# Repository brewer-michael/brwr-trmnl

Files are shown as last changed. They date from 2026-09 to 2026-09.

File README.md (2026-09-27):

# brwr-trmnl

**A 10.3" e-paper display for the fridge door, run by Home Assistant. Say
"show the calendar on the fridge" to your voice speaker, and it does.**

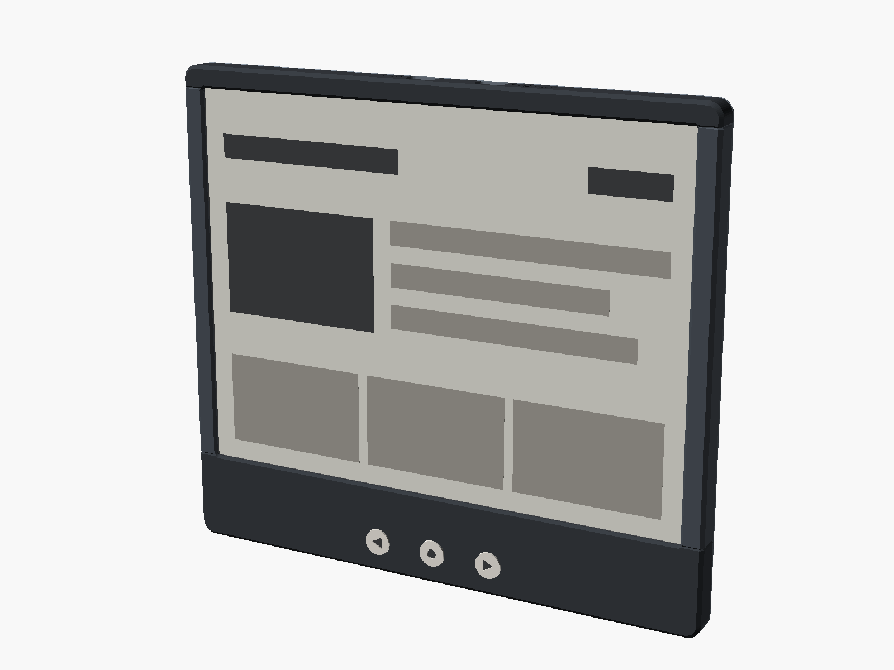
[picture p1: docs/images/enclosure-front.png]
Render of the brwr-trmnl enclosure: a 10.3-inch e-paper panel in a printed frame with three buttons below it


[TRMNL](https://trmnl.com) makes calm, low-power e-paper displays and
publishes its [firmware](https://github.com/usetrmnl/trmnl-firmware) and
[server API](https://docs.trmnl.com/go/diy/byos) so you can build and host
your own. brwr-trmnl is the large-format version (the TRMNL X's panel size
and resolution) built from parts you can buy anywhere, in a 13 mm thin
3D-printed frame that holds onto the fridge with magnets. Its firmware has Home Assistant
built in, so your screens and commands stay on your own network. (It does
reach a public time server to set its clock, unless you point the setup
page's NTP server field at a local one.)

- **10.3", 1872 × 1404, 16 grays.** Sharp enough for small text,
  calendars and graphs at 227 dpi.
- **Three buttons, no touchscreen:** back, refresh and next, like a TRMNL.
  Presses are also Home Assistant triggers.
- **Lives on the fridge.** Four magnets hidden in the back, steel-backed,
  placed and checked so their field stays clear of the electronics
  ([magnets.md](docs/magnets.md)). Or stand it on a desk, or hang it on a
  steel plate on the wall.
- **13 mm thin** (the TRMNL X is 12), stiffened by epoxied steel rods, and
  it prints on a 220 × 220 mm bed.
- **Home Assistant built in.** One setup page. It appears as an MQTT device
  with its battery, what's on screen, a screen picker and settings.
- **Voice.** Any Home Assistant voice satellite (the open speaker, a Voice
  PE, your phone) can put a screen or a note on the fridge.
- **Your screens:** Home Assistant dashboards rendered for e-paper, or
  TRMNL's plugins and playlists from the self-hosted
  [Terminus](https://github.com/usetrmnl/terminus) server. No cloud account.
- **Weeks to months per charge** (estimated), depending on how quickly you
  want it to react ([power.md](docs/power.md)). USB-C charging.
- **About $240 in parts,** $157 of it the display.

## How it works

```
 Voice speaker ──► Home Assistant ─────────────────────────────┐
 "show the         Assist → script → MQTT                      │ MQTT: commands, settings
  calendar on      TRMNL HA add-on: dashboards → 16-gray PNG   │ ◄── state, battery, buttons
  the fridge"      Terminus add-on: TRMNL plugins, playlists   │
                          │ image                              │
                          ▼                                    ▼
                   brwr-trmnl: XIAO ESP32-S3 ──► IT8951 HAT ──► 10.3" e-paper
                   (sleeps between refreshes; the panel's supply is switched off)
```

The brain is an ESP32-S3 (a Seeed XIAO ESP32-S3), the same chip as in the
TRMNL X. The 10.3" panel comes as a kit with Waveshare's IT8951 driver
board, which is shaped as a Raspberry Pi "HAT", but there's no Pi here: the
driver is only the panel's controller and power supply, and the ESP32-S3
talks to it over SPI. (The TRMNL X drives its panel directly from the
ESP32-S3 on a custom board instead.)

Each refresh, the display wakes, switches on the 5 V supply to the panel's
IT8951 controller, fetches the current screen, draws it at 16 grays, reports
to Home Assistant over MQTT and goes back to sleep. In **Always ready** mode
it stays connected in light sleep between refreshes, so a voice command
is on screen in about 10–15 seconds; in **Deep sleep** it only checks in when
it wakes, and the battery should last months.

## Build one

| | |
|---|---|
| [Bill of materials](docs/bom.md) | Parts, suppliers and prices ([CSV](hardware/bom.csv)) |
| [Build guide](docs/build-guide.md) | Printing, soldering, flashing and assembly, step by step |
| [Wiring](hardware/wiring.md) | Pin map, [schematic](docs/images/schematic.svg), [wiring](docs/images/wiring.svg), [carrier board](docs/images/carrier-layout.svg) and [button board](docs/images/button-board.svg) layouts |
| [Enclosure](hardware/enclosure/README.md) | Parametric OpenSCAD frame, 229 × 204 × 13 mm, in four print jobs on a 220 × 220 mm bed: STLs, print settings, rod cut list, desk stand |
| [Magnets](docs/magnets.md) | Holding force, and why the magnets don't disturb the electronics |
| [Power](docs/power.md) | Battery life, power modes, charging |
| [Home Assistant](docs/home-assistant.md) | Add-ons, setup, entities, screens, MQTT topics |
| [Voice](docs/voice.md) | Voice commands through Home Assistant Assist |

## Buttons

| | TRMNL server | Home Assistant screens |
|---|---|---|
| **BACK** | The previous image (from the display's cache, instant) | The previous screen |
| **REFRESH** | Fetch now (the playlist moves on) | Redraw the current screen |
| **NEXT** | The next playlist item | The next screen |
| **REFRESH** double press | TRMNL's special function | — |
| Any button, long press (1–5 s) | Only a Home Assistant trigger, for your own automations | same |
| **REFRESH**, hold 5 s | Setup hotspot, for Wi-Fi and Home Assistant. It forgets the saved Wi-Fi, so you pick it again; the other settings stay | same |
| **REFRESH**, hold 15 s (let go within 30 s) | Reset: forget Wi-Fi, the server and the Home Assistant connection. Set it up again with the same broker and the settings you made in Home Assistant come back | same |

Short and double presses also reach Home Assistant as triggers. Set
**Buttons** to *Home Assistant only* and every press is yours to automate
(setup and reset still work). In **Deep sleep**, though, any press also
wakes the display, which then refreshes as it would on its timer. A button
held down for more than 30 seconds counts as stuck: it's ignored, stops
waking the display, and shows up as **Last error** in Home Assistant until
the first refresh after it's released.

## Firmware

A fork of [usetrmnl/trmnl-firmware](https://github.com/usetrmnl/trmnl-firmware),
imported into [`firmware/`](firmware/) with `git subtree`. The changes are
listed in [`firmware/BRWR.md`](firmware/BRWR.md). In short:

- a `brwr_trmnl` board for the XIAO ESP32-S3 and the Waveshare IT8951 HAT
  over SPI, using upstream's IT8951 driver for the reTerminal E1003 (the same
  1872 × 1404 panel)
- three buttons, a switched panel supply and a battery voltage reading
- Home Assistant over MQTT: discovery, state, settings, commands, button
  triggers, and **Always ready** light sleep
- Home Assistant screens rendered by the TRMNL HA add-on, as an alternative
  to a TRMNL server
- the Home Assistant fields on the setup page

It still works with TRMNL's cloud or any other TRMNL-compatible server. CI
builds both firmware variants whenever `firmware/` changes. Flash the
`brwr_trmnl` one: its `merged_firmware.bin` goes at `0x0` for the first
flash (it clears saved Wi-Fi and settings); to update, upload with
PlatformIO or write `firmware.bin` at `0x10000`.

```sh
cd firmware
pio run -e brwr_trmnl -t upload
```

## Repository

| Path | |
|---|---|
| [`firmware/`](firmware/) | trmnl-firmware with the `brwr_trmnl` board ([changes](firmware/BRWR.md)) |
| [`homeassistant/`](homeassistant/) | Package (screens, scripts, voice intents), voice sentences, example fridge dashboard |
| [`hardware/enclosure/`](hardware/enclosure/) | OpenSCAD source, export script, STLs |
| [`hardware/diagrams/`](hardware/diagrams/) | Scripts that draw the schematic and wiring diagrams |
| [`hardware/analysis/`](hardware/analysis/) | Magnetic field model behind [magnets.md](docs/magnets.md) |
| [`hardware/bom.csv`](hardware/bom.csv), [`hardware/wiring.md`](hardware/wiring.md) | Parts and wiring |
| [`docs/`](docs/) | Build guide and reference |

## Status

**Designed, not yet built.** What has been checked so far:

- The firmware builds for both variants in CI. It has not run on hardware
  yet.
- The Home Assistant package's templates, and the voice sentences against
  Home Assistant's sentence matcher.
- The enclosure renders, its parts are manifold and fit a 220 × 220 mm bed,
  and its clearances (every layer of the 13 mm stack, the magnets, the rods,
  the antenna's keep-out) are checked by assertions in the OpenSCAD source.
- The magnetic field numbers come from a model of a bare magnet (worse
  than the real, steel-backed one).

The battery life, the IT8951's current draw, the magnets' grip on a real
fridge door, the print tolerances, the heights of the parts on a real HAT,
charger module and MiniBoost, and the length of the kit's 40-pin flat cable
are estimates or unknowns until someone builds one. If you do, please open
an issue with what you find.

## Credits

[TRMNL](https://trmnl.com) for the device, the firmware and the server API;
[Terminus](https://github.com/usetrmnl/terminus) and
[trmnl-home-assistant](https://github.com/usetrmnl/trmnl-home-assistant) for
the self-hosted server and the Home Assistant add-ons;
[FastEPD](https://github.com/bitbank2/FastEPD) for the IT8951 driver. This is
an independent project, not affiliated with TRMNL.

## License

GPL-3.0, the same as the TRMNL firmware it's based on. See [LICENSE](LICENSE).

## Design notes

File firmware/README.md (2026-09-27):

# TRMNL Firmware

created for the [TRMNL](https://trmnl.com) e-ink display.

> [!NOTE]
> **brwr-trmnl:** apart from this note, this is TRMNL's own README. For the
> brwr-trmnl board (building, flashing, and what changed) see
> [BRWR.md](BRWR.md). TRMNL's Flash Assistant and released images are built
> for TRMNL's devices, not for this hardware.

> [!IMPORTANT]
> the `main` branch is under constant development and may contain breaking changes. flash at your own risk.
>
> to access production-ready firmware, check out the [tagged releases](https://github.com/usetrmnl/trmnl-firmware/releases/)
 or use the [Flash Assistant](https://trmnl.com/flash).
## **Algorithm block scheme**

```mermaid
graph TB

    Start(["Start"])
    Init("Init peripherals")
    Start --> Init

    IsLongRst{"Reset button
      pressed > 5000 ms?"}
    Init --> IsLongRst

    ClearWifi("Wi-Fi credentials clear")
    IsLongRst -->|"Yes"| ClearWifi
    DisplayInit("Display init")
    IsLongRst -->|"No"| DisplayInit
    ClearWifi --> DisplayInit
    WakeReason{"Wake by
      user or timer?"}
    DisplayInit --> WakeReason

    ClearDisplay("Display clear")
    WakeReason -->|"User"| ClearDisplay
    IsWiFiSetup{"Wi-Fi saved?"}
    WakeReason -->|"Timer"| IsWiFiSetup
    ClearDisplay --> IsWiFiSetup
    NeedConfig("Show set-up message")
    IsWiFiSetup -->|"No"| NeedConfig

    %% Config Wifi
    RunSetup("Start config portal")
    NeedConfig --> RunSetup
    IsReset1{"Device
      reset?"}
    RunSetup -->|"Yes"| IsReset1
    WipeConfig1("API key, friendly ID and WiFi clear")
    IsReset1 -->|"Yes"| WipeConfig1
    Reboot1(["Reboot"])
    WipeConfig1 --> Reboot1
    IsWifiConnect{"WiFi
      connected?"}
    IsReset1 -->|"No"| IsWifiConnect

    %% Main Body
    TryConnect{"WiFi connected
      (5tries)?"}
    IsWiFiSetup -->|"Yes"| TryConnect

    ConnectError("Show connection error")
    IsWifiConnect -->|"No"| ConnectError
    TryConnect -->|"No"| ConnectError
    Sleep1(["Sleep"])
    ConnectError --> Sleep1
    ClockSync("Check synchronization")
    IsWifiConnect -->|"Yes"| ClockSync
    TryConnect -->|"Yes"| ClockSync
    IsApiSetup{"API key and
      friendly ID exist?"}
    ClockSync --> IsApiSetup

    %% Setup
    CallSetup("Ping /api/setup")
    IsApiSetup -->|"No"| CallSetup
    IsSetupSuccess{"Setup
      success?"}
    CallSetup --> IsSetupSuccess
    SetupError("Show setup error")
    IsSetupSuccess --> SetupError
    Sleep2(["Sleep"])
    SetupError --> Sleep2

    %% Check update
    PingServer{"Ping server,
      success?"}
    IsApiSetup -->|"Yes"| PingServer
    IsSetupSuccess -->|"Yes"| PingServer
    PingError("Show server error")
    PingServer -->|"No"| PingError
    Sleep3(["Sleep"])
    PingError --> Sleep3

    %% Act on update
    IsNeedReset{"Need to reset
     the device?"}
    PingServer -->|"Yes"| IsNeedReset
    IsNeedReset -->|"Yes"| WipeConfig1
    IsNeedUpdate{"Need to update?"}
    IsNeedReset -->|"No"| IsNeedUpdate
    IsNeedUpdate -->|"No"| Sleep3
    Update("Download and update")
    IsNeedUpdate -->|"Yes"| Update
    Update --> Sleep3
```

## **Web Server Endpoints**

following Wifi connection via the captive portal, device swaps its Mac Address for an API Key and Friendly ID from the server (which get saved on device).

```curl
GET /api/setup

headers = {
  'ID' => 'XX:XX:XX:XX:XX' # mac address
}

response example (success):
{ "status": 200, "api_key": "2r--SahjsAKCFksVcped2Q", "friendly_id": "917F0B", "image_url": "https://trmnl.com/images/setup/setup-logo.bmp", "filename": "empty_state" }

response example (fail, device with this Mac Address not found)
{ "status" => 404, "api_key" => nil, "friendly_id" => nil, "image_url" => nil, "filename" => nil }
```

assuming the Setup endpoint responded successfully, future requests are made solely for image / display content:

```curl
GET /api/display

headers = {
  'ID' => 'XX:XX:XX:XX',
  'Access-Token' => '2r--SahjsAKCFksVcped2Q',
  'Refresh-Rate' => '1800',
  'Battery-Voltage' => '4.1',
  'FW-Version' => '2.1.3',
  'RSSI' => '-69'
}

response example (success, device found with this access token):
{
  "status"=>0, # will be 202 if no user_id is attached to device
  "image_url"=>"https://trmnl.s3.us-east-2.amazonaws.com/path-to-img.bmp",
  "filename"=>"2024-09-20T00:00:00",
  "update_firmware"=>false,
  "firmware_url"=>nil,
  "refresh_rate"=>"1800",
  "reset_firmware"=>false
}

response example (success, device found AND needs soft reset):
{
 "status"=>0,
 "image_url"=>"https://trmnl.s3.us-east-2.amazonaws.com/path-to-img.bmp",
 "filename"=>"name-of-img.bmp",
 "update_firmware"=>false,
 "firmware_url"=>nil,
 "refresh_rate"=>"1800",
 "reset_firmware"=>true
}

response example (success, device found AND needs firmware update):
{
 "status"=>0,
 "image_url"=>"https://trmnl.s3.us-east-2.amazonaws.com/path-to-img.bmp",
 "filename"=>"name-of-img.bmp",
 "update_firmware"=>true,
 "firmware_url"=>"https://trmnl.s3.us-east-2.amazonaws.com/path-to-firmware.bin",
 "refresh_rate"=>"1800",
 "reset_firmware"=>false
}

response example (fail, device not found for this access token):
{"status"=>500, "error"=>"Device not found"}

if 'FW-Version' header != web server `Setting.firmware_download_url`, server will include absolute URL from which to download firmware.
```

if device detects an issue with response data from the `api/display` endpoint, logs are sent to server.

```curl
POST /api/log

# example request tbd
```

## **Power consumption**

A bit of background first. The ESP32-C3 inside the TRMNL OG is one of Espressif's newer, more efficient microcontrollers. For battery powered applications, it's designed to be put to sleep to conserve power when your project doesn't need it to be active. There are two sleep modes - light and deep. Deep sleep conserves the most power, but at the cost of losing the contents of the main memory. The lowest possible power consumption is about 4uA @ 3V with a timed wakeup, but TRMNL needs to be able to wake up with a button press. Keeping the GPIO active during deep sleep (to detect the button press) uses about 100uA on average (see power profile below). This means that a 2500mAh battery could theoretically keep the TRMNL powered in this state for approximately 25,000 hours.

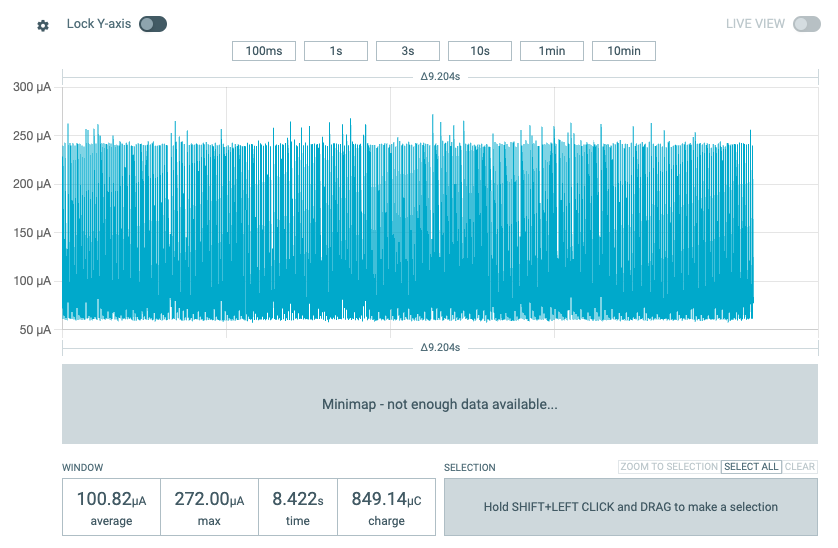
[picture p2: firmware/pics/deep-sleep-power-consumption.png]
TRMNL deep sleep power consumption


Of course its not very useful to have a device that's permanently sleeping, so shown below is the power profile of TRMNL doing a normal display update (timed wake up, send device status, fetch new image, show it on the e-paper display):

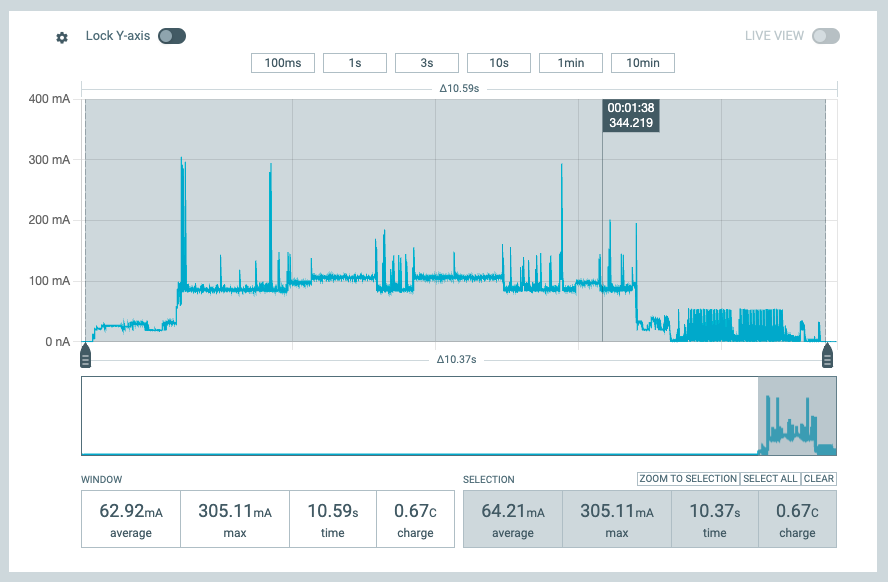
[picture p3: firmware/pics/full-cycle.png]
TRMNL device full cycle power consumption


The peaks and valleys you see above represent the variation in electrical current (power) drawn by the ESP32-C3 at different points during the ~10.5 second update cycle. The majority of energy is used while WiFi is active (between the 3 and 9 second marks). The last portion of the graph with higher frequency peaks is from the e-paper display cycling through its update (average power is quite low). The total electrical charge needed for the update is shown in the lower right corner (0.67c). This value is in Coulombs and represents the number of electrons that have moved through the circuit.

0.67 C = 0.186111 mAh

If we ignore the ESP32 sleep periods, the energy used in each display update would allow 2500/0.186111 = 13433 updates. If we configure our TRMNL account to update the information every 15 minutes, we'll be requesting 96 updates per day and the battery charge could last for 140 days (13433 / 96). This isn't too far off from real world results. The battery voltage will drop below a safe threshold before it has released its full energy and in the equation above, we haven't counted the energy used during the sleep periods nor the energy lost in the TRMNL's power supply (between the battery and the ESP32). The real world result will be closer to 120 days on a full charge.

We can extend the battery life further by disabling updates during our sleeping hours. In the TRMNL web portal there is a setting for “Sleep Mode” (see screenshot below):

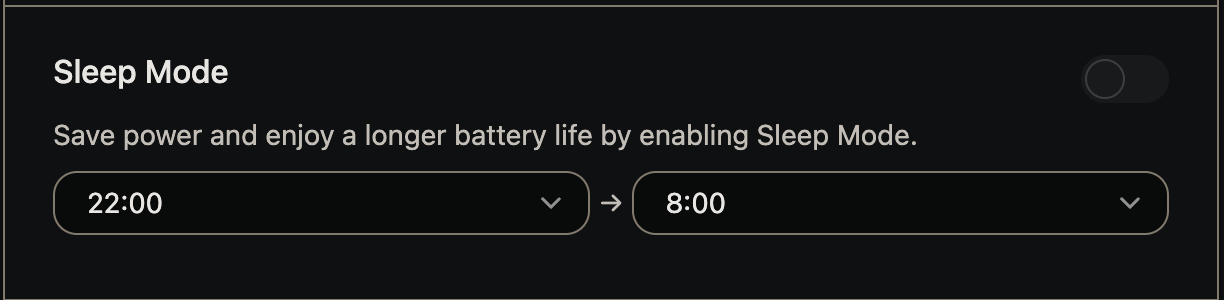
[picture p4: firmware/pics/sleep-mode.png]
TRMNL sleep mode


For example - by reducing the total active time each day by 8 hours, the number of updates per day (set to a 15-minute interval like above) changes from 96 to 64. With sleep mode set to 8 hours, our battery life is extended:

13433 / 64 = 210 days (theoretical maximum)

**Designed for Efficiency**

Lithium batteries deliver between 3.7 and 4.2 volts depending on their charge state. The ESP32 operates between 2.8V and 3.3V. In order to power the ESP32 from the battery, the voltage needs to be reduced.

There are two main types of power regulators - [buck](https://en.wikipedia.org/wiki/Buck_converter) converters, and [linear](https://en.wikipedia.org/wiki/Linear_regulator) regulators. Many ESP32 products use linear regulators since they are less expensive. This savings comes at a cost - they throw away up to 20% of the battery's energy as waste heat. Your TRMNL was designed with a buck converter to safely and efficiently power the ESP32. This ensures the best use of the battery's energy. At TRMNL we are always looking for additional software optimizations that improve battery life.

## **Low Battery Level**

Lithium ion batteries are ubiquitous in our lives; they're in nearly everyone's pocket/purse and many other devices you use daily. They bring a host of benefits, some risks and require care to keep them working at their best. Your TRMNL protects the battery against overcharging, but your help is needed to prevent problems when the battery is low. There are two main problems that arise with dead Li-Ion batteries:

1. If they pass below a certain voltage, they need to be recharged with a special trickle charger; the charging circuit of the TRMNL won't be able to charge them.
2. Batteries that are left uncharged for an extended period of time can “outgas”. This means that the electrolyte goes through a chemical reaction and releases hydrogen gas. You may have seen batteries in this state - the metal envelope puffs up like a balloon.

The conditions above are to be avoided, but `#2` can be dangerous as well. If your battery is puffy, dispose of it safely at a local recycling spot and contact TRMNL support to get a new one.

Even when your TRMNL is disconnected (power switch in the off position), its battery will slowly self-discharge. To keep your TRMNL's battery running at peak performance:
1. Charge your device immediately when the low battery image is shown.
2. If you've switched off your TRMNL for storage/moving, ensure the battery is not already low.

## **Version Log**

See [releases](https://github.com/usetrmnl/firmware/releases). For older versions go [here](https://github.com/usetrmnl/firmware/issues/95).

## **Compilation guide**

There are technical and non-technical options to flashing firmware.

### **No code required**

* Flash directly from a web browser: https://trmnl.com/flash
* Enable OTA updates from your TRMNL dashboard > Device settings (native hardware only)

### **Via CLI**
1. To build the binary run `pio run -e TRMNL_X_dev`
2. To upload the binary to the device `pio run -e TRMNL_X_dev -t upload`
3. If PlatformIO uses the wrong port use this
```bash
pio device list # make sure JTAG device is visible
pio run -e TRMNL_X_dev -t upload --upload-port /dev/cu.usbmodem1234
```
4. view serial monitor by
```bash
pio device monitor -e TRMNL_X_dev
pio device monitor -e trmnl
```

When switching between TRMNL X and OG/BWRY, run `pio pkg install` once for the environment you are about to build (use the same `-e` value as `pio run`):

```bash
pio pkg install -e TRMNL_X_dev   # TRMNL X
pio pkg install -e trmnl         # TRMNL OG
pio pkg install -e trmnl_4clr    # TRMNL BWRY
```

If you skip this step, the build may fail with `Error: Missing Arduino framework directory 'None'`.

### **Using VSCode plugin**

1. Install VS Code: https://code.visualstudio.com
2. Install PlatformIO: https://platformio.org/install/ide?install=vscode
3. Install Git: https://git-scm.com/book/en/v2/Appendix-A%3A-Git-in-Other-Environments-Git-in-Visual-Studio-Code
4. Clone this repository: https://github.com/usetrmnl/trmnl-firmware
5. Open project in VS Code workspace
6. After configuring the project, click the PlatformIO -> Build button located at the bottom of the screen

Image Alt text Build

7. After the compilation process is complete, you should expect to see a message in the console.

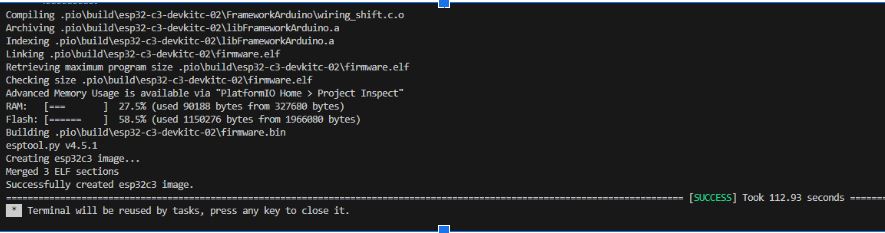
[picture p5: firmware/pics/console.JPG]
Image Alt text Console


8. You can find the compiled file in the folder shown in the picture.

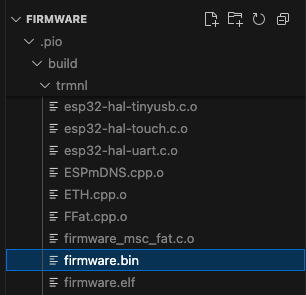
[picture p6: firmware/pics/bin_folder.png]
Image Alt text Bin


## **Uploading guide (PlatformIO)**

1. Put the TRMNL into flashing mode.

    1. **TRMNL OG and BWRY**: Turn off PCB. Connect PCB to PC using USB-C cable. While holding down the boot button, turn on PCB. Let go of boot button. This puts board in flashing mode.
    2. **TRMNL X**: [See these instructions](https://help.trmnl.com/en/articles/11936721-put-your-trmnl-in-flashing-mode#h_96e07a072e)

2. Mac/Windows: Select the proper COM port from drop-down list (or leave on "Auto"). Ubuntu: Look for something like "/dev/ttyACMO USB JTAG/serial debug unit" or "Espressif USB JTAG/serial debug unit" via lsusb.

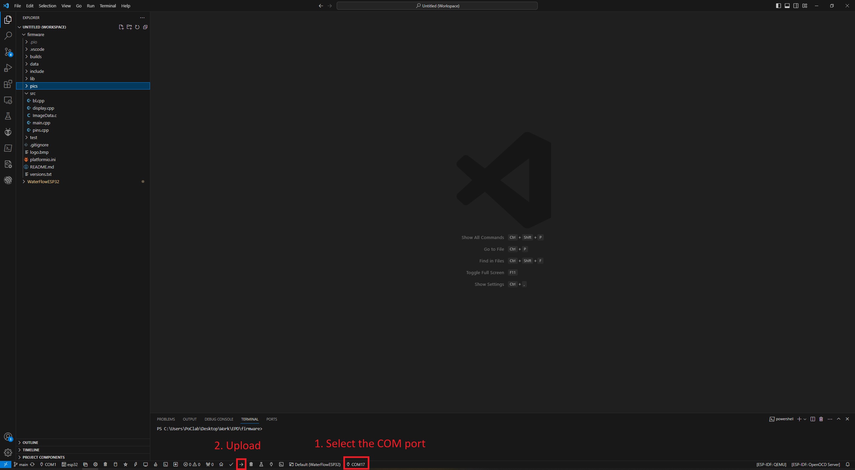
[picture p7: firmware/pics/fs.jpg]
Image Alt text FS


3. Click on "PlatformIO: Upload" button.

## **Uploading guide (ESP32 Flash Download Tool)**

Tools required:

1. Windows OS
2. Flash Tool 3.9.5
3. Binaries to merge - `bootloader.bin`, `firmware.bin`, `partitions.bin` (see Compilation Guide above)
4. Bootloader binary file (`boot_app0.bin`, found in ~/.platformio/packages/framework-arduinoespressif32/tools/partitions/)

### Step 1 - Configure flash tool
open the Flash Tool (executable file), select these parameters, then click OK:

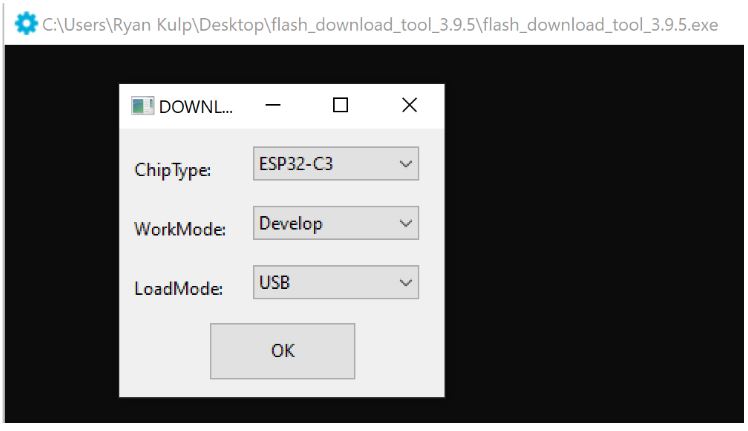
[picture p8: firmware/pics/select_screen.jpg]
Image Alt text select screen


### Step 2 - Add binaries
1. Beside the top blank space, click “...” dots and select the bootloader binary file then input
> “0x00000000”
in the far right space and check the box.

2. Click “...” dots and select the partitions binary file then input
> “0x00008000”
in the far right space and check the box.

3. Click “...” dots and select the boot_app0 binary file then input
> “0x0000e000”
in the far right space and check the box.

4. Click “...” dots and select the firmware binary file then input
> “0x00010000”
in the far right space and check the box.

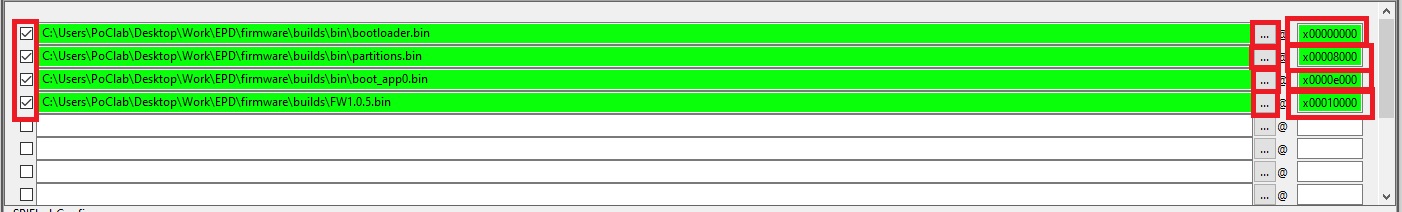
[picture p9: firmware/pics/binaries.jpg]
Image Alt text binaries


finally, set the following parameters at the bottom of the Flash Tool interface:

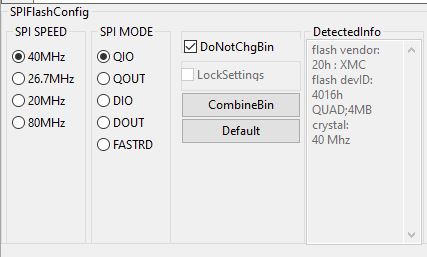
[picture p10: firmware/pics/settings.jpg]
Image Alt text settings


### Step 3 - Connect and flash device
1. Open the Windows “Device Manager” program and scroll to the bottom where the USB devices can be found. each machine will have different available devices, but look for a section like this:

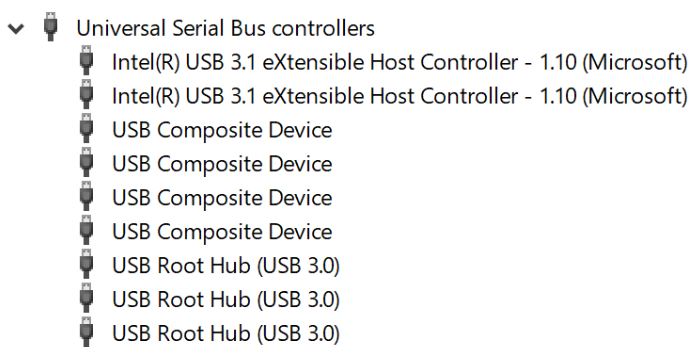
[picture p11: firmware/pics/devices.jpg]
Image Alt text devices


2. Next, connect the PCB to the Windows machine with a USB-C cable. make sure the USB port is on the right, and that the PCB’s on/off switch is toggled DOWN for “off.”

3. While holding the BOOT button (below the on/off toggle), toggle the device ON by flipping the above switch UP. you may hear a sound from your Windows machine Inspect the Device Manager connections at the bottom of the interface, and a new device should appear. it may be “USB Component {{ Num }},” or something like below:

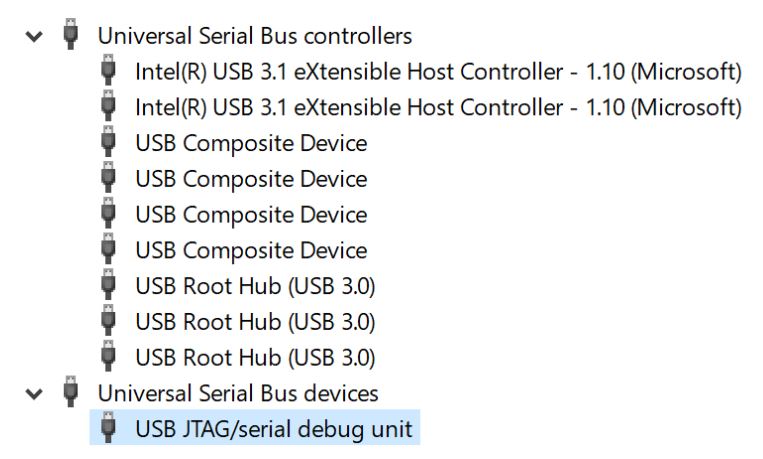
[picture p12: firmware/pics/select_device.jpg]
Image Alt text select_device


4. Take note of this device’s name, that is our TRMNL PCB. then back inside the Flash Tool, click to open the “COM” dropdown in the bottom right and choose the TRMNL PCB. finally, click the “START” button.

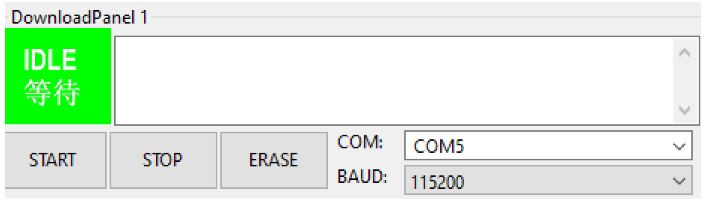
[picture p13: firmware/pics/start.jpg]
Image Alt text start


### Step 4 - Prepare for new device flashing
Inside the Flash Tool click the “STOP” button.

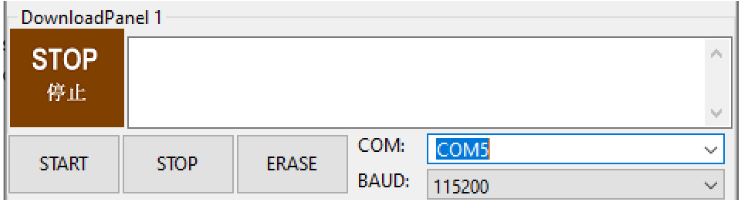
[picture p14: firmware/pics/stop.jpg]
Image Alt text stop


Next turn off (toggle DOWN) and unplug the PCB. you are now ready to flash another device - see Step 1.

## **Hacking guide**

### Local unit tests

If you would like to run local tests, you'll need to have g++/gcc installed (f.e., as part of MinGW) in PATH:

- Get MinGW online installer from https://github.com/niXman/mingw-builds-binaries/
- Add path to `bin` from installed folder (f.e. `c:\mingw64\bin`) to your PATH
- Restart Visual Studio Code

Now you can switch from "env:esp32..." to "esp:native" clicking at the bottom of the studio (point 1):



And then run platformio tests by clicking test button (point 2).

### Hardware integration tests

There is a suite of on-device hardware tests written with the [Unity](https://registry.platformio.org/libraries/throwtheswitch/Unity) test framework, defined in `test/integration/test_all`. They compile into a single firmware image that is uploaded to the device, runs the tests sequentially in `setup()`, and prints results over the serial port.

To run the test suite (currently only on OG):

1. Make a copy of `test/integration/test_config.h.example` to `test/integration/test_config.h` and modify the file as needed to set up the WiFi network and other values. This file is ignored by Git and will not be checked in.
2. Select the `env:trmnl_test` environment.
3. Plug in the device and run the "PlatformIO: Test" action.
    1. If the upload fails, retry the Test action once.
    2. If the upload still fails, ensure the device is on.
    3. If the upload still fails, put the device into flashing mode - see "Uploading guide (PlatformIO)" above, and retry.

You should see terminal output like:

```
test/integration/test_all/all.test.cpp:33: connect_to_wifi      [PASSED]
test/integration/test_all/all.test.cpp:75: test_setup_succeeds_with_registered_mac      [PASSED]
test/integration/test_all/all.test.cpp:76: test_setup_returns_status_error_for_unknown_mac      [PASSED]
test/integration/test_all/all.test.cpp:77: test_setup_fails_with_unreachable_host       [PASSED]
test/integration/test_all/all.test.cpp:97: test_low_battery_returns_low_battery_image   [PASSED]
test/integration/test_all/all.test.cpp:63: test_wifi_connects_with_valid_credentials    [PASSED]
test/integration/test_all/all.test.cpp:64: test_wifi_fails_with_wrong_password  [PASSED]
test/integration/test_all/all.test.cpp:65: test_wifi_fails_with_wrong_ssid      [PASSED]
---------------------------------------------------------------------------- trmnl_test:integration/test_all [PASSED] Took 56.49 seconds ----------------------------------------------------------------------------

====================================================================================================== SUMMARY ======================================================================================================
Environment    Test                  Status    Duration
-------------  --------------------  --------  ------------
trmnl_test     integration/test_all  PASSED    00:00:56.488
```

## Code Formatting

We use `clang-format` for formatting C/C++ source files. You can install it [via Homebrew](https://formulae.brew.sh/formula/clang-format) or your package manager of choice - it's part of `llvm`.

Two ways to format files:

1. Run `./scripts/format.sh` to format the entire repository.
2. VS Code users: install [the C/C++ extension](https://marketplace.visualstudio.com/items?itemName=ms-vscode.cpptools) which will automatically format-on-save using clang-format.

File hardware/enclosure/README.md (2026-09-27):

# brwr-trmnl enclosure

A thin printed frame for the 10.3" panel: 229 × 204 × 13 mm, plus the 1 mm
rubber pads on the back and caps 0.5 mm proud. The **bezel** holds the front
face, walls, panel pocket and buttons. The **back cover** carries the
electronics, the ribs that press the panel forward and four N52 disc magnets
sealed inside it. Steel rods epoxied into printed channels stiffen the thin
frame and splice the split parts. The frame sticks to a fridge door, to a
steel plate on a wall, or leans back 15° in the optional desk stand.

| Front | Back |
|---|---|
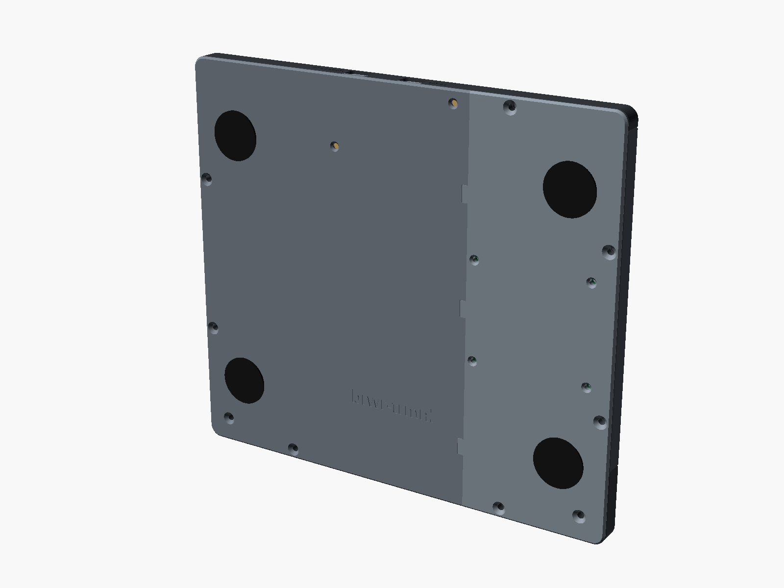
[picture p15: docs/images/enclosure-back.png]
Back
| Front |  |
| **Exploded** | **Inside, back cover removed (seen from behind, so left and right are swapped)** |
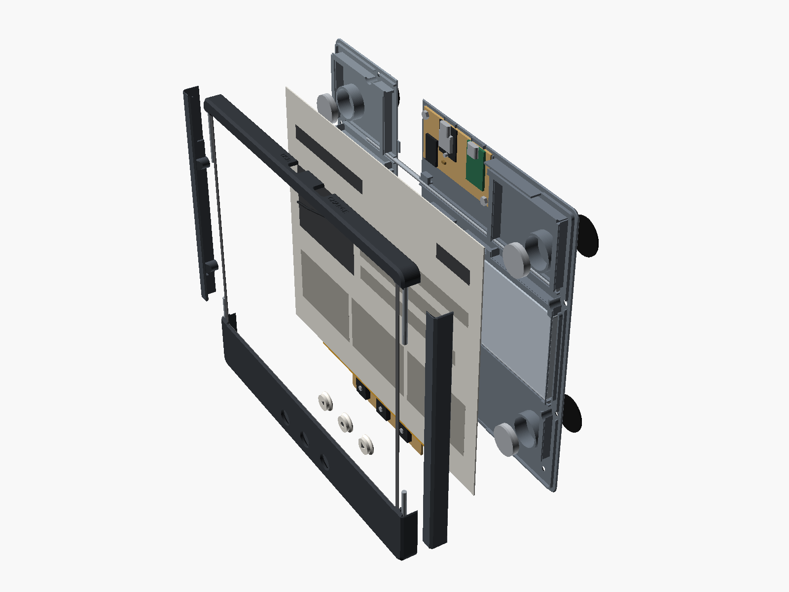
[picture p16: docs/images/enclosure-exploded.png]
Exploded
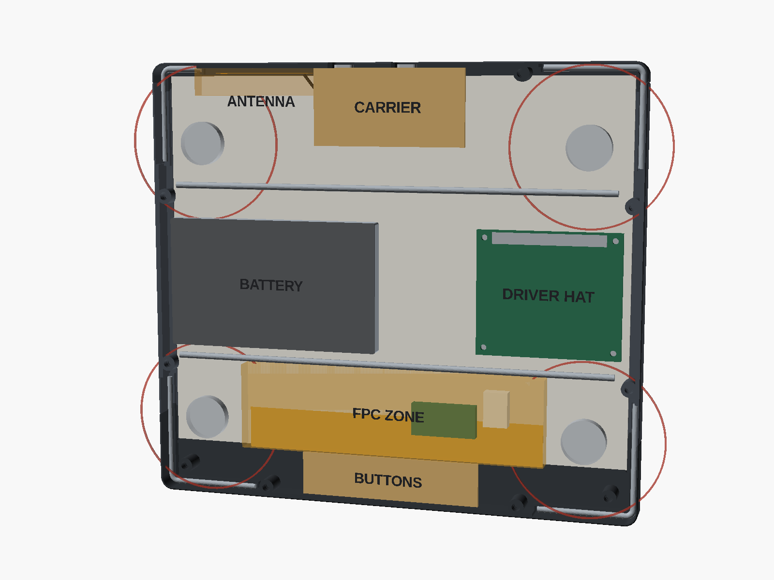
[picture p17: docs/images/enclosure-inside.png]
Inside
|  |  |

The whole design is one parametric file, [`brwr-trmnl.scad`](brwr-trmnl.scad).
Running [`./export.sh`](export.sh) renders the STLs into `stl/` and these
pictures into `docs/images/`. It stops on any OpenSCAD warning, including a
failed design-rule check. It also stops on any STL that, once vertices closer
than 1e-4 mm are merged the way a slicer does, has an edge not shared by
exactly two triangles or a degenerate triangle.

## Parts

By default every part fits a **220 × 220 mm bed** (FlashForge Adventurer 5M)
with 5 mm margins. The bezel comes in four rails that meet at the window
corners. The back cover splits at X = −39.

| Part | File | Print orientation | Footprint on the bed | Size as printed | Mass |
|---|---|---|---|---|---|
| Top rail | `stl/bezel_top.stl` | front face down, turned 45° | 168 × 168 mm | 166 × 166 × 11.2 mm | ~10 g |
| Chin (bottom rail) | `stl/bezel_bottom.stl` | front face down, turned 45° | 188 × 188 mm | 186 × 186 × 11.2 mm | ~25 g |
| Left and right rails | `stl/bezel_left.stl`, `stl/bezel_right.stl` | front face down | 9.3 × 158 mm | 9.2 × 157.6 × 11.2 mm | ~8 g each |
| Back cover, left | `stl/back_left.stl` | outside face down | 77.5 × 204 mm | 77.5 × 204 × 9.4 mm | ~42 g |
| Back cover, right | `stl/back_right.stl` | outside face down | 154.5 × 204 mm | 154.5 × 204 × 10.0 mm (the antenna fin) | ~67 g |
| Button caps (3) | `stl/button_caps.stl` | face down | 48 × 13 mm | 48.2 × 13.4 × 4.1 mm | ~2 g |
| Desk stand (optional) | `stl/stand.stl` | base down | 100 × 79 mm | 100 × 78.8 × 73.6 mm | ~70 g |

The STLs are already in print orientation, including the 45° turn. The
footprint is what the bed-fit check measures: the rails' rounded outline,
turned. The model refuses a part that does not fit `bed_size` minus
`bed_margin`.

For a bed of **250 × 210 mm or more**, print the one-piece bezel and back
cover instead: `stl/one-piece/bezel.stl` (229 × 204 × 11.2 mm, ~51 g) and
`stl/one-piece/back.stl` (229 × 204 × 10.0 mm, ~109 g). `export.sh` renders them
with `split = false`. They carry the same grooves, bosses and rod channels.

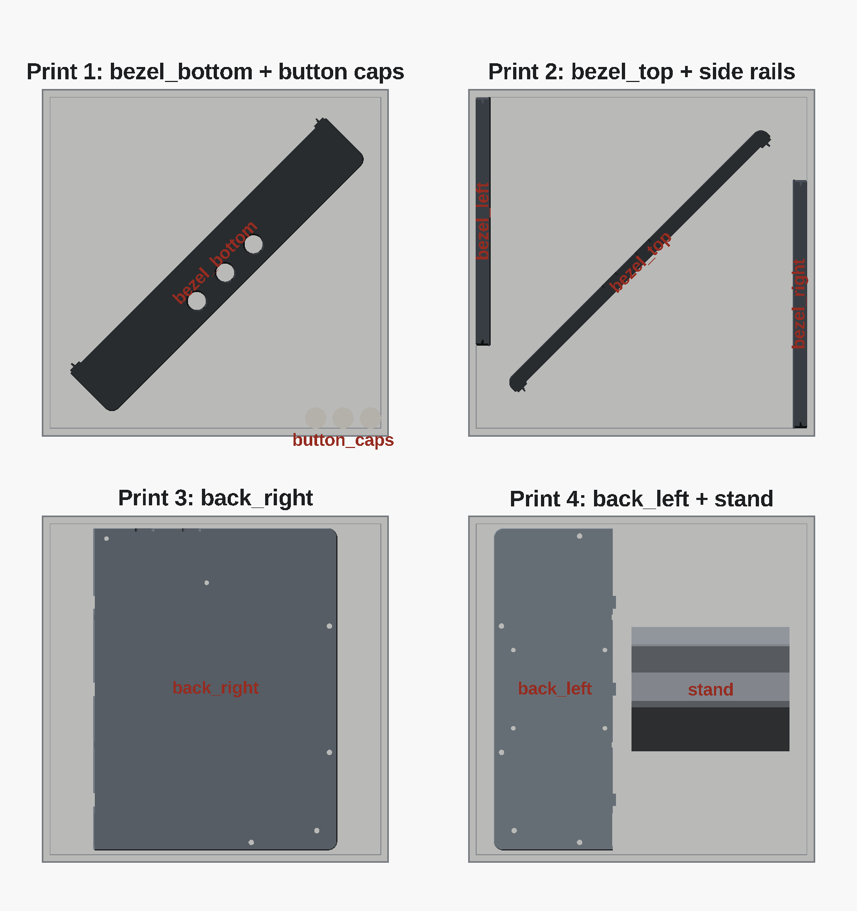
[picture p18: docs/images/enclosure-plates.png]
Print jobs


Four print jobs on a 220 × 220 bed:

1. `bezel_bottom`, turned 45°, and the button caps
2. `bezel_top`, turned 45°, with `bezel_left` and `bezel_right`
3. `back_right`
4. `back_left` and the stand

Print in **PETG with 0.2 mm layers, 3–4 walls and 20 % infill, with no
supports**. Every overhang is 45° or bridged. That includes the rail scarfs,
the 45° fronts of the bosses behind the panel, the tab pockets and the cap
flanges. The bezel parts print on their front face, so use the sheet whose
finish you want on the front.

Masses are for PETG at 1.27 g/cm³: the STL volume, with a 1.2 mm solid shell
on every surface and 20 % infill inside it. At 13 mm deep everything is thin
wall, so it prints almost solid.

## Hardware

- **Screws**
  - 9 × M3 heat-set inserts, 4 mm long (hole Ø4.0 × 4 mm), in the bezel.
    Use 9 × M3 × 6 countersunk screws (ISO 10642) through the back cover.
  - 4 × M2.5 × 8 countersunk screws and 4 × M2.5 nuts for the driver HAT.
    The screws go in from outside, the nuts sit on the component side.
  - 2 × M2.5 × 6 countersunk screws and 2 × M2.5 nuts for the carrier board.
  - 2 × M2.5 heat-set inserts (hole Ø3.6 × 4.2 mm) behind the chin and
    2 × M2.5 × 5 pan-head screws for the button strip.
- **Magnets**
  - 4 × N52 disc magnets, 20 × 3 mm
  - 4 × steel discs, 20 × 1.5 mm
  - 2-part epoxy
  - 4 × self-adhesive rubber pads, Ø25 × 1 mm
- **Steel:** about 0.75 m of 3 mm mild steel rod (see the cut list below).
- **Switches:** 3 × Omron B3F-4000 (12 × 12 × 4.3 mm, flat plunger) on an
  84 × 20 mm protoboard strip, 25.4 mm (10 holes) apart.
- **Button lead plug:** a pre-wired 4-pin JST-PH pair, inline in the button
  lead, so the frame and the back cover come apart. It lies flat on the back
  cover beside the adapter board, centred at (−50, −53) (`btn_plug_pos`), and
  the clash check includes it.
- **Antenna:** Taoglas FXP831 (45 × 7 mm FPC, 100 mm of 1.37 mm coax, U.FL),
  on a fin on the back cover.
- **Foam:**
  - a 0.5 mm gasket on the window lip
  - 1 mm × 4 mm strips on the rib tops and the magnet tubes
  - a 0.5 mm pad under the battery
- **Zip ties:** 2.5 mm, for the button wires, through the three tie blocks at
  X = −30.
- **Glue (optional):** for the rail joints and the back seam. Use epoxy, or CA
  with a primer made for PETG.

### Steel rod cut list

| Rod | Shape | Straight lengths (mm) | Cut length |
|---|---|---|---|
| Back cover, upper (Y = 45.5) | straight | 206 | 206 mm |
| Back cover, lower (Y = −35.3) | straight | 206 | 206 mm |
| Bezel, top-left | L | 40 along the top wall + 40 down the side wall | 85 mm |
| Bezel, top-right | L | 15.5 along the top wall + 40 down the side wall | 61 mm |
| Bezel, bottom-left and bottom-right (2) | L | 40 along the bottom wall + 48 up the side wall | 93 mm each |

The bezel grooves follow the frame's rounded corner. Bend the L-rods 90° with
an inside radius of 1.3–1.9 mm, for example over a Ø3 mm pin in a vise. The
top-right rod's top leg is short so it stays 10 mm from the antenna. The
console prints this list (`CUT` lines) and asserts the rod rules:

- at least 8 mm from each rod to a magnet's edge (the upper back rod sits at
  exactly 8 mm)
- at least 10 mm to the antenna
- nothing in the flex zone (1.6 mm to spare)

## Z stack-up at 13 mm

Z is measured from the back face (the fridge side). These are the tightest
spots. The console prints them as `STACK` lines.

| Spot | Layers, Z in mm | Margin |
|---|---|---|
| Panel | front plate 11.4–13, gasket 10.9–11.4, panel 10.12–10.9, rib tops 9.42 plus 0.7 mm of squeezed foam | – |
| Carrier | recess floor 0–0.6, solder joints 0.6–1.8, board 1.8–3.4, MiniBoost (5.6 mm, the tallest part) to 9.0 | 1.12 mm to the panel |
| Driver HAT | plate 0–1.8, clipped header pins 2.3–3.3, standoffs to 3.3, board 3.3–4.9, parts and nuts to 7.9, screw tips at 8.0 | 2.22 mm to the panel |
| Battery | recess floor 0–0.6, foam 0.6–1.1, cell 1.1–7.1 | 2.32 mm to the rib tops |
| Buttons | recess floor 0–1.0, joints 1.3–3.3, strip 3.3–4.9, switch body to 8.4, plunger to 9.2, 0.2 mm gap, cap 9.4–13.5, sleeve 10.2–11.4 | 0.3 mm above the recess floor; the switch clicks after 0.45 mm with the cap face 0.05 mm proud |
| Magnets | skin 0–0.6, magnet 0.6–3.6, steel disc 3.6–5.1, epoxy to 5.4, tube to 9.42; rubber pad −1–0 | 4.7 mm to the panel |
| USB slots | XIAO centre 6.0 (slot 2.75–9.25), charger centre 6.6 (slot 3.35–9.85) | 1.65 mm below the front chamfer |
| Antenna | 3.0–10.0 on a fin on the back cover, 2.4 mm inside the top wall, X 38–83 | 11.5 mm to the nearest metal part; the carrier board's copper is 3 mm from its end |
| Rods | bezel rods 8.2–11.2, beside the panel edge; back rods 0.8–3.8, a third sunk into the plate | – |

The console also prints what each stack needs as `DEPTH` lines. 13 mm closes.
The smallest depth that closes is **12.88 mm**, set by the carrier: the
MiniBoost, 5.6 mm tall (Adafruit's figure), with 1 mm of air to the panel.
The buttons come next, at 12.6 mm. The model refuses a `depth` that does
not close.

## Assembly

1. **Inserts.** Heat-set the nine M3 inserts into the bezel rails' bosses and
   the two M2.5 inserts into the bosses behind the chin.
2. **Magnets.** In each back-cover pocket, drop in a magnet, lay a steel disc on
   it, and fill with epoxy to just over the disc. Nothing metal shows outside.
   Stick a rubber pad over each pocket on the outside face.
3. **Back cover.** Lay `back_left` and `back_right` outside face down on a flat
   table. Slide the three tabs on `back_left` into the pockets under
   `back_right`, so the scarf closes. Epoxy the two 206 mm rods into their
   channels across the seam; they hold the halves together. Glue on the scarf
   is optional.
4. **Bezel.** Lay the four rails front face down on a flat table and push them
   together at the corners. Each side rail slides in along Y between the top
   rail and the chin. The scarf and the half-lap line up the front faces and
   the pocket ledge. Epoxy the four L-rods into the corner grooves; they bridge
   the joints and are structural. Glue on the joint faces is optional. Let it
   cure flat.
5. **Buttons.** Push the caps in from behind, with the key toward the bottom.
   Then screw the switch strip onto its two bosses (M2.5 × 5).
6. **Panel.** Lay the gasket on the lip and drop the panel in face-down, with
   its flex at the chin. Fold the flex over the back of the panel. The zone
   144 × 40 mm above the panel's bottom edge is kept free of ribs and rods.
7. **Electronics.**
   - **Driver HAT:** remove its 2×20 header, clip the pins flush (≤ 1 mm) and
     remove the tall socket and pin headers. Mount it component side toward
     the panel on its four 1.5 mm standoffs, with M2.5 × 8 countersunk screws
     from outside and nuts on the component side.
   - **Carrier:** trim its joints to 1.2 mm. It rests on the two ledges of its
     recess and is held by M2.5 × 6 countersunk screws from outside, nuts on
     top. Its two holes are drilled 2.7 mm through the middle of the four
     holes in its top-left and bottom-right corners (components facing you),
     so they sit on the protoboard's grid: X ±31.75 mm, 4.15 mm and 32.09 mm
     below the top of its 70 × 35 mm outline. A notch in the left ledge clears
     the MiniBoost's VIN joint.
   - **Battery:** on its foam pad in the cradle recess, lead out through the
     slot toward the middle and through the gap in the rib above, to J1.
   - **Antenna:** stick it to the inner face of the fin along the back
     cover's top edge (X 38–83), and run its coax over the carrier to the
     XIAO's U.FL. It stays connected when the case is opened: only the
     panel's flat cable and the button lead (J4) cross between the halves.
8. **Close up.** Put foam strips on the rib pads and the magnet tubes, plug
   the button lead together and lay its plug flat beside the adapter board,
   tie the button wires up the back at X = −30, and close the case with the
   nine M3 screws. The two tongues on the back cover close the bottom of the USB
   slots.

**On a wall:** the back is too thin for keyholes. Screw a thin steel plate to
the wall, for example 1 mm galvanised steel of about 200 × 150 mm, or four
30 × 30 mm squares at the magnet positions (±90, ±65) from the frame's
centre. The magnets hold the frame on it.

## How the joints go together

- **Rail joints (bezel).**
  - Each joint runs level with the window's top or bottom edge (Y = 92.9 and
    Y = −64.7).
  - On the front it is a short line across the side border. It sits in a
    0.5 mm V-groove that continues over the front chamfer and down the side
    wall, so it reads as a deliberate line.
  - Through the front plate the joint is a 45° scarf. In the side wall, the
    outer half is cut straight and the inner half runs 4 mm further (a
    half-lap).
  - The rails register on each other and every rail prints face-down without
    supports.
  - The L-rods in the wall grooves bridge all four joints. The nearest other
    feature is 2.6 mm from a joint.
- **Back seam (X = −39).**
  - A 45° scarf through the plate, with 0.4 mm lands.
  - Three 2 × 8 × 0.8 mm tabs on `back_left` (at Y = −70, 0 and 55) slide
    into bridged pockets under `back_right`.
  - Both back rods cross the seam.
  - Clearances from the seam: 2.0 mm to the HAT standoffs, 1.5 mm to the HAT
    board edge and its countersinks, 2.4 mm to the carrier tray and 5 mm to
    the tie blocks.

## Changing the main parameters

Open the file in OpenSCAD and use the Customizer. Each dimension has a
comment with its unit and source. The console prints every module's position,
the stack-up, the magnet and rod distances and the rod cut list. The model
also runs `assert()` design rules and stops with a message when one fails.

- **Depth:** `depth`, `front_t` and `back_t`. The `DEPTH` lines say which
  stack sets the minimum.
- **Bed:** `bed_size`, `bed_margin` and `split`. `rail_angle` turns the long
  rails. `plate_layout()` places the parts of each print job and is checked
  for fit and spacing.
- **Magnets:** `mag_d`, `mag_h`, `steel_disc` and `mag_pos`, with one `[X, Y]`
  per magnet; the count is the number of entries. The rules are:
  - every centre is at least `mag_keep_board` (36 mm) from the driver and
    carrier boards, and at least `mag_keep_ant` (30 mm) from the antenna
  - magnets stay out of the flex zone and the battery cradle
- **Rods:** `rod_back_y`, `rod_back_x` and `rod_legs`. The rules are
  `rod_mag_clear`, `rod_ant_clear` and the flex zone.
- **Battery:** `bat_size = [L, W, T]` in landscape, and `bat_pos` for its
  centre.
- **Button feel:** `cap_preload` defaults to −0.2 mm, a free gap above the
  plunger, because the switch only travels 0.25 mm. Raise it toward 0 if the
  caps rattle. Lower it if a switch clicks by itself when the case is closed.

Use `part = "fit_check"` to see all module envelopes and rods inside a
see-through case. Use `part = "clash"` to render every overlap between two
printed parts, or between a printed part and a module's envelope or a rod.
It is empty when everything fits, and OpenSCAD reports "top level object is
empty". Modules aren't checked against each other, and cables aren't
modelled, apart from the antenna's coax (for its length) and the button
lead's plug.

Coordinates follow the front view: X and Y are measured from the centre of the
outline (+X right, +Y up). Z is measured from the back face (the fridge side)
toward the front.

## Differences from the brief

- **Depth is 13 mm.** The first pass was 25 mm deep. The HAT lost its header,
  the carrier went low-profile and the switches went flat (see the stack-up).
- **9 M3 screws, not 10.** The L-rods take the corners of the top rail and the
  chin. There are only 3.35 mm between the pocket and the wall there, which is
  no room for both a rod and an insert.
  - The chin's corner screws moved in to (±101.5, −89.5).
  - The top rail has one screw at (−60, 97). There is none at the top right,
    because of the antenna keep-out.
  - The epoxied L-rods hold the top rail's corners.
- **The upper back rod is at Y = 45.5, not 46.** That keeps 8 mm from the rod
  surface to the magnet edge. The lower rod is at −35.3, centred between the
  battery cradle and the flex zone.
- **Two L-rods have different legs.** The top-right rod's top leg is 15.5 mm,
  to keep 10 mm from the antenna. The bottom rods' side legs are 48 mm, so they
  reach 17 mm past the joint.
- **The rod grooves are cut into the walls.** Along each bezel rod the wall is
  a 1 mm skin, and 0.5 mm under the joint's V-groove.
- **Some ribs changed.**
  - The rib at Y = −35 is gone; the lower rod runs there.
  - The bottom perimeter ribs are gone. The magnet tubes run up to the rib
    tops and carry foam instead.
  - The perimeter ribs moved 2.7 mm inside the panel edge to clear the rod
    grooves.
- **The M3 bosses reach under the panel's edge.** There they end
  0.3 mm behind the panel with a 45° front, so they print without supports.
- **The window chamfer is 1.1 mm,** to fit the 1.6 mm front plate.
- **The USB labels sit beside the slots.** There is no room above them in a
  13 mm wall.
- **Keyholes are removed.** The back is too thin; use a steel plate on the wall
  instead.
- **Two small features moved for the button strip's recess.** The logo moved
  to Y = −58, and the lowest zip-tie block is gone.
- **Screws and buttons sit on the protoboards' 2.54 mm grid,** so they can be
  drilled where the grid says rather than measured.
  - The carrier's screws are in the middle of its corner squares of four
    holes, at X ±31.75, 4.15 and 32.09 mm below its top edge (brief ±30;
    first pass 5 and 31 mm). A 2.7 mm drill centres itself there.
  - The strip's screws are its holes at X ±36.83 (brief ±38).
  - The buttons are 25.4 mm (10 holes) apart (brief 26).
  - A notch in the carrier's left ledge clears the MiniBoost's VIN joint,
    which lands on the ledge.
  - The XIAO's USB slot is at X −7.62, on the carrier's grid (brief −8).
- **The antenna is on a fin on the back cover,** not in a recess in the top
  wall. On the wall, its 100 mm coax couldn't reach the XIAO while the case
  was open, so it could only be plugged in blind. On the fin, the antenna and
  the XIAO are on the same part; it sits 2.4 mm inside the wall and 1.4 mm
  further back, still standing on edge away from the door. The magnet rule
  for it is 30 mm (was 35): a steady field doesn't affect an antenna, and the
  magnets' metal is kept 10 mm away like any other. The coax notch in the
  top rib is 4 mm deep (brief 3) for its lower feed.
- **The carrier sits 0.2 mm lower** (0.6 mm of plate under its recess) to
  fit the MiniBoost, which is 5.6 mm tall, not the 5 mm first assumed.
- **The interior rib at Y = 36 has a second gap** for the battery lead and
  its plug, at X 1–13; the HAT's wires share the wire passage with the
  button lead.
- **Kept from the first pass:**
  - magnets at (±90, ±65) under a 36 mm board rule (the brief had ±58 and
    30 mm)
  - a cap preload of −0.2 mm (a gap)
  - the cap keyway
  - USB slots open toward the back edge and closed by tongues
  - the engraved logo
  - the 144 mm flex relief

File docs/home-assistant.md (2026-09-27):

# Home Assistant

brwr-trmnl talks to Home Assistant over MQTT. It appears as a device with
sensors, controls and button triggers, and it takes commands: show this
screen, post this note, next screen. Voice commands are those same commands
said out loud ([voice.md](voice.md)).

```
  Home Assistant                                            brwr-trmnl
  ┌───────────────────────────────────────────┐   MQTT     ┌──────────────┐
  │ Mosquitto broker  ◄────────────────────────┼──────────► │ state, button│
  │                                            │  commands  │ triggers     │
  │ Terminus add-on :2300  (TRMNL plugins,     │  ◄──────── │ GET screen   │
  │   playlists)                               │   image    │              │
  │ TRMNL HA add-on :10000 (dashboards → PNG)  │  ──────►   │ 1872 × 1404  │
  │ packages/brwr_trmnl.yaml (screens, scripts,│            │ 16 grays     │
  │   voice intents)                           │            │              │
  └────────────────────────────────────────────┘            └──────────────┘
```

## 1. Add-ons and integrations

| What | Why | Where |
|---|---|---|
| **Mosquitto broker** add-on + the **MQTT** integration | The device's connection to Home Assistant | Settings › Add-ons › Add-on store |
| **Terminus** add-on (port 2300) | TRMNL's plugins and playlists, served locally. Needed for the "TRMNL server" source | Add-on repository [`https://github.com/usetrmnl/trmnl-home-assistant`](https://github.com/usetrmnl/trmnl-home-assistant) |
| **TRMNL HA** add-on (port 10000) | Renders Home Assistant dashboards as 16-gray PNGs. Needed for "Home Assistant screens", and for voice/notes | same repository |

1. **Mosquitto**: install, start, then Settings › Devices & services › MQTT
   (Home Assistant offers it once the broker runs). Mosquitto accepts Home
   Assistant user logins: create a user such as `mqtt` (Settings › People ›
   Users, "Can only log in from the local network"; the Users tab needs
   **Advanced mode**, in your profile) and give the display that username and
   password.
2. **Add-on repository**: Settings › Add-ons › Add-on store › ⋮ ›
   Repositories, add `https://github.com/usetrmnl/trmnl-home-assistant`.
3. **Terminus**: install, set **Home Assistant IP** (`ha_ip`) to your Home
   Assistant's IP address, start, open the web UI and create an account. Terminus serves the device at
   `http://<ha-ip>:2300`; the display's setup page fills that in for you.
4. **TRMNL HA**: install, create a long-lived access token (your profile ›
   Security › Long-lived access tokens) and paste it into **access_token**.
   Turn on **keep_browser_open**: otherwise the add-on starts its browser
   again for each render, which you notice when you ask for a screen by
   voice. Port 10000 has no authentication, so keep it on your home network.
   The add-ons' own documentation is in
   [their repository](https://github.com/usetrmnl/trmnl-home-assistant).

## 2. Connect the display

Hold **REFRESH** for 5–15 s (or power it up for the first time). It forgets
its saved Wi-Fi networks and opens a Wi-Fi hotspot called
`brwr-trmnl-XXXXXX`. Join it; the setup page opens (or go to
`http://4.3.2.1`). Pick your Wi-Fi, then under **Home Assistant**:

- **Home Assistant address**: its IP address, e.g. `192.168.1.20`.
- **Screens come from**: *Terminus add-on* or *Home Assistant dashboards*.
  You can change this later in Home Assistant.
- **MQTT username / password**: the user from step 1.
- **Panel VCOM**: the voltage printed on the panel's ribbon cable, e.g.
  `-1.52`. A wrong value gives a washed-out picture. You can change it later.

Tap **Connect**. The device should appear within a minute under Settings ›
Devices & services › MQTT as **brwr-trmnl xxxxxx**: the same six characters as
the hotspot, in lower case, which are also its MQTT id
(`brwr-trmnl/a1b2c3/...`). Rename it ("Fridge") if you like.

With Terminus as the source, open the Terminus web UI: the display should
register there when it first connects. It reports itself as a TRMNL X
(model `x`), so Terminus sends it 1872 × 1404 screens in 16 grays. Give it a
playlist. (This hasn't been tried on real hardware yet.)

## 3. The device in Home Assistant

| Entity | Type | What it does |
|---|---|---|
| Battery | sensor | Estimated charge, % |
| Battery voltage | sensor (diagnostic) | Resting voltage at the last wake |
| Wi-Fi signal | sensor (diagnostic) | RSSI at the last wake, dBm |
| Last refresh | sensor (diagnostic) | When the panel last changed |
| Showing | sensor | What's on screen: "Playlist", a screen name, "Battery empty"… |
| Last error | sensor (diagnostic) | Why the last refresh failed, if it did |
| On screen | image | The last image drawn, by its URL. Home Assistant loads the URL itself, so for a dashboard screen it shows a fresh render |
| Screen | select | Pick a screen. "Playlist" goes back to the schedule |
| Image source | select (config) | TRMNL server, or Home Assistant screens |
| Power mode | select (config) | Always ready, or Deep sleep ([power.md](power.md)) |
| Buttons | select (config) | *Change screens* (they also fire triggers), or *Home Assistant only* |
| Refresh interval | number (config) | Minutes; 0 = automatic (the server's rate, or 30 min for Home Assistant screens) |
| Hold commanded screen | number (config) | Minutes a commanded screen stays before the schedule resumes |
| Panel VCOM | number (config) | Volts, as printed on the ribbon cable |
| Refresh, Next screen, Previous screen | buttons | Same as the physical buttons |
| BACK / REFRESH / NEXT: short, double, long press | device triggers | For automations |

In **Deep sleep** the display only checks in when it wakes, so a change you
make in Home Assistant shows up at the next refresh (or press any button). In
**Always ready** it should land within about 15 seconds (an estimate).

## 4. Home Assistant screens

The TRMNL HA add-on turns a dashboard view into the exact image the panel
wants. The device asks for
`http://<ha>:10000/<path>?viewport=1872x1404&dithering&dither_method=floyd-steinberg&palette=gray-16&format=png`.

1. **Make a dashboard for the fridge.** Settings › Dashboards › Add dashboard
   › *New dashboard from scratch*, titled **Fridge display**, not in the
   sidebar. Its URL becomes `fridge-display`, which every screen's path
   starts with (with Advanced mode on, the dialog shows the URL).
   Open it › ✎ › ⋮ › *Raw configuration editor* and paste
   [`homeassistant/dashboards/fridge-display.yaml`](../homeassistant/dashboards/fridge-display.yaml).
   Replace the example entity ids with yours.
2. **Install the package.** Copy
   [`homeassistant/packages/brwr_trmnl.yaml`](../homeassistant/packages/brwr_trmnl.yaml)
   into `<config>/packages/` and make sure `configuration.yaml` loads packages:

   ```yaml
   homeassistant:
     packages: !include_dir_named packages
   ```

   Restart Home Assistant. On start it publishes the screen list to every
   display (`brwr-trmnl/all/set/screens`). After editing the list, reload
   scripts (Developer tools › YAML › Scripts) and then run **Fridge display:
   publish screens**, or restart Home Assistant.
3. **Choose it.** Set **Image source** to *Home Assistant screens*, or keep
   the TRMNL server and use the screens for voice commands and notes only.

Tips for dashboards on e-paper:

- **Panel views** with a grid or stack card keep the layout fixed at any zoom.
- `?zoom=2` in a screen's path doubles the size of everything, which is
  about right for reading from a metre away at 227 dpi. The note screen uses 3.
- Plain black on white reads best. Avoid pale colors, thin fonts and
  animations: the panel shows 16 grays and only changes when a new image
  arrives.
- If a card loads late, add `&wait=1000` (milliseconds) to the path.

A screen can also be a full `http://` or `https://` URL instead of a
dashboard path:

- a ready-made 1872 × 1404 PNG, JPEG or BMP, such as one under
  `http://<ha>:8123/local/`. It's drawn at full size from the top-left
  corner, not scaled, and a PNG must be under 750 kB;
- any web page, rendered by the add-on in its generic mode:
  `http://<ha>:10000/?url=<page>&viewport=1872x1404&dithering&dither_method=floyd-steinberg&palette=gray-16&format=png`.

Anything that isn't a full URL is taken as a dashboard path. For a camera,
add a view with a picture-entity card to the fridge dashboard.

## 5. Scripts and commands

The package's scripts work from automations, the dashboard and voice:

| Script | Does |
|---|---|
| `script.brwr_trmnl_show` | `screen:` name, or `path:` / `url:` (+ `name:`), and optional `hold:` minutes |
| `script.brwr_trmnl_note` | Sets `input_text.brwr_trmnl_note` and shows the Note screen for 4 h |
| `script.brwr_trmnl_command` | `command: next`, `back` or `refresh` (refresh also ends a held screen) |
| `script.brwr_trmnl_publish_screens` | Publishes the screen list |

```yaml
# The doorbell rang: show the front door for 5 minutes (after adding a
# "doorbell" view, e.g. a picture-entity card of the door camera, to the dashboard)
- action: script.brwr_trmnl_show
  data:
    path: "fridge-display/doorbell?zoom=2"
    name: Doorbell
    hold: 5
```

They publish to `brwr-trmnl/all/...`, which every display listens to. Each
command there must carry `ts`, the time it was sent in epoch seconds: a
display acts on each timestamp once, ignores a command without one, and
skips one that went stale while it slept (a show after 15 minutes, or after
its hold; next, back and refresh after 5 minutes). Commands to one display's
own topics need no `ts`.

**MQTT topics**, for anything else (`<base>` = `brwr-trmnl/<last six hex
digits of the MAC, lower case>`):

| Topic | Direction | Payload |
|---|---|---|
| `<base>/status` | device → | `online` / `offline` (retained; offline is the last will) |
| `<base>/state` | device → | JSON: battery, voltage, rssi, refreshed, screen, showing, source, power, buttons, refresh, hold, vcom, held_until, error |
| `<base>/image` | device → | URL of the image on screen |
| `<base>/button` | device → | `back_short`, `refresh_double`, `next_long`, … |
| `<base>/set/source`, `power`, `buttons`, `refresh`, `hold`, `vcom`, `screens` | → device | settings (retained) |
| `<base>/set/screen`, `<base>/cmd`, `<base>/show` | → device | one-shot commands (retained until the device has handled them) |
| `brwr-trmnl/all/set/screens` | → all | `[{"name": "Calendar", "path": "fridge-display/calendar?zoom=2"}, …]` |
| `brwr-trmnl/all/show` | → all | `{"screen": "Calendar", "hold": 30, "ts": 1790424000}` or `"path"` / `"url"` + `"name"` |
| `brwr-trmnl/all/cmd` | → all | `{"cmd": "next", "ts": 1790424000}` |

## 6. Buttons in automations

The front buttons are device triggers: build one in the automation editor
(Settings › Automations › + › Device › your display), which fills in the ids
for you. A long press sends a trigger without changing the screen, so it's
free for your own use:

```yaml
triggers:
  - trigger: device
    domain: mqtt
    device_id: <your display>
    discovery_id: brwr_trmnl_a1b2c3 btn_refresh_long   # your display's id
    type: button_long_press
    subtype: button_2        # button_1 BACK, button_2 REFRESH, button_3 NEXT
actions:
  - action: light.toggle
    target:
      entity_id: light.kitchen
```

Set **Buttons** to *Home Assistant only* and short presses stop changing
screens too, so every press is yours. Holding REFRESH for 5 s (Wi-Fi setup)
or 15 s (reset) always works. That's in **Always ready**: in **Deep sleep**,
any press also wakes the display, which then refreshes as it would on its
timer.

## Troubleshooting

| Symptom | Check |
|---|---|
| Device never appears | MQTT user/password; the broker's log; the display's **Last error** once it does connect |
| **Last error**: "No screen called Calendar" | The name isn't in the published screen list: check `brwr_trmnl_publish_screens` (and the sentences file), reload scripts and run the script again |
| **Last error**: "Couldn't load Calendar (…, HTTP n)" | Open the screen's add-on URL in a browser; the path must match the dashboard URL and view path |
| Screen changes take minutes | Power mode is Deep sleep, or the display lost Wi-Fi (Wi-Fi signal sensor) |
| Washed-out picture | Panel VCOM |
| Entities "unavailable" | The display went offline unexpectedly (last will): battery, Wi-Fi or a crash |
| **Last error**: "Button stuck down" | A switch is pressed all the time (a cap or a solder bridge); it's ignored until released |

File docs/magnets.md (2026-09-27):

# Magnets: on the fridge, clear of the electronics

brwr-trmnl hangs on the fridge door by four magnets hidden inside its back
cover. Each is capped with a steel disc, which works like the cup of a pot
magnet: it turns the field towards the door and away from the electronics.
They should hold it through a slammed door (the estimate is below: test it
on yours), and they're far enough from the boards that their field doesn't
matter there.

## The magnets

Four **N52 neodymium discs, 20 × 3 mm**, each with a **20 mm steel disc**
(1–2 mm thick) on top.

- Each sits in a pocket that opens to the inside of the back cover, behind a
  0.6 mm skin of plastic. The steel disc goes on top, and epoxy fills the
  pocket to just over it. Nothing metal shows outside.
- A self-adhesive rubber pad (25 mm, 0.5–1 mm thick) over each one outside is
  all that touches the door: grip, and no scratches.
- They sit at the four corners of the back, at (±90, ±65) mm from the
  centre.
- The steel disc matters: a bare disc magnet sends as much field backwards
  (into the case) as forwards. The disc carries the back of the field round
  to the front, so the magnet grips harder and less of its field reaches the
  boards.

## Will it hold?

| | |
|---|---|
| brwr-trmnl, complete | about 0.45 kg (estimate: 160 g of printed case, 90 g battery, 80 g panel and HAT, 45 g of steel rod, 45 g magnets and discs) |
| One magnet on thick steel, touching | ~4.3–5.4 kg pull (the supplier's figure for a bare 20 × 3 mm N52 disc) |
| Four, on a fridge door (estimate) | ~4 kg pull, ~2.5 kg sideways |
| Margin (estimate) | ~5 × against sliding down, ~9 × against being pulled off |

The estimate allows for the 0.6 mm skin and the rubber pad (together they
roughly halve a disc magnet's pull), gains back some for the steel backing,
and takes a third of that for a fridge door's thin painted steel. Rubber on
paint gives the sideways grip. These are estimates: hang it, and open and
slam the door a few times with a towel on the floor below. Thinner (0.5 mm)
pads grip harder.

### Will it work on my fridge?

Test the spot with any fridge magnet first.

- **Many stainless-steel doors aren't magnetic** (austenitic stainless,
  such as 304, isn't). The sides of the same fridge are often painted steel
  and are.
- **Glass, wood or "panel-ready" fronts** aren't magnetic either.
- **No magnetic surface?** Stick a thin steel plate or two adhesive steel
  discs on it (sold for phone mounts and "magnetic mounting plates"), or use
  the printed desk stand. On a wall, screw up a steel plate
  ([build guide](build-guide.md#10-hang-it)).

## Why the magnets don't disturb anything

A magnet's steady field can only affect parts that are themselves magnetic.
In this design, that's the power **inductors**: the MiniBoost's on the
carrier board, and the ones for the panel's supplies on the driver HAT. A
strong enough field partly saturates an inductor's core and lowers its
current rating. Nothing else inside cares:

- **The e-paper panel** moves charged pigments with electric fields;
  magnetic fields don't affect it.
- **The ESP32-S3, its flash, the crystal, the battery** and the charger are
  not magnetic.
- There are no Hall sensors, reed switches, compasses or speakers.

So the design rule is simple: **keep every board at least 25 mm from a
magnet's edge**, where even a bare magnet (without its steel disc) produces
**under 5 mT**. That's about 1% of what a ferrite core saturates at, and a
hundred times the Earth's field. The enclosure's source enforces the rule
with `assert()`s on the actual positions (36 mm from each magnet's centre).

Magnet field versus distance: the sideways field is 2.4 mT at the closest board, 26.75 mm from a magnet's edge

| Distance | Sideways (mT) | Straight out (mT) |
|---|---|---|
| 5 mm | 59.1 | 128.7 |
| 10 mm | 18.5 | 62.0 |
| 15 mm | 8.4 | 30.5 |
| 20 mm | 4.6 | 16.4 |
| 25 mm | 2.8 | 9.6 |
| 30 mm | 1.8 | 6.0 |
| 40 mm | 0.9 | 2.8 |
| 50 mm | 0.5 | 1.5 |
| 60 mm | 0.3 | 0.9 |

*Field of a bare, axially magnetised N52 disc, 20 × 3 mm, without its steel
disc, modelled with [Magpylib](https://magpylib.readthedocs.io/). Sideways
is measured from the magnet's edge in the plane of the back cover, towards
the boards; straight out from its face. The script is
[`hardware/analysis/magnet_field.py`](../hardware/analysis/magnet_field.py).*

The real field inside the case is lower than this: the steel disc on each
magnet carries most of what would go backwards or sideways round to the
front. Straight out behind each magnet there's only the steel disc and, a
few mm further, the panel, which doesn't care.

### Distances in the layout

| From the nearest magnet to | Centre to edge | Magnet edge to edge | Field there (bare-magnet model) |
|---|---|---|---|
| Driver HAT (IT8951, panel supplies) | 36.75 mm | 26.75 mm | 2.4 mT |
| Carrier board (XIAO, MiniBoost, charger) | 55 mm | 45 mm | 0.7 mT |
| Wi-Fi antenna | 32.9 mm | 22.9 mm | not affected by a steady field; kept away from metal instead |

### The steel rods

The thin case is stiffened by 3 mm steel rods epoxied into it: two across
the back cover and one in each corner of the frame. They're plain steel, so
the magnets attract them, but they're epoxied in place. As a rule of thumb
every rod stays at least 8 mm from a magnet's edge, so it doesn't gather
much of the field (the rods aren't in the field model), and every rod runs
well clear of the boards. They also stay 10 mm from the antenna. The
enclosure's source asserts both rules.

## Wi-Fi next to a steel door

The door is a large sheet of steel right behind the display, and steel
reflects and detunes a nearby antenna. So the antenna (a Taoglas FXP831,
45 × 7 mm) stands on edge on a fin just inside the **top** wall, where it
stands out from the door instead of lying flat against it. The fin is part
of the back cover, so the antenna and the XIAO it plugs into come apart
from the frame together. Nothing metal is within 10 mm of it (the nearest
steel rod is at 10 mm) except the carrier board's copper, 3 mm from its end,
and the charger module, 7 mm away. Check the **Wi-Fi signal** sensor
in Home Assistant once it's hung. Anything better than about −75 dBm is
fine; if it's weaker, a Wi-Fi access point in the kitchen helps more than
anything you can do to the display.

## Changing the magnets

The magnet size and positions are parameters at the top of
[`hardware/enclosure/brwr-trmnl.scad`](../hardware/enclosure/brwr-trmnl.scad):
`mag_d`, `mag_h`, `steel_disc`, and `mag_pos` with one `[X, Y]` per magnet.
The render fails with a message if a magnet ends up too close to a board or
the antenna, or a rod too close to a magnet. With the default layout there's
no room for a fifth or sixth magnet that keeps 25 mm from the boards. If you
move a magnet closer to a board than 25 mm, rerun the field model with the
new gap:

```sh
pip install magpylib numpy
CLEARANCE_MM=20 python3 hardware/analysis/magnet_field.py
```

## Safety

Neodymium magnets this size pinch fingers hard when they snap together or
onto steel, and can interfere with pacemakers and other implants: keep them
at least 15 cm away, and keep loose magnets away from children. Once
they're set in epoxy they can't come loose. They won't harm the fridge, but
they can wipe magnetic-stripe cards pressed right against them.

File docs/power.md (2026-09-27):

# Power and battery life

brwr-trmnl runs on a 5000 mAh LiPo and charges over USB-C. How long a charge
lasts depends mostly on two settings you can change in Home Assistant: the
**power mode** and the **refresh interval**.

> **Estimates, not measurements.** The currents below come from datasheets and
> published measurements of the same parts, and no prototype has been measured
> yet. Check your own build: the **Battery** sensor in Home Assistant plotted
> over a week tells you the real rate.

## The power path

```
 USB-C (charge) ──► TP4056 charger ──► OUT+ ─┬─► XIAO ESP32-S3 BAT+ ──► 3.3 V regulator ──► ESP32-S3
                     + DW01A protection      │
 LiPo 5000 mAh ◄──► B+ / B−                  ├─► MiniBoost 5 V (TPS61023) ──► e-paper HAT (IT8951)
                                             │     EN ◄── GPIO6: on while awake
                                             └─► 220k / 220k divider ──► GPIO4 (battery voltage)
```

- The **panel's controller is powered only while the display is awake**:
  the firmware switches the MiniBoost on as it starts the display, at the
  beginning of each wake, and off again before it sleeps. The MiniBoost is a
  "true disconnect" booster: with EN low its output is cut off from the
  battery completely, so the HAT draws nothing between refreshes. That's
  why this build uses it rather than a booster without an enable pin, which
  would feed the HAT all the time.
- The **XIAO runs straight off the battery** through its own low-dropout
  regulator, and sleeps between refreshes.
- The **e-paper holds its picture with no power at all.**

## Where the current goes

### Asleep

| | Current | Source |
|---|---|---|
| XIAO ESP32-S3, deep sleep | ~14 µA | Seeed's figure for the XIAO ESP32S3 |
| MiniBoost EN pull-up (100 kΩ to the battery, held low) | ~40 µA | 4 V ÷ 100 kΩ |
| Battery divider, 2 × 220 kΩ | ~9 µA | 4 V ÷ 440 kΩ |
| TP4056 module (charger off, DW01A protection) | ~4 µA | datasheets, typical |
| The battery's own protection board | ~3 µA | typical |
| MiniBoost booster (off), HAT (unpowered) | < 1 µA | TPS61023 shutdown current |
| **Total** | **~70 µA, about 1.7 mAh a day** | |

The largest item is the pull-up resistor on the MiniBoost's EN pin. It's
harmless, but if you want the last 5% (or refresh only a few times a day),
remove the 100 kΩ resistor next to the EN pin on the MiniBoost (R1 on
Adafruit's schematic): the 4.7 kΩ pull-down on the carrier keeps the booster
off without it. Sleep current drops to about 30 µA.

### Each refresh

| Step | Time | Battery current |
|---|---|---|
| Boot, switch on the HAT, connect to Wi-Fi and MQTT | 2–4 s | ~90 mA, plus the HAT idling |
| Ask the server, download the image (1872 × 1404 PNG) | 1–6 s | ~90 mA, plus the HAT (longer when the TRMNL HA add-on renders a dashboard) |
| Decode into PSRAM | ~1 s | ~70 mA, plus the HAT |
| Load the image over SPI, refresh the panel | ~3 s | ~200 mA (5 V through the booster) |
| Report to Home Assistant, switch the HAT off, sleep | < 1 s | ~90 mA |
| **Total** | **7–15 s** | **0.26–0.46 mAh, plus the HAT idling** |

Nobody has measured what the IT8951 HAT draws while it idles, waiting for
the download, so the battery life below budgets **0.5–0.9 mAh a refresh**:
about twice the rows above, to cover it and slower networks.

### Awake and listening ("Always ready")

The ESP32-S3 stays connected to Wi-Fi and MQTT in automatic light sleep,
waking for Wi-Fi beacons and MQTT keep-alives. Expect **2–5 mA**, depending
mostly on your network: routers that send a lot of broadcast traffic keep it
awake more often. That's the `brwr_trmnl` firmware. The fallback
`brwr_trmnl_arduino` build can't light-sleep, so it idles fully awake at
about 25 mA: about a week on the battery.

## Battery life

5000 mAh, counting 85% of it as usable (the firmware stops at 3.35 V, and
cells lose capacity with age):

| Power mode | Refresh | Per day | One charge lasts |
|---|---|---|---|
| Deep sleep | every 15 min | 50–88 mAh | **7–12 weeks** |
| Deep sleep | every 30 min | 26–45 mAh | **3–5 months** |
| Deep sleep | every 60 min | 14–23 mAh | **6–10 months** |
| Always ready | every 60 min | 60–142 mAh | **4–10 weeks** |
| Always ready | every 30 min | 72–163 mAh | **4–8 weeks** |

Voice commands, button presses and screens pushed from Home Assistant each
cost about one refresh.

## Choosing a power mode

| | **Always ready** (default) | **Deep sleep** |
|---|---|---|
| A voice command or automation shows up | In about 10–15 seconds | At the next wake, if that's soon enough: the package's scripts and voice commands are dropped after 15 minutes (5 for next, previous and refresh; a note's hold time for notes). The device's own controls in Home Assistant wait for the next wake |
| Buttons | Home Assistant gets the press at once. On screen, BACK through cached TRMNL screens takes a few seconds; anything that needs a new image (NEXT, REFRESH, or BACK with Home Assistant screens) is a full refresh, about 10–15 s | A press wakes it. The same on screen, and Home Assistant gets the press once it has reconnected |
| Settings changed in Home Assistant | Applied at once | Applied at the next wake |
| One charge | Weeks | Months |

Change it from the device page in Home Assistant (**Power mode**). If "show
the calendar on the fridge" is what you built it for, keep **Always ready**
and charge it every month or so. If it's a calm dashboard that changes every
half hour, **Deep sleep** gets you a season per charge.

In Always ready, if Wi-Fi or MQTT stays down for two to three minutes the
device gives up listening and sleeps until its next refresh, then tries
again, so a router outage doesn't drain the battery.

## Charging

- Plug a USB-C charger into the **CHARGE** port (the TP4056 module) at the top
  edge. It charges at 1 A: about **5–6 hours** from empty. The module's LED is
  red while charging and turns blue or green when it's done.
- The other port, **USB**, is the XIAO's. It's for flashing and logs, and
  also charges, slowly (100 mA, about two days from empty).
- It keeps working while it charges.
- **If a USB-C-to-C charger does nothing**, the charger module is missing the
  resistors that USB-C chargers look for. Use a USB-A-to-C cable, or buy a
  module that lists "5.1k CC resistors".

## When the battery runs out

Below 3.35 V (resting) the booster can't hold 5 V through a refresh, so the
display shows **Battery empty**, reports it to Home Assistant (the **Last
error** sensor, and **Showing** reads "Battery empty"), and stops refreshing.
Charge it, then press any button.

It still draws its sleep current while it waits. The charger module's
protection disconnects the cell at about 2.4 V, but charge it within a
month or two of it saying empty: lithium cells don't like being stored flat.

## Battery care

- Pouch cells must not be squeezed, bent or pierced. The enclosure's cradle
  holds it on foam with clearance all round; never add screws or ribs that
  press on it.
- A fridge door is at room temperature, which suits the cell. Don't mount it
  on the side of an oven or near the fridge's warm vent at the bottom or back.
- LiPo cells charge between 0 °C and 45 °C.
- For storage, charge to about half and unplug the battery (the back cover
  comes off with its nine screws).

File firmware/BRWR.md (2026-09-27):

# brwr-trmnl changes to trmnl-firmware

This directory is [usetrmnl/trmnl-firmware](https://github.com/usetrmnl/trmnl-firmware)
imported with `git subtree`, plus the changes below for the brwr-trmnl board:
a Seeed XIAO ESP32-S3 driving a Waveshare 10.3" e-Paper HAT (IT8951 over SPI,
1872 × 1404, 16 grays), three front buttons, and Home Assistant over MQTT.

Upstream base: `f5f87b7` (main, 2026-09-21, v1.8.16 + 30 commits).

## Build

```sh
cd firmware
pio run -e brwr_trmnl -t upload        # recommended
pio device monitor -e brwr_trmnl       # logs over USB
```

| Environment | Framework | Use |
|---|---|---|
| `brwr_trmnl` | Arduino as an ESP-IDF component | Recommended. Power management is enabled, so **Always ready** idles in light sleep with Wi-Fi and MQTT connected. |
| `brwr_trmnl_debug` | same | Waits for the serial monitor at boot and logs more. |
| `brwr_trmnl_arduino` | precompiled Arduino core | Builds without downloading ESP-IDF components. It has no light sleep, so **Always ready** stays fully awake (~25 mA): use it on USB power. |

Each build also writes `.pio/build/<env>/merged_firmware.bin`, a single image
to flash at offset `0x0` (`esptool --chip esp32s3 write-flash 0x0 merged_firmware.bin`, or
[esptool-js](https://espressif.github.io/esptool-js/) in a browser). Use it for
the first flash: it also blanks the NVS partition, which clears the saved
Wi-Fi, the server and every setting. To update a display that's already set
up, use `pio run -e brwr_trmnl -t upload`, or write `firmware.bin` at `0x10000`.

## What changed

Everything new lives in `src/brwr/` and `include/brwr/`. Upstream files mostly
gain small `#ifdef BOARD_BRWR_TRMNL` blocks that call into it. A few changes
apply to every board but change nothing for the others: the setup page,
the `Model` header (`API_DEVICE_MODEL` is `DEVICE_MODEL` on other boards),
the components in `src/CMakeLists.txt`, and a note in `README.md`.

| File | Change |
|---|---|
| `platformio.ini` | `brwr_trmnl`, `brwr_trmnl_debug` and `brwr_trmnl_arduino` environments (appended). |
| `boards/brwr_trmnl_8MB.csv` | Partition table for the XIAO's 8 MB flash: two 3 MB app slots, 1.9 MB LittleFS image cache. |
| `sdkconfigs/sdkconfig.brwr_trmnl` | Copy of the reTerminal E1003 config with 8 MB flash, `CONFIG_PM_ENABLE` and FreeRTOS tickless idle. |
| `scripts/extra/post_build_brwr.py` | Writes the merged image. |
| `include/config.h` | Pins, battery ADC pin, `brwr-trmnl` hostname, and `API_DEVICE_MODEL` (`x`, so Terminus serves 1872 × 1404 16-gray screens). |
| `src/display.cpp` | Device-list entry; IT8951 init shared with the E1003, then VCOM and SPI clock; HAT pins released after sleep. |
| `src/bl.cpp` | Hooks: early init, three buttons, no logo on button or timer wakes, Home Assistant before the server fetch, state report, sleep. Keeps Wi-Fi up after the download. Never takes firmware updates from the server, and skips log uploads without a TRMNL server. Keeps the cached-screen order for the Back button. |
| `src/bl.cpp`, `src/services/device_setup.cpp` | Send `API_DEVICE_MODEL` in the `Model` header. |
| `src/CMakeLists.txt` | Requires `mqtt` and `esp_pm`. |
| `lib/wificaptive/` | Setup page: Home Assistant address, screen source, MQTT login, an MQTT broker address and port (if the broker isn't on Home Assistant) and panel VCOM. A blank server address becomes the Terminus add-on, `http://<Home Assistant>:2300`. The section only appears when the firmware reports it, so other boards are unchanged. Hotspot name `brwr-trmnl-XXXXXX`. `portal/index.html` is the source; `src/WifiCaptivePage.h` is generated from it by `portal/convert.py`. |
| `README.md` | A note at the top pointing here. |

Why no over-the-air updates from the server: the device reports itself as a
TRMNL X to get the right screen format, and a TRMNL X firmware image would not
run on this hardware. Flash updates over USB, as above.

## Updating from upstream

```sh
git subtree pull --prefix=firmware https://github.com/usetrmnl/trmnl-firmware.git <tag-or-commit> --squash
```

Conflicts, if any, are in the files listed above. For the setup page, merge
`portal/index.html` and regenerate `WifiCaptivePage.h` with `portal/convert.py`
rather than merging the generated file. Then build `brwr_trmnl` and
`brwr_trmnl_arduino`; CI (`.github/workflows/firmware.yml`) builds both on
every push that changes `firmware/`.

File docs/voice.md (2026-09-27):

# Voice: "show the calendar on the fridge"

Say it to a voice speaker and it's on the fridge 10–15 seconds or so later
(an estimate: nobody has timed a real one yet). The speaker doesn't talk to
the display directly: it's a Home Assistant voice
satellite, and Home Assistant does the rest.

```
 "Hey Jarvis, show the calendar on the fridge"
        │
        ▼
 Voice speaker ───► Home Assistant Assist ───► brwr_trmnl sentences ───► script.brwr_trmnl_show
 (any Assist         wake word, speech-to-text,   (custom_sentences/)         │  MQTT, retained
  satellite)         intent                                                   ▼
        ▲                                                         brwr-trmnl/all/show
        └──── "Okay, Calendar is going on the fridge." ◄──                    │
                                                                              ▼
                                                        every display: fetch the Calendar screen, draw it
```

Any Assist satellite works the same way: the open speaker (a Raspberry Pi
running as a Home Assistant voice satellite), a Home Assistant Voice Preview
Edition, an ESP32-S3-BOX, the Home Assistant app on a phone or watch, or
typing into Assist. Nothing on the speaker needs to know the display exists.

## Set it up

You need [Home Assistant set up for the display](home-assistant.md) with the
package installed, and a working voice assistant (Settings › Voice
assistants).

1. Copy
   [`homeassistant/custom_sentences/en/brwr_trmnl.yaml`](../homeassistant/custom_sentences/en/brwr_trmnl.yaml)
   to `<config>/custom_sentences/en/brwr_trmnl.yaml`.
2. Restart Home Assistant (later edits only need the action
   `conversation.reload`).
3. Try it without the speaker: open Assist (the speech bubble in the top
   bar) and type *show the calendar on the fridge*.

Set the display's **Power mode** to **Always ready** (the default). In
**Deep sleep** a voice command waits until the display next wakes, and it's
only kept for so long: a screen for 15 minutes (a note for its 4 hours),
next, previous and refresh for 5 minutes. A display that wakes later skips
it.

## What you can say

| Say | Does |
|---|---|
| "Show the calendar on the fridge" | Shows a screen. With the TRMNL server as the image source it stays up for an hour (**Hold commanded screen**), then the playlist carries on; with Home Assistant screens it becomes the current screen |
| "Put the shopping list on the fridge", "Fridge, show the weather" | Same, other screens: *home*, *calendar*, *shopping list* or *grocery list*, *weather* or *forecast*, *note* |
| "Leave a note on the fridge saying dinner's at seven" | Posts a note for 4 hours |
| "Fridge note: back by six" | Same, shorter |
| "Next screen on the fridge", "Previous fridge screen" | Steps through the screens |
| "Refresh the fridge", "Clear the fridge display" | Ends a held screen or note and refreshes (with the TRMNL server as the source, the playlist moves on) |

The word lists are in the sentences file. To add a screen:

1. Add a view for it to the fridge dashboard.
2. Add it to `brwr_trmnl_publish_screens` in the package: its name and
   dashboard path.
3. Add the same name under `brwr_screen` in the sentences file, with the
   words you'll say for it.
4. If an LLM agent uses the scripts, add the name to the screen names in
   the **Fridge display: show** script's description too.
5. Reload scripts (Developer tools › YAML › Scripts), run **Fridge display:
   publish screens**, and run the action `conversation.reload`.

```yaml
      - in: "(bin|trash|recycling) [day]"
        out: "Bins"
```

## How long it takes

With **Always ready**, from the end of the sentence (estimates):

| Step | Time |
|---|---|
| Speech-to-text and intent | under a second (Home Assistant Cloud) to 1–3 s (Whisper on a Raspberry Pi) |
| Home Assistant → MQTT → display | well under a second |
| Display restarts, reconnects to Wi-Fi and MQTT | 3–7 s |
| TRMNL HA add-on renders the dashboard | 1–4 s (longer if its browser has to start: turn on **keep_browser_open**) |
| Decode, load and refresh the panel | ~3 s |
| **Total** | **about 8–17 seconds** |

The speaker answers straight away; it doesn't wait for the panel.

## With an AI conversation agent

If your voice assistant uses an LLM (OpenAI, Anthropic, Google, Ollama):

- Turn on **Prefer handling commands locally** in the voice assistant's
  settings. The sentences above then run instantly without the model and
  cost nothing; anything they don't match goes to the model.
- To let the model handle requests the sentences don't cover ("put the
  weather on the fridge for five minutes"), expose the scripts: open
  **Fridge display: show**, **post a note** and **next, previous or
  refresh** under Settings › Automations & scenes › Scripts, then ⋮ ›
  Settings › Voice assistants › expose. Their descriptions tell the model what
  each one does and which screen names exist. It can only show screens in
  the list, or a dashboard path or image URL you tell it about.

## More than one display

Everything above publishes to `brwr-trmnl/all/...`, so every display shows
it. To aim at one display, publish to its own topic,
`brwr-trmnl/<id>/show`, where `<id>` is in the device's MQTT info in Home
Assistant. For example, a sentence trigger in an automation:

```yaml
triggers:
  - trigger: conversation
    command: "show the calendar in the hall"
actions:
  - action: mqtt.publish
    data:
      topic: brwr-trmnl/a1b2c3/show
      payload: '{"screen": "Calendar", "hold": 30}'
      retain: true
  - set_conversation_response: "Okay, it's in the hall."
```

The per-display topic is retained until that display has handled it, so it
also reaches a display that's in deep sleep, when it next wakes.

## If it doesn't work

| Symptom | Check |
|---|---|
| Assist says "Sorry, I couldn't understand that" | The sentences file isn't loaded: its path, then `conversation.reload`. With an LLM agent, **Prefer handling commands locally** |
| Assist answers but the display doesn't change | The display's **Power mode**, and its **Last error** sensor. In Settings › Devices & services › MQTT › Configure, listen to `brwr-trmnl/#` and repeat the command |
| **Last error** says "No screen called Calendar" | The name in the sentences file must match a name in `brwr_trmnl_publish_screens`; after editing the list, reload scripts and run the publish script |
| **Last error** says "Couldn't load Calendar (…, HTTP n)" | That screen's dashboard path must open in the TRMNL HA add-on: try its URL in a browser |
| It takes 20 s or more | The add-on's browser is starting each time (**keep_browser_open**), or the display's Wi-Fi signal is weak |

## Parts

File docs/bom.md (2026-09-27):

# Bill of materials

About **$240** for one display, $157 of it the e-paper panel. The
spreadsheet version, with part numbers and links, is
[`hardware/bom.csv`](../hardware/bom.csv).

Prices are in US dollars, without shipping or tax. "Seen" prices were
checked on 26 September 2026 (some through search results, where the
supplier's site couldn't be loaded); "typical" ones are ordinary prices for
common parts, which you may already have or can buy anywhere. Several small
parts only come in packs, so the first build costs more than the per-unit
total, and a second one much less.

## Electronics — $205.93

| Ref | Qty | Part | Notes | Price |
|---|---|---|---|---|
| U2 | 1 | [Waveshare 10.3inch e-Paper HAT](https://www.waveshare.com/10.3inch-e-paper-hat.htm) (SKU 18434) | 1872 × 1404, 16 grays. The kit includes the panel, the IT8951 driver board, the adapter board, the 40-pin flat cable and the 8-wire PH2.0 cable. The driver is shaped as a Raspberry Pi HAT, but no Pi is used: it's only the panel's controller, wired to the XIAO over SPI. Its Pi header and 8-pin socket come off in this build (see the [build guide](build-guide.md#3-prepare-the-driver-hat)). Also on Amazon (B08KDMY48R) | $157.00 seen |
| U1 | 1 | [Seeed Studio XIAO ESP32S3](https://www.seeedstudio.com/XIAO-ESP32S3-p-5627.html) (113991114) | 8 MB flash, 8 MB PSRAM, USB-C, U.FL antenna socket. Not the Sense version. Its bundled antenna is too tall for the case | $7.49 seen |
| ANT1 | 1 | [Taoglas FXP831](https://www.digikey.com/en/products/detail/FXP831.07.0100C/931-1121-ND/2690271) (FXP831.07.0100C) | Peel-and-stick Wi-Fi antenna, 45 × 7 mm, 100 mm lead with a U.FL plug. It sticks to a fin on the back cover. Any 2.4 GHz FPC antenna up to 45 × 7 mm with a U.FL lead of at least 100 mm works | $5.14 seen |
| U3 | 1 | [Adafruit MiniBoost 5V @ 1A](https://www.adafruit.com/product/4654) (4654) | TPS61023 booster with an enable pin that disconnects the output completely | $3.95 seen |
| U4 | 1 | TP4056 USB-C charger module with protection | 1 A, DW01A + FS8205A, pads B+/B− and OUT+/OUT−. Search "TP4056 Type-C protection"; 10-packs ~$8–10. Prefer one that lists 5.1k CC resistors | $1.00 typical |
| BT1 | 1 | LiPo 3.7 V 5000 mAh, 6 × 60 × 100 mm ("6060100") | With protection board and JST-PH 2.0 lead. **No thicker than 6 mm**, and **check the lead's polarity** | $16.00 typical |
| SW1–SW3 | 3 | Tactile switch 12 × 12 × 4.3 mm, flat plunger | Omron B3F-4000 or any equivalent; the printed caps press them | $1.65 |
| R1, R2 | 2 | 220 kΩ 1%, ¼ W | Battery voltage divider | $0.20 |
| R3 | 1 | 1 kΩ 1%, ¼ W | In series with the HAT's reset line | $0.10 |
| R4 | 1 | 4.7 kΩ 1%, ¼ W | Keeps the booster off while the ESP32 boots | $0.10 |
| C1 | 1 | 100 nF ceramic | Smooths the battery reading | $0.30 |
| C2 | 2 | 47 µF 10 V X5R ceramic, 1210 | 5 V at the HAT, two in parallel (Murata GRM32ER61A476KE20L). Low enough to lie flat on the carrier | $0.90 |
| C3 | 2 | 100 µF 6.3 V X5R ceramic, 1210 | Battery rail at the booster, two in parallel (Murata GRM32ER60J107ME20L) | $1.10 |
| J1 | 1 | JST-PH 2-pin pigtail | A short lead with a JST-PH plug for the battery, soldered to the carrier | $0.50 |
| J4 | 1 | JST-PH 4-pin plug and socket, pre-wired pair | Inline in the button lead, so the frame and the back cover come apart. Leads 20 cm or longer. J2 and J3 have no connector: their wires solder straight into the carrier, where there's no room for one | $1.00 |
| | 1 | 40-pin FFC, 0.5 mm pitch, same-side contacts (type A), 150 mm | Only if the kit's flat cable is too short: it has to reach from the adapter board to the HAT with the back cover propped open, about 10 cm | $2.00 |
| PCB1, PCB2 | 1 | Protoboard, double-sided, 2.54 mm, 9 × 15 cm | Both boards come out of one: the carrier (27 × 13 holes) and the 84 × 20 mm button strip. A 5 × 7 cm board is too short for either | $2.50 |
| | 1 | Hook-up wire | 26 AWG silicone for power, 28–30 AWG for signals | $5.00 |
| SW4 | 1 | Wire link | A short piece of the hook-up wire: it joins the charger's output to everything else. A slide switch fits the same holes, but it would be sealed inside the case | $0.00 |

## Mounting and enclosure — $36.40

| Ref | Qty | Part | Notes | Price |
|---|---|---|---|---|
| M1–M4 | 4 | [N52 disc magnet, 20 × 3 mm](https://suprememagnets.com/products/n52-neodymium-magnet-disc-20mm-od-x-3mm-h) | About 4.3–5.4 kg pull each, on thick steel. Hidden inside the back cover | $4.00 |
| | 4 | Steel disc, round, 20 mm across, 1.5–2 mm thick | Mild (magnetic) steel, one on each magnet inside the case. It works like the cup of a pot magnet: more grip on the door, less stray field inside. Steel blanks sold for magnets, or M10 flat washers (DIN 125: 20 mm across, 2 mm thick). The pockets are round, 20.3 mm: squares don't fit | $1.00 |
| | 4 | Self-adhesive rubber pad, 25 mm, 0.5–1 mm thick | Over each magnet on the back: grip, and no scratches on the door | $3.00 |
| | 1 m | Steel rod, 3 mm | Stiffens the thin case: two straight rods across the back and four bent L-rods in the frame's corners ([cut list](../hardware/enclosure/README.md#steel-rod-cut-list)) | $4.00 |
| | 1 | Two-part epoxy, 30-minute or slower | Rods, magnets and steel discs | $7.00 |
| | 9 | M3 heat-set insert (4 mm long) + M3 × 6 **countersunk** screw | Back cover to frame ([Adafruit 4255](https://www.adafruit.com/product/4255) or similar). Countersunk, so the heads sit flush | $2.25 |
| | 1 | M2.5 hardware | 2 heat-set inserts and 2 × M2.5 × 5 pan-head screws (button strip); 4 × M2.5 × 8 and 2 × M2.5 × 6 countersunk screws with 6 nuts (HAT, carrier) | $2.00 |
| | 250 g | PETG filament | Frame rails ~51 g, back halves ~110 g, caps ~2 g, desk stand ~70 g | $5.00 (at ~$20/kg) |
| | 1 | Foam tape: 1 mm double-sided, 0.5 mm for the window gasket | Holds the panel flat without point loads | $5.00 |
| | 1 | [Kapton tape](https://www.adafruit.com/product/3057), 10 mm | Insulates the back of the boards | $3.00 |
| | 3 | Zip ties, 2.5 mm | Hold the button wires in the three tie blocks up the back cover | $0.15 |

For a wall instead of the fridge: a thin steel plate for the magnets to hold
(for example 1 mm galvanised steel, about 200 × 150 mm), and two screws.

## Tools

- Soldering iron with a fine tip, and a heat-set insert tip (or an old tip
  you don't mind using for inserts)
- Multimeter (battery polarity, first power-up checks)
- 3D printer with a bed of at least **220 × 220 mm**. The two long frame
  rails print diagonally; with a 250 × 210 mm bed or bigger you can print
  the one-piece frame and back instead
- Flush cutters, wire strippers, tweezers, a hobby knife
- Hex keys, 1.5 mm (M2.5 countersunk screws) and 2 mm (M3), a small
  screwdriver for the button strip's pan-head screws, and small pliers or a
  5 mm nut driver for the M2.5 nuts
- A drill, or a pin vise, with a 2.7 mm bit: four mounting holes in the
  protoboards
- A vise (or two pairs of pliers) to bend the 3 mm rod, and a hacksaw or
  bolt cutters to cut it
- A computer with Chrome or Edge (flashing from the browser), or PlatformIO

## Changes from the first draft

The [README](../README.md) as first written listed a Pololu U3V16F5 booster,
used the XIAO's built-in charger, and the first enclosure was 25 mm deep.
This design changes that:

- **Adafruit MiniBoost instead of the Pololu U3V16F5.** The Pololu's `EN`
  pin only stops the switching; when it's off, the battery still reaches
  the output through the inductor and diode, so the HAT would be powered
  all the time at battery voltage. The MiniBoost's TPS61023 disconnects its
  output completely.
- **A TP4056 charger module.** The XIAO charges at only 100 mA, about 50
  hours for a 5000 mAh cell. The module charges at 1 A (5–6 hours) through
  its own USB-C port, and adds a second layer of battery protection.
- **13 mm thin, like the TRMNL X (12 mm):** the HAT loses its unused Pi
  header, a 7 mm antenna replaces the XIAO's 21 mm one, flat 4.3 mm switches
  replace 7.3 mm ones, ceramic capacitors replace electrolytics, and hidden
  3 mm disc magnets with steel backing replace 6 mm rubber pot magnets.
  Epoxied steel rods make up for the thinner walls.

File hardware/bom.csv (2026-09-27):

ref | qty | item | specification | supplier | part_number | unit_usd | line_usd | price_status | url | notes
U2 | 1 | Waveshare 10.3inch e-Paper HAT | 1872x1404, 16 grays, IT8951 driver board, rigid glass panel | Waveshare | SKU 18434 | 157.00 | 157.00 | seen 2026-09-26 ($156.59-159.99) | https://www.waveshare.com/10.3inch-e-paper-hat.htm | Kit includes panel, driver board, adapter board, 40-pin FFC and an 8-wire PH2.0 cable. The driver is shaped as a Raspberry Pi HAT; no Pi is used. Its Pi header and 8-pin socket come off in this build. Also on Amazon (B08KDMY48R).
U1 | 1 | Seeed Studio XIAO ESP32S3 | ESP32-S3, 8 MB flash, 8 MB PSRAM, USB-C, U.FL | Seeed Studio | 113991114 | 7.49 | 7.49 | seen 2026-09-26 | https://www.seeedstudio.com/XIAO-ESP32S3-p-5627.html | DigiKey 1597-113991114-ND. Not the Sense version. Its bundled antenna is too tall for the 13 mm case: use ANT1.
ANT1 | 1 | Taoglas FXP831 FPC antenna | 2.4/5 GHz, 45 x 7 x 0.1 mm, 100 mm of 1.37 mm coax, U.FL (I-PEX MHF I), adhesive | DigiKey | FXP831.07.0100C (931-1121-ND) | 5.14 | 5.14 | seen 2026-09-26 (search result) | https://www.digikey.com/en/products/detail/FXP831.07.0100C/931-1121-ND/2690271 | Sticks to a fin on the back cover. Any 2.4 GHz FPC antenna up to 45 x 7 mm with a U.FL lead of at least 100 mm works.
U3 | 1 | Adafruit MiniBoost 5V @ 1A | TPS61023 booster, EN pin, output fully disconnected when off | Adafruit | 4654 | 3.95 | 3.95 | seen 2026-09-26 | https://www.adafruit.com/product/4654 | Replaces the Pololu U3V16F5, which does not disconnect its output when disabled (the battery reaches the HAT through the inductor and diode).
U4 | 1 | TP4056 USB-C Li-ion charger module with protection | 1 A charge, DW01A + FS8205A protection, B+/B- and OUT+/OUT- pads | Amazon / AliExpress | search: "TP4056 Type-C protection" | 1.00 | 1.00 | typical (10-packs ~$8-10) |  | The XIAO's own charger gives 100 mA (about 50 h for 5000 mAh); this one charges in about 5-6 h. Some USB-C modules lack the CC resistors and only charge from a USB-A to C cable.
BT1 | 1 | LiPo battery 3.7 V 5000 mAh | 6 x 60 x 100 mm (6060100), protection circuit, JST-PH 2.0 lead | Amazon / YDL | 6060100 | 16.00 | 16.00 | typical | https://ydlbattery.com/products/3-7v-5000mah-6060100-lithium-polymer-ion-battery | No thicker than 6 mm: the case is 13 mm deep. JST-PH polarity is not standard: check red/black with a meter.
SW1-SW3 | 3 | Tactile switch 12 x 12 x 4.3 mm | flat plunger, through-hole | DigiKey | Omron B3F-4000 | 0.55 | 1.65 | typical |  | The flat-plunger B3F; the printed caps press it. Any 12 x 12 x 4.3 mm tactile switch works.
R1-R2 | 2 | Resistor 220 kOhm 1% | 1/4 W through-hole | DigiKey | Yageo MFR-25FBF52-220K | 0.10 | 0.20 | typical | https://www.digikey.com/en/products/detail/yageo/MFR-25FBF52-220K/9138096 | Battery divider.
R3 | 1 | Resistor 1 kOhm 1% | 1/4 W through-hole | DigiKey | Yageo MFR-25FBF52-1K | 0.10 | 0.10 | typical |  | In series with the HAT RST line.
R4 | 1 | Resistor 4.7 kOhm 1% | 1/4 W through-hole | DigiKey | Yageo MFR-25FBF52-4K7 | 0.10 | 0.10 | typical |  | Pull-down on MiniBoost EN.
C1 | 1 | Capacitor 100 nF | 50 V X7R, radial | DigiKey | KEMET C320C104J5R5TA7301 | 0.30 | 0.30 | typical |  | Battery divider filter.
C2 | 2 | Capacitor 47 uF 10 V | X5R ceramic, 1210 | DigiKey | Murata GRM32ER61A476KE20L | 0.45 | 0.90 | typical |  | 5 V rail at the HAT, two in parallel. Each lies flat across two protoboard pads.
C3 | 2 | Capacitor 100 uF 6.3 V | X5R ceramic, 1210 | DigiKey | Murata GRM32ER60J107ME20L | 0.55 | 1.10 | typical |  | Battery rail at the booster input, two in parallel.
J1 | 1 | JST-PH 2-pin pigtail | female plug with ~10 cm leads, 2.0 mm pitch | Amazon / Adafruit |  | 0.50 | 0.50 | typical |  | Takes the battery's plug; its leads solder to the carrier.
J4 | 1 | JST-PH 4-pin plug and socket, pre-wired pair | 2.0 mm pitch, 28 AWG leads of 20 cm or longer | Amazon / AliExpress | search: "JST PH 2.0 4 pin male female" | 1.00 | 1.00 | typical (10-pair packs ~$8) |  | Inline in the button lead, so the frame and the back cover come apart. J2 and J3 have no connector: the wires solder straight into the carrier, where there is no room for one.
 | 1 | 40-pin FFC, 0.5 mm pitch, same-side contacts | 150 mm (type A) | Amazon / AliExpress |  | 2.00 | 2.00 | typical |  | Only if the kit's flat cable is too short: it has to reach from the adapter board to the HAT with the back cover propped open, about 10 cm.
PCB1-PCB2 | 1 | Protoboard | 9 x 15 cm double-sided, 2.54 mm | Amazon / AliExpress |  | 2.50 | 2.50 | typical (5-packs ~$10-12) |  | Both boards come out of one: the carrier (27 x 13 holes, up to 70 x 35 mm) and the button strip (84 x 20 mm, 32 holes long). A 5 x 7 cm board is too short for either.
 | 1 | Hook-up wire | 26 AWG silicone (power), 28-30 AWG (signals) | Adafruit | 2517 / 2513 | 5.00 | 5.00 | typical | https://www.adafruit.com/product/2517 | Leftovers are fine.
SW4 | 1 | Wire link | a short piece of the hook-up wire |  |  | 0.00 | 0.00 |  |  | Joins the charger's OUT+ to VBAT_SYS. A slide switch fits the same holes, but it would be sealed inside the case.
M1-M4 | 4 | Neodymium disc magnet N52 | 20 x 3 mm, nickel plated, axially magnetised | Supreme Magnets / K&J / Amazon |  | 1.00 | 4.00 | typical | https://suprememagnets.com/products/n52-neodymium-magnet-disc-20mm-od-x-3mm-h | About 4.3-5.4 kg pull each on thick steel. Hidden inside the back cover.
 | 4 | Steel disc | round, 20 mm across (up to 20.3), 1.5-2 mm thick, mild (magnetic) steel | Hardware store |  | 0.25 | 1.00 | typical |  | One on each magnet, inside the case, like a pot magnet's cup. Steel blanks sold for magnets, or M10 flat washers (DIN 125, 20 mm across, 2 mm). The pockets are round: squares don't fit.
 | 4 | Rubber pad | self-adhesive, 25 mm across, 0.5-1 mm thick | Amazon / hardware store |  | 0.75 | 3.00 | typical (pack) |  | Over each magnet on the back: grip on the door and no scratches.
 | 1 | Steel rod 3 mm | mild steel, 1 m (0.75 m used) | Hardware store |  | 4.00 | 4.00 | typical |  | Stiffens the thin case: 2 straight rods across the back, 4 bent L-rods in the frame corners. Cut list in hardware/enclosure/README.md.
 | 1 | Two-part epoxy | 30-minute or slower | Hardware store |  | 7.00 | 7.00 | typical |  | Rods, magnets and steel discs. Optional on the frame joints.
 | 9 | M3 heat-set insert + M3 x 6 countersunk screw | insert 4 mm long (hole 4.0 x 4 mm); flat-head screw ISO 10642 | Adafruit / Amazon | 4255 or similar | 0.25 | 2.25 | typical ($5.95 / 50 inserts) | https://www.adafruit.com/product/4255 | Back cover to frame. Countersunk, so the heads sit flush.
 | 1 | M2.5 hardware kit | 2 heat-set inserts + 2 x M2.5 x 5 pan head (button strip); 4 x M2.5 x 8 and 2 x M2.5 x 6 countersunk + 6 nuts (HAT, carrier) | Amazon |  | 2.00 | 2.00 | typical
 | 250 | PETG filament (g) |  | Polymaker / Prusament / Elegoo |  | 0.02 | 5.00 | seen 2026-09-26 (~$19-25/kg) |  | Frame rails ~51 g, back halves ~110 g, caps ~2 g, desk stand ~70 g (estimates from the STL volumes).
 | 1 | Foam tape | 1 mm double-sided EVA/PE foam, 0.5 mm for the window gasket | Amazon |  | 5.00 | 5.00 | typical |  | Holds the panel flat without point loads.
 | 1 | Kapton tape | 10 mm | Adafruit | 3057 | 3.00 | 3.00 | typical | https://www.adafruit.com/product/3057 | Insulates the back of the boards.
 | 3 | Zip tie, 2.5 mm wide | 100 mm or longer | Hardware store / Amazon |  | 0.05 | 0.15 | typical |  | Hold the button wires in the tie blocks up the middle of the back cover.

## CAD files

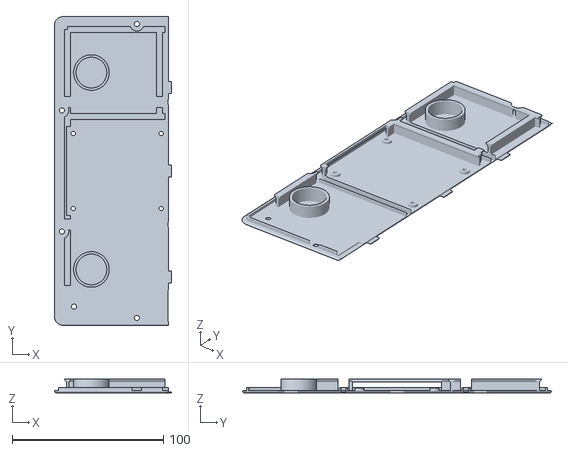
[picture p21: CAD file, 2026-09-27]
hardware/enclosure/stl/back_left.stl
77.5 x 204.0 x 9.42

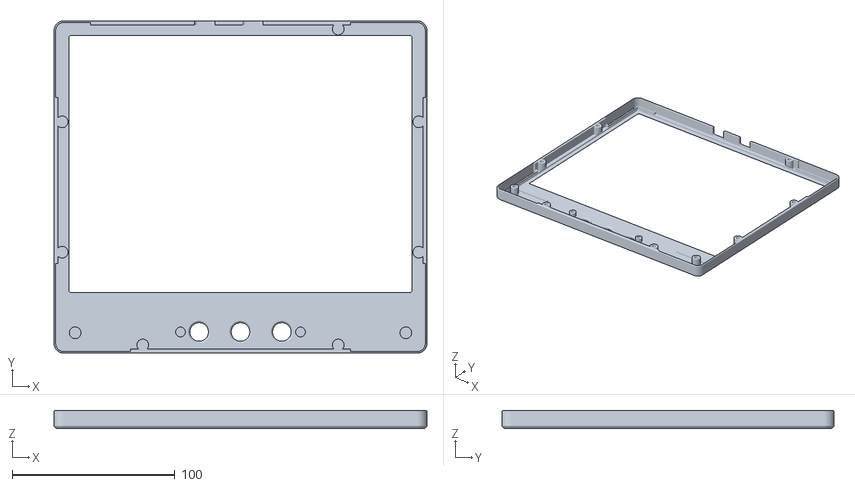
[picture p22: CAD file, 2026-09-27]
hardware/enclosure/stl/one-piece/bezel.stl
229.0 x 204.0 x 11.2

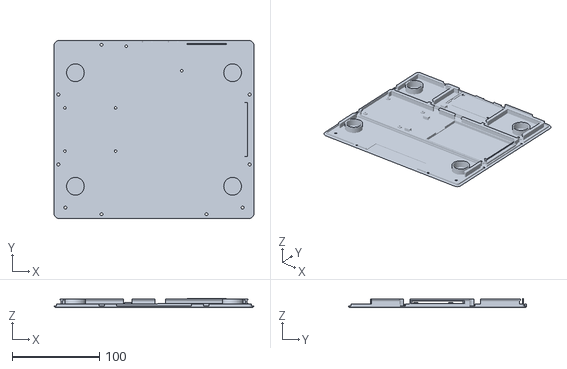
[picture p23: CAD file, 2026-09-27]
hardware/enclosure/stl/one-piece/back.stl
229.0 x 204.0 x 10.0

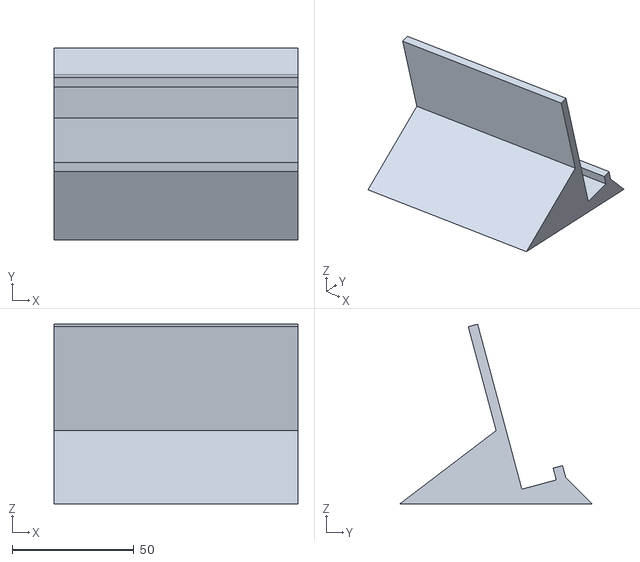
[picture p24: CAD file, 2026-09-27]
hardware/enclosure/stl/stand.stl
100.0 x 78.8 x 73.6

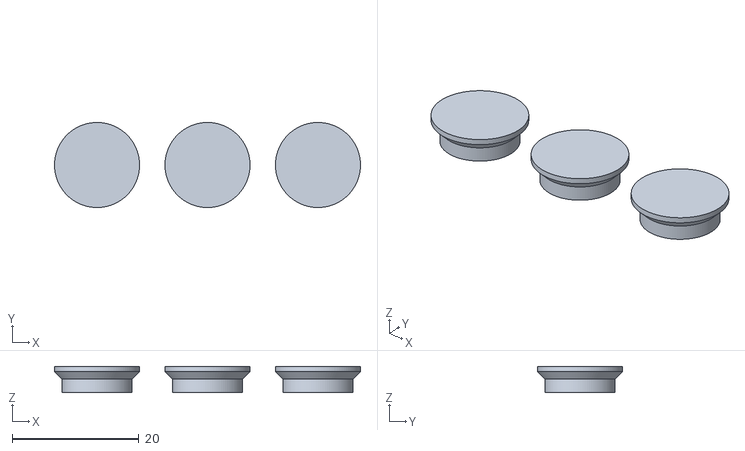
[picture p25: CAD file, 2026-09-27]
hardware/enclosure/stl/button_caps.stl
48.2 x 13.4 x 4.10

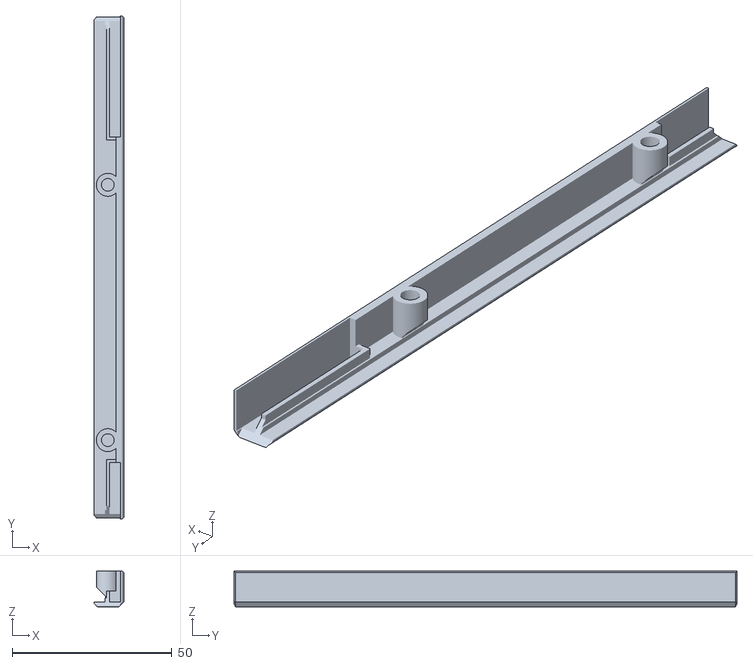
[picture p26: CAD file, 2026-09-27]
hardware/enclosure/stl/bezel_left.stl
9.25 x 157.6 x 11.2

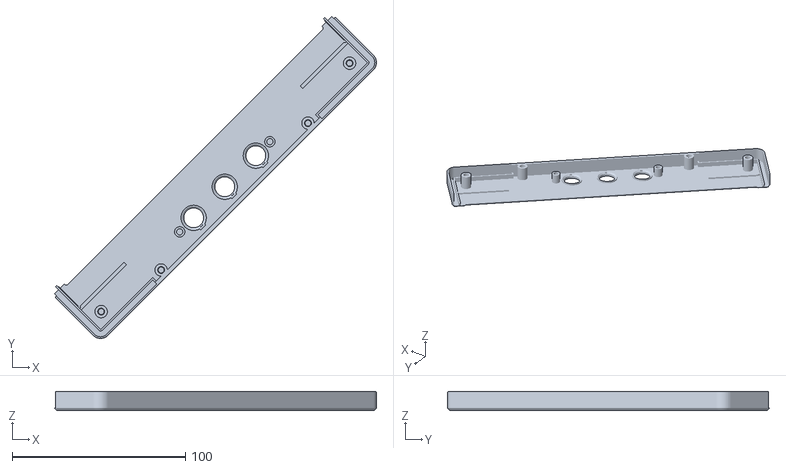
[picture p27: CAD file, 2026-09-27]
hardware/enclosure/stl/bezel_bottom.stl
186.1 x 186.1 x 11.2

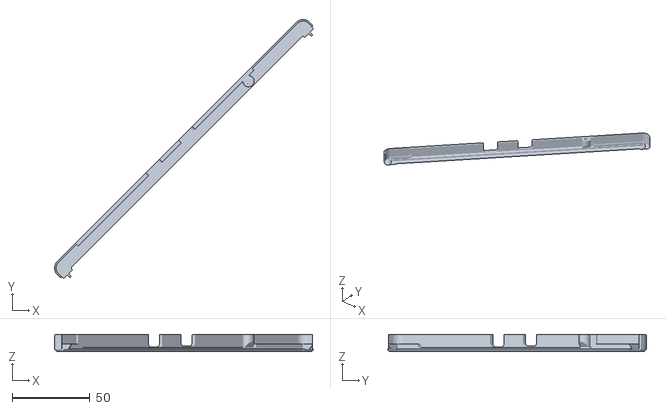
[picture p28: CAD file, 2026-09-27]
hardware/enclosure/stl/bezel_top.stl
166.1 x 166.1 x 11.2

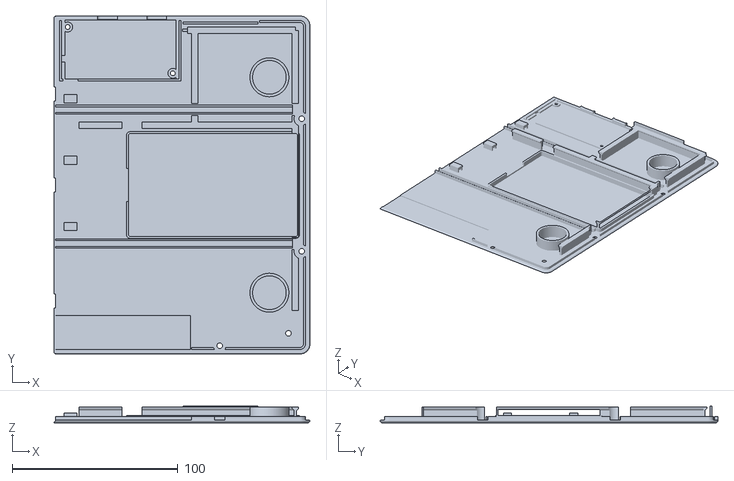
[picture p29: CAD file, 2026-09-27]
hardware/enclosure/stl/back_right.stl
154.5 x 204.0 x 10.0

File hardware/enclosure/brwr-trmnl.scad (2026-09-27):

// =====================================================================
// brwr-trmnl enclosure: 10.3" e-paper Home Assistant display
// =====================================================================
// A thin printed frame (bezel + back cover, 229 x 204 x 13 mm) that sticks
// to a fridge door with four N52 disc magnets sealed inside the back cover,
// or leans into a small printed desk stand. Steel rods epoxied into
// channels stiffen it and splice the split parts.
//
// Coordinates (front view, looking at the display): origin at the centre
// of the outline, +X right, +Y up, +Z toward the viewer. Z = 0 is the
// back face of the back cover (the face that touches the fridge); the
// front face of the bezel is at Z = depth. All dimensions are mm.
//
// Printable parts (split = true, for a 220 x 220 bed): bezel_top,
// bezel_bottom, bezel_left, bezel_right, back_left, back_right,
// button_caps, stand. One-piece parts for a 250 x 210 bed: bezel, back
// (split = false). Render them all with ./export.sh. Views: assembly,
// exploded, inside (back cover removed), fit_check (module envelopes in a
// see-through enclosure), plates (print jobs on the bed) and clash
// (intersections between parts, modules and rods; empty when all fits).
//
// OpenSCAD 2021.01 or newer. Open the Customizer to change parameters.
// =====================================================================

/* [Part] */
// What to render
part = "assembly"; // [assembly, exploded, inside, fit_check, clash, plates, bezel_top, bezel_bottom, bezel_left, bezel_right, back_left, back_right, button_caps, stand, bezel, back]

/* [Panel: E Ink ED103TC2] */
panel_w = 216.70;        // mm, glass outline width (ED103TC2 spec)
panel_h = 174.41;        // mm, glass outline height (ED103TC2 spec)
panel_t = 0.78;          // mm, panel thickness (ED103TC2 spec)
active_w = 209.66;       // mm, active area width (ED103TC2 spec)
active_h = 157.25;       // mm, active area height (ED103TC2 spec)
border_side = 3.1;       // mm, non-active border to cover left, right and top (spec)
border_bottom = 13.7;    // mm, non-active border to cover at the bottom, FPC side (spec)
pocket_depth = 1.2;      // mm, panel pocket depth (community-measured FrameOS case)
pocket_clear = 0.3;      // mm per side, panel to pocket wall (spec)
pocket_rim_b = 2.0;      // mm, rim below the pocket's bottom edge, outside the flex slot (design)
pocket_relief_d = 1.6;   // mm, relief holes in the pocket corners for the glass corners (design: leaves a web to the rod groove)
gasket_t = 0.5;          // mm, foam gasket on the window lip (spec)
back_foam_t = 1.0;       // mm, foam strips between the ribs and the panel (lead)
back_foam_squeeze = 0.3; // mm, foam compression when the back cover is screwed on (design)

/* [Panel flex (FPC)] */
fpc_w = 141;             // mm, flex width at the panel's bottom edge (spec)
fpc_zone = [144, 40];    // mm, keep-clear zone behind the panel's bottom centre, W x H (spec)
fpc_relief_w = 144;      // mm, relief slot width along the pocket's bottom edge (spec >= 141)
fpc_relief_d = 3.0;      // mm, relief slot depth below the pocket edge (spec >= 3)
fpc_adapter = [30, 15, 4]; // mm, e-Paper Adapter board envelope (estimate, exact size unknown)
fpc_t = 0.3;             // mm, flex thickness incl. stiffener (estimate)
fpc_bend = 1.5;          // mm, how far the 180 deg bend reaches below the panel edge (estimate)

/* [Enclosure] */
outer_w = 229;           // mm, outer width (spec target ~229)
outer_h = 204;           // mm, outer height (spec target ~204)
depth = 13;              // mm, total depth incl. back cover (lead: 13; the charger's USB-C sets the minimum, see the console)
border_top = 6;          // mm, panel top edge to outer top edge (spec ~6)
corner_r = 6;            // mm, outline corner radius (spec ~6)
wall_t = 2.5;            // mm, side walls (spec)
front_t = 1.6;           // mm, front face (lead)
back_t = 1.8;            // mm, back cover plate (lead)
front_chamfer = 1.5;     // mm, 45 deg chamfer on the front outer edge (design)
back_chamfer = 1.0;      // mm, 45 deg chamfer on the back outer edge (design)
seam_chamfer = 0.5;      // mm, V-groove where bezel and back cover meet, and on the rail joints (design)
window_chamfer = 1.1;    // mm, 45 deg chamfer on the window's front edge (spec: 45 deg; land + chamfer = front_t)
window_land = 0.5;       // mm, straight land behind the window chamfer (design)
window_r = 1.0;          // mm, window corner radius (design)
lip_t = 1.2;             // mm, locating lip on the back cover, inside the walls (design)
lip_h = 2.0;             // mm, locating lip height (design)
lip_clear = 0.25;        // mm, lip to wall clearance (design)
print_gap = 4;           // mm, spacing between caps on the bed (design)

/* [Print bed and split] */
bed_size = [220, 220];   // mm, printer bed (FlashForge Adventurer 5M); one-piece parts need [250, 210]
bed_margin = 5;          // mm, strip along the bed edge that is not used (lead)
split = true;            // split bezel and back cover to fit bed_size; false: one-piece bezel and back
bezel_lap = 4;           // mm, rail joints: the inner half of the side wall runs this far past the outer half (design)
rail_angle = 45;         // deg, the top rail and the chin turn on the bed so they fit (lead)
back_split_x = -39;      // mm, back cover seam on its inner face (lead)
scarf_land = 0.4;        // mm, straight land at both ends of the back cover's 45 deg scarf (design)
back_tab_y = [-70, 0, 55]; // mm, alignment tabs across the back cover seam (design: clear of the rods)
back_tab = [2, 8, 0.8];  // mm, tab length past the seam, width, thickness (design)
tab_clear = 0.2;         // mm, tab to pocket clearance (design)
seam_clear_min = 1.5;    // mm, back cover seam and bezel joints to any feature (lead)
tie_seam_min = 4;        // mm, back cover seam to the zip-tie blocks (lead)
rib_seam_clear = 1.5;    // mm, ribs stop this far from the back cover seam (design)
plate_gap = 10;          // mm, gap between parts that share a print job (design)

/* [Driver board: Waveshare e-Paper IT8951 Driver HAT (B)] */
drv_size = [65, 56.5];   // mm, RPi HAT footprint, long x short edge (Waveshare)
drv_pos = [-73, 0];      // mm, board centre; the short FFC edge faces +X (spec)
drv_pcb_t = 1.6;         // mm (Waveshare)
drv_hole_inset = 3.5;    // mm, M2.5 hole centres from the edges, 58 x 49 pattern (Waveshare)
drv_hole_d = 2.75;       // mm, M2.5 mounting holes (Waveshare)
drv_stub_h = 1.0;        // mm, clipped 2x20 header pins left on the back (lead: header removed)
drv_stub_size = [50.8, 5.1]; // mm, where the header was, along the +Y long edge (standard 2x20)
drv_comp_h = 3.0;        // mm, tallest part on the panel side (lead: tall socket and pin headers removed)
drv_air_min = 1.5;       // mm, minimum air gap from components to the panel (spec)
drv_standoff_h = 1.5;    // mm, printed standoffs, back plate to PCB (lead ~1.5, clears the stubs)
drv_standoff_d = 6;      // mm, standoff diameter (design)
drv_screw_len = 8;       // mm, M2.5 x 8 countersunk (ISO 10642) from outside into a nut on the component side
drv_ffc_socket = [5, 30, 2.0]; // mm, FFC socket envelope on the +X edge, X x Y x Z (estimate)
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

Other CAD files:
hardware/enclosure/stl/bezel_right.stl

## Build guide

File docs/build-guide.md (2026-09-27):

# Build guide

From a box of parts to a display on the fridge. Plan on a weekend: about a
day of printing, which runs unattended, and an afternoon of soldering and
assembly, plus overnight for the epoxy to cure.

**Before you start**, read the whole guide once, and skim
[wiring.md](../hardware/wiring.md) and the
[schematic](images/schematic.svg).

| You need | |
|---|---|
| Parts | [Bill of materials](bom.md) |
| Tools | Soldering iron with a fine tip and a heat-set insert tip, multimeter, flush cutters, wire strippers, tweezers, hobby knife, a drill or pin vise with a 2.7 mm bit, hex keys (1.5 and 2 mm) and a small screwdriver, small pliers or a 5 mm nut driver, a vise or pliers for bending rod, a hacksaw or bolt cutters |
| Printer | Bed at least **220 × 220 mm** |
| Computer | Chrome or Edge to flash from the browser, or PlatformIO |
| Home Assistant | With the Mosquitto broker; see [home-assistant.md](home-assistant.md) |

The case is 229 × 204 × **13 mm**. There's no spare room in it, so the parts
have to be low: the steps below say where to trim.

> **Handle the panel with care.** It's 0.78 mm glass. Pick it up by its
> edges, keep it flat on its foam, never crease its flex cable or bend it
> sharply (in step 9 it folds back over the panel in a gentle curve), never
> press on its face, and keep it in its box until step 8.

## 1. Print the enclosure

Print in PETG, 0.2 mm layers, 3–4 walls, 20% infill, **no supports**. The
frame is four rails and the back cover two halves, so every part fits a
220 × 220 mm bed; the two long rails print diagonally. The STLs are in
[`hardware/enclosure/stl/`](../hardware/enclosure/stl/);
[`hardware/enclosure/README.md`](../hardware/enclosure/README.md) has the
details.

The four print jobs on a 220 × 220 mm bed

| Print job | Parts | Orientation |
|---|---|---|
| 1 | `bezel_bottom.stl` (the chin) + `button_caps.stl` | Face down; the chin turned 45° |
| 2 | `bezel_top.stl` + `bezel_left.stl` + `bezel_right.stl` | Face down; the top rail turned 45° |
| 3 | `back_right.stl` | Outside face down |
| 4 | `back_left.stl` + `stand.stl` (optional) | Outside face down; stand on its base |

With a bed of 250 × 210 mm or more you can print the frame and the back each
in one piece instead (`stl/one-piece/`).

Let the parts cool on the bed so they stay flat.

## 2. Heat-set inserts

With the insert tip at about 230 °C for PETG, press each insert in square
and flush, and let it cool before moving on.

- **Frame rails:** 9 × M3 in their bosses (for the back cover).
- **Chin:** 2 × M2.5 in the bosses behind it (for the button strip).

## 3. Prepare the driver HAT

The driver board comes shaped to sit on a Raspberry Pi. This build doesn't
use a Pi, and those parts are too tall for the case.

1. **The 40-pin Pi header on its back.** Cut the black plastic body away with
   flush cutters, a bit at a time, then clip the metal pins flush with the
   board: no more than 1 mm may stick out. Take care not to lever on the
   board or cut into it.
2. **The tall parts on its front.** Nothing on the component side may stand
   more than 3 mm. Desolder the white 8-pin cable socket (or cut its housing
   away), and clip or desolder any upright pin header.
3. **The 8 wires.** Cut the plug off the kit's 8-wire cable. Solder the wires
   to the HAT's 5V, GND, MISO, MOSI, SCK, CS, RST and HRDY pads, matching its
   silkscreen, and note which colour went where. Their other ends go to the
   carrier in the next step.
4. **Interface switch:** set it to **SPI**.

## 4. Build the carrier board

Follow [the carrier layout](images/carrier-layout.svg), viewed from the
component side.

Cut a piece of protoboard **27 holes wide and 13 holes tall**. Score the top
edge along the next row of holes up, so a row of half holes stays on that
edge (a wire runs in the margin there), and the other three edges midway
between holes; score both sides and snap it. That gives 68.6 × 34.3 mm.
Anything up to the layout's 70 × 35 mm fits, because the screws, not the
edges, place the board. Then drill the two mounting holes, 2.7 mm, each
through the middle of the four holes in a corner: top left and bottom
right, seen from the component side. The drill centres itself there.

1. **Prepare the XIAO.** Its BAT+ pad is on the underside: solder a short
   26 AWG wire to it first, to pass through the hole beneath it. (BAT−, the
   pad nearer the USB connector, is the same as GND and needs no wire.)
2. **Place, don't solder yet:** the XIAO, the charger module and the
   MiniBoost, all flat on the board, not on headers. The XIAO's pads go on
   the holes the layout shows, which puts its connector where the case's
   slot is; its end hangs 0.3 mm over the board's top edge. Put the charger
   module's end level with the XIAO's, no further out: the case's top wall
   is there.
3. **Solder the modules**, and the XIAO's battery wire through the board.
   Glue the charger module down with a thin layer of epoxy or double-sided
   tape: its four wires alone won't take the force of plugging in a cable.
4. **Add the passives:** R1–R4 and C1 lying flat, and the four ceramic
   capacitors, C2 (2 × 47 µF) and C3 (2 × 100 µF), each soldered flat
   across two adjacent pads.
5. **The battery pigtail (J1) and SW4:** solder the JST-PH pigtail's leads
   where the layout shows J1, and a wire link at SW4. The link joins the
   charger's output to everything else: without it nothing gets power. (A
   switch fits there too, but it would be sealed inside the case.)
6. **Wire the underside** as the layout shows: thick (26 AWG) wire for the
   battery, `VBAT_SYS`, 5 V and ground; thin wire for the signals. Every
   ground goes to the charger's **OUT−**, never to **B−**.
7. **J2 and J3: wires straight into the board.** There's no room for
   connectors here.
   - **J2:** cut the HAT's 8 wires to about 12 cm (the route in the
     [wiring diagram](images/wiring.svg), with a little slack) and solder
     them into J2's holes: 5V, GND, MISO, MOSI, SCK, CS, RST, HRDY from the
     top. The HAT and the carrier are now one assembly.
   - **J3:** take one half of the JST-PH 4-pin pair (J4), cut its wires to
     about 17 cm and solder them into J3's holes: BACK, REFRESH, NEXT, GND
     from the top.
8. **Keep it low.** Nothing may stand taller than the MiniBoost, 5.6 mm
   above the board, and the joints underneath must be trimmed to 1.2 mm:
   the MiniBoost ends up only 1.1 mm from the back of the panel.
9. **Check it** with the meter before connecting anything: no short from
   `VBAT_SYS` or the HAT's 5V pad to ground, and each HAT pad and each pin
   of the JST-PH plug reaching the right XIAO pin
   ([pin table](../hardware/wiring.md#xiao-esp32-s3-pins)).
10. Cover the underside with Kapton tape.

## 5. Build the button strip

Follow [the button board drawing](images/button-board.svg).

1. Cut protoboard to 84 × 20 mm, 32 holes by 7 (or midway between holes,
   81.3 × 17.8 mm). Put the middle switch at the centre, and the other two
   10 holes (25.4 mm) either side, plungers facing the front: the caps are
   the same distance apart. The legs sit 5 holes by 2 holes apart; spread
   them slightly to fit (the grid is a little wider than the legs), press
   each switch flat, solder, and trim the legs to 2 mm under the board.
2. Drill out the 15th hole either side of the centre, on the middle row,
   to 2.7 mm: the second hole in from each end.
3. **Ground:** each switch's bottom-right leg (seen from the front) to a bare
   wire along the bottom row.
4. **Signals:** each switch's top-left leg, diagonally opposite its ground
   leg, to its own insulated wire. Diagonal legs are always on opposite
   sides of the switch, whichever way round it's fitted.
5. **The lead:** the other half of the JST-PH pair, its wires cut to about
   7 cm, which reaches the plug with the back cover propped open (step 9).
   Plug the two halves together, find with the meter which of this
   half's wires meets J3's BACK, REFRESH, NEXT and GND, and solder each into
   its hole on the strip as the drawing shows: the signals on the top row
   above BACK, GND at the end of the bus. From the front, BACK is on the
   left. Keep the wires clear of the two screw holes.
6. With the pair plugged together, check with the meter at the carrier:
   each of D0–D2 reads open to ground, and closed while its button is
   pressed.

## 6. Check the battery lead

JST-PH batteries don't all use the same polarity, and a reversed battery
destroys the charger module the moment it's plugged in. So before the
battery goes near the carrier, find its plug's positive pin with the meter,
then check which lead of the carrier's pigtail is wired to the charger's
**B+**. They must meet. If they don't, swap the two wires in the battery's
plug (lift each plastic latch with a pin and slide the contact out), or buy
a battery with the other polarity.

## 7. Flash the firmware

1. **Get the firmware.** On GitHub, open **Actions › Firmware**, pick the
   latest green run, download the **brwr_trmnl** artifact (you need to be
   signed in) and unzip it. You want `merged_firmware.bin`. Or build it
   yourself (below).
2. **Connect the XIAO** to your computer with a USB-C data cable, using the
   XIAO's own port (not the charger module's).
3. **Flash from the browser.** Open
   [Espressif's esptool-js page](https://espressif.github.io/esptool-js/)
   in Chrome or Edge, click **Connect** and pick the XIAO's serial port.
   Set the flash address to `0x0`, choose `merged_firmware.bin`, and click
   **Program**.
   - No serial port? Hold the XIAO's **BOOT** button, press and release
     **RESET**, then release BOOT, and connect again.

From a terminal instead:

```sh
pip install esptool
esptool --chip esp32s3 write-flash 0x0 merged_firmware.bin
```

`merged_firmware.bin` is for the first flash: it also clears the saved Wi-Fi
and settings. To update a display that's set up, write `firmware.bin` (in the
same artifact) at `0x10000` instead, or upload with PlatformIO (below).

To build it yourself (the first build downloads the ESP-IDF toolchain and
takes a while):

```sh
pip install platformio
cd firmware
pio run -e brwr_trmnl -t upload
pio device monitor              # the log, at 115200 baud
```

Flash the `brwr_trmnl` build. The `brwr_trmnl_arduino` build is only a
fallback: it can't light-sleep, so in **Always ready** it stays fully awake
and empties the battery in about a week.

## 8. Test it on the bench

Before anything goes into the case, prove the panel, the HAT and the
firmware work together.

1. Lay the panel face down on its foam, clean and flat. Connect its flex to
   the small adapter board, and the adapter board to the HAT with the 40-pin
   flat cable: lift each connector's latch, slide the cable in square, close
   the latch. Check the contacts face the right way (Waveshare's manual has
   photos).
2. Plug in the button strip's lead (J4), the Wi-Fi antenna (press the U.FL
   plug straight down until it clicks), and last, the battery.
3. The display draws the TRMNL logo, then setup instructions. If it stays
   blank, see [troubleshooting](#troubleshooting).
4. **Set it up:** join the Wi-Fi hotspot `brwr-trmnl-XXXXXX` from a phone;
   the setup page opens (or go to `http://4.3.2.1`). Pick your Wi-Fi, and
   fill in the **Home Assistant** section: its address, where screens come
   from, the MQTT user and password, and the **panel VCOM** printed on the
   panel's flex cable (such as `-1.52`). Details:
   [home-assistant.md](home-assistant.md#2-connect-the-display).
5. Within a minute or so it draws its first screen and appears in Home
   Assistant. Press each button: NEXT and BACK change the screen, and
   **Last refresh** updates in Home Assistant.
6. Plug a USB-C charger into the charger module's port: its LED turns red
   while it charges.

Before assembly, unplug the battery, the flat cable at the HAT and the
button lead (J4). The antenna can stay plugged into the XIAO: it goes on the
back cover too.

## 9. Assemble

Work on a clean, flat, soft surface. Clean the inside of the window and the
panel's face with a blower or a soft brush; any dust in there stays there.

**Cut and bend the rods.** From the 3 mm steel rod, following the
[cut list](../hardware/enclosure/README.md#steel-rod-cut-list): two straight
206 mm rods for the back, and four L-rods for the frame's corners (top-left
40 + 40 mm, top-right 15.5 + 40 mm, bottom-left and bottom-right
40 + 48 mm). Bend each L over a 3 mm pin held in a vise so the inside of the
bend is tight. Dry-fit every rod in its groove before mixing any epoxy.

**The back cover** (both halves outside face down on the table):

1. **Magnets.** Into each of the four pockets, drop a magnet, all with the
   **same side facing out**, then a steel disc on top of it, and fill the
   pocket with epoxy to just over the disc. Nothing metal shows outside.
   The magnets pull hard toward each other and toward steel: keep them apart
   and away from the rods until they're set in.
2. **Join the halves.** Slide the three tabs on `back_left` into the pockets
   under `back_right` so the seam closes flat. Epoxy the two 206 mm rods into
   their channels across the seam; they hold the halves together. Glue on
   the seam itself is optional. Let it cure flat, weighted if needed.
3. Once cured, stick a rubber pad over each magnet on the outside face.

**The frame** (the four rails front face down on the table):

4. **Rails.** Push them together at the corners: each side rail slides in
   between the top rail and the chin, and the joints line up the front faces.
   Epoxy the four L-rods into the corner grooves; they bridge the joints and
   they're structural, not optional. Glue on the joint faces is optional.
   Let it cure flat.
5. **Button caps.** From inside, drop the three caps into their holes in the
   chin, faces first, with the key on each stem towards the bottom so the
   symbols read ◀ ● ▶ from the front.
6. **Button strip.** Screw it onto the two M2.5 inserts in the chin
   (M2.5 × 5), switches facing the caps. Press each cap from the front: it
   should click and spring back.
7. **Gasket.** Run the 0.5 mm foam tape around the window lip, in four
   straight strips, without covering the window.
8. **Panel.** Lower the panel face down into its pocket, flex edge towards
   the chin, and let it settle. Fold the flex gently back over the panel's
   back without creasing it, so the adapter board lies behind the panel's
   bottom centre.

**The electronics** (into the back cover, inside facing up):

9. **Driver HAT.** Components facing up (towards the panel), its 40-pin
   flat-cable socket towards the centre, on its four low standoffs: M2.5 × 8
   countersunk screws from the outside, nuts on top. The carrier is wired
   to it, so keep it close.
10. **Carrier.** Into its recess at the top edge, USB-C connectors outwards,
    with M2.5 × 6 countersunk screws from the outside and nuts on top. Lay
    the HAT's wires through the wire gap in the rib, as the
    [wiring diagram](images/wiring.svg) shows.
11. **Antenna.** Peel the FPC antenna and stick it to the thin fin along the
    top edge, right of the carrier (seen from inside), on the fin's face
    towards the middle of the case, its lead at the carrier's end. Its coax
    runs over the carrier to the XIAO's U.FL socket: if it isn't plugged in
    already, press the plug straight down until it clicks.
12. **Battery.** Foam pad in its recessed cradle, battery on top, its lead
    out through the cradle's slot and the gap in the rib above it, to J1.
    Nothing may press on the cell or pierce it.

**Together:**

13. **Connect.** Prop the back cover open along the frame's bottom edge at
    about 45° (lean it against something), inside facing the frame. Connect
    the flat cable from the adapter board to the HAT, and the button strip's
    plug to its mate (J4), then plug in the battery. The flat cable needs
    about 10 cm to reach at that angle; with a shorter one, work with the
    cover nearer closed, or use a longer cable (see the
    [BOM](bom.md)). Lay J4 flat on the back cover beside
    the adapter board, not under it, with the strip's spare lead beside it,
    and zip-tie the button wires to the three tie blocks. Put foam strips on
    the rib tops and the magnet tubes.
14. **Close.** Fold the back cover down onto the frame, checking that no wire
    is pinched at the edges, the antenna's fin slides in beside the top
    wall, and the USB-C connectors meet their slots in it (**USB** and
    **CHARGE**). Drive the nine M3 × 6 screws in a cross pattern, snug only.
    Plug a cable into each USB-C port from outside to check it seats.

## 10. Hang it

1. Test the spot on your fridge with any magnet: many stainless-steel doors
   aren't magnetic ([magnets.md](magnets.md#will-it-work-on-my-fridge)).
2. Wipe the spot clean and dry, and put it on, flat.
3. Open and slam the door a few times with a towel on the floor below.
4. Check **Wi-Fi signal** in Home Assistant. Better than about −75 dBm is
   fine.

**On a wall** (the back is too thin for keyholes): screw a thin steel plate
to the wall, for example 1 mm galvanised steel of about 200 × 150 mm, or four
30 × 30 mm squares at the magnets' positions, 90 mm either side of the
centre and 65 mm above and below it. The magnets hold the frame on it. Or
stand it on the desk stand.

## 11. Make it yours

- **Screens:** Home Assistant dashboards or TRMNL plugins,
  [home-assistant.md](home-assistant.md#4-home-assistant-screens).
- **Voice:** [voice.md](voice.md).
- **Battery life:** choose **Always ready** or **Deep sleep**,
  [power.md](power.md).

## Troubleshooting

| Symptom | Check |
|---|---|
| Nothing on the panel at all | HAT interface switch on SPI; both flat-cable latches closed with the cable square; the 8 HAT wires on the right pads; the battery charged. The log (`pio device monitor`) says whether the IT8951 answered |
| Log says the IT8951 didn't answer | SCK/MOSI/MISO/CS swapped; HRDY not connected; the MiniBoost not switching on (its OUT pin should read 5.2 V while the display draws) |
| Washed-out or smudged picture | Panel VCOM: enter the value printed on the flex cable |
| Resets when it starts to draw | Battery flat, or C2/C3 missing; ground to the HAT too thin or too long |
| Buttons do nothing | Each switch must connect its signal wire to ground when pressed; the cap must reach the plunger (press it: it should click) |
| **Last error** says "Button stuck down" | That switch is pressed all the time: a cap pressing on it (see `cap_preload` in the [enclosure README](../hardware/enclosure/README.md)) or a solder bridge on the button strip. It's ignored until the first refresh after it's released |
| Doesn't wake from a button in deep sleep | The buttons must be on D0–D2 (GPIO1–3) |
| No setup hotspot | Hold REFRESH for 5–15 seconds to open it again |
| Doesn't appear in Home Assistant | The MQTT user and password; the broker's log; [home-assistant.md](home-assistant.md#troubleshooting) |
| Weak Wi-Fi | The antenna stuck flat on its fin; its coax clicked onto the U.FL socket; no wire or metal lying over it |
| Case won't close flat | Something is too tall: trim the carrier's joints (1.2 mm) and the strip's legs (2 mm); check the HAT's clipped header pins, and that the button plug lies flat beside the adapter board |
| Battery reads wrong | R1 and R2 must both be 220 kΩ; the divider midpoint goes to D3 |
| Charges from USB-A but not from a USB-C charger | The charger module lacks the USB-C CC resistors ([power.md](power.md#charging)) |

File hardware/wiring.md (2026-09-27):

# Wiring

Everything sits on one hand-wired carrier board (70 × 35 mm protoboard) plus a
button strip. The display's driver HAT is wired to the carrier with the 8-wire
cable that comes in its box, its plug cut off.

| | |
|---|---|
| Schematic | The circuit ([schematic.svg](../docs/images/schematic.svg)) |
| Wiring, from the back | Where everything goes, seen from the back through the back cover's plate ([wiring.svg](../docs/images/wiring.svg)) |
| Carrier layout | Carrier board layout ([carrier-layout.svg](../docs/images/carrier-layout.svg)) |
| Button board | Button strip ([button-board.svg](../docs/images/button-board.svg)) |

The diagrams are generated by the scripts in [`diagrams/`](diagrams/); edit
those rather than the SVGs.

## XIAO ESP32-S3 pins

| Pin | GPIO | Net | Goes to | Notes |
|---|---|---|---|---|
| D0 | 1 | BTN_BACK | SW1 BACK, other side to GND | Internal pull-up; wakes it from deep sleep |
| D1 | 2 | BTN_REFRESH | SW2 REFRESH, other side to GND | Internal pull-up; wakes it. Hold 5 s: Wi-Fi setup; 15 s: reset |
| D2 | 3 | BTN_NEXT | SW3 NEXT, other side to GND | Internal pull-up; wakes it |
| D3 | 4 | BATT_SENSE | R1/R2 midpoint, C1 to GND | Half the battery voltage |
| D4 | 5 | EPD_CS | HAT `CS` | |
| D5 | 6 | EPD_EN | MiniBoost `EN`, R4 4.7 kΩ to GND | High = panel powered |
| D6 | 43 | EPD_RST | R3 1 kΩ, then HAT `RST` | GPIO43 is the boot log's TX pin, hence the resistor |
| D7 | 44 | EPD_HRDY | HAT `HRDY` | Controller ready |
| D8 | 7 | EPD_SCK | HAT `SCK` | 12 MHz |
| D9 | 8 | EPD_MISO | HAT `MISO` | |
| D10 | 9 | EPD_MOSI | HAT `MOSI` | |
| BAT+ pad (back) | | VBAT_SYS | charger `OUT+` | Pad farther from the USB connector |
| BAT− pad (back) | | GND | | Nearer the USB connector. Already the same as the GND pin: no wire needed |
| 5V, 3V3 | | | not connected | |
| U.FL | | | FPC antenna | Always plug the antenna in before Wi-Fi is on |

These match [`firmware/include/brwr/board.h`](../firmware/include/brwr/board.h)
and the `BOARD_BRWR_TRMNL` section of
[`firmware/include/config.h`](../firmware/include/config.h). If you change a
pin, change it there too. The three buttons must stay on GPIO 0–21 (the RTC
pins), or they can't wake the ESP32-S3.

## Power

```
 LiPo + ──► charger B+          charger OUT+ ──► (SW4) ──► VBAT_SYS ─┬─► XIAO BAT+
 LiPo − ──► charger B−          charger OUT− ──► GND                 ├─► MiniBoost VIN ──► 5 V ──► HAT 5V
                                                                     ├─► R1 220k ─┬─ R2 220k ─► GND
                                                                     │            └─► D3, C1 100 nF ─► GND
                                                                     └─► C3 2 × 100 µF ─► GND
```

- **All grounds go to the charger's `OUT−`,** never to `B−`. The charger
  module's protection switch sits between the two; wiring anything to `B−`
  bypasses it.
- **The MiniBoost only runs while the display is awake.** The ESP32 drives
  its `EN` high (D5) as it starts the display, early in each wake, and low
  again before sleeping. R4 holds it off while the ESP32 boots. With `EN`
  low its output is disconnected from the battery, so the HAT gets nothing
  between wakes.
- **Capacitors:** C3 (2 × 100 µF) at the MiniBoost's input and C2 (2 × 47 µF)
  at the HAT's `5V` wire carry the current surge when the panel's power
  supply starts, so the battery voltage doesn't dip and reset the ESP32.
  They're flat 1210 ceramics, which fit under the panel and have no
  polarity.
- **Battery:** through a JST-PH pigtail soldered to the carrier (J1), not a
  board-mounted socket, which would be too tall.
- **Wire:** 26 AWG for the battery, `VBAT_SYS`, 5 V and ground runs; 28–30 AWG
  for signals. Keep the 5 V and ground to the HAT short and twisted together.
- **SW4** is a wire link, and it's needed: it joins the charger's output to
  everything else. A switch would fit the same holes (charging would still
  work with it off, because the charger sits before it), but it would be
  sealed inside the case. To store the display, unplug the battery.
- **Height:** the case is 13 mm deep, and the carrier sits in a recess with
  the panel 1.1 mm above its tallest part, the MiniBoost (5.6 mm above the
  board). Nothing may stand taller: solder the XIAO, the charger and the
  MiniBoost flat, glue the charger module down, solder the J2 and J3 wires
  straight into the board (there's no room for connectors), and trim the
  joints underneath to 1.2 mm.
- **The HAT's inputs:** while its supply is off, the firmware floats every
  line to the HAT (`panel_release_lines()`), so no pin can power the IT8951
  through its input protection diodes.

## The HAT

- **Interface switch: SPI.** The HAT has a small switch or DIP switches for
  SPI, I80 and I²C. Set it to SPI before powering it.
- **Low profile:** the 40-pin Raspberry Pi header on its back is cut off
  (pins clipped to 1 mm or less), and nothing on its front may stand more
  than 3 mm, so its white 8-pin socket comes off too
  ([build guide](../docs/build-guide.md#3-prepare-the-driver-hat)). It sits
  on 1.5 mm standoffs, component side towards the panel.
- **Wires:** the kit's 8-wire cable with its plug cut off, about 12 cm long.
  One end is soldered to the HAT's 5V, GND, MISO, MOSI, SCK, CS, RST and HRDY
  pads, the other straight into the carrier's J2 holes, 5V at the top, in
  that order. Go by the HAT's silkscreen, not the wire colours.
- **Panel:** the 40-pin flat cable goes from the small adapter board to the
  HAT. Lift the connector latch, slide the cable in square, contacts facing
  the right way (check the photos in Waveshare's manual), and close the latch.
- **VCOM:** the panel's ribbon cable has a label with a voltage such as
  `-1.52V`. Enter it on the setup page (or later in Home Assistant). Each panel
  is different; the wrong value gives a washed-out or smudgy picture.

## The button strip

- **Lead:** four wires from the strip (BACK, REFRESH, NEXT, GND) to the
  carrier's J3, soldered at both ends, with a 4-pin JST-PH pair (J4) inline
  so the frame and the back cover come apart. The plug lies flat on the back
  cover beside the adapter board.
- **No resistors:** each switch pulls its GPIO to ground, against the
  ESP32-S3's internal pull-up.

## Checks before the first power-up

1. **Battery polarity.** JST-PH batteries don't all use the same polarity.
   Measure the plug with a meter: its positive pin must meet the pigtail
   lead that goes to charger `B+`. Reversed, it destroys the charger module
   (and possibly more).
2. **No shorts:** with nothing plugged in, measure resistance between
   `VBAT_SYS` and GND (it should climb slowly as C3 charges from the meter,
   not read 0 Ω), and between the HAT's `5V` and GND.
3. **5 V switch:** with the battery connected and no firmware yet (or D5
   low), the MiniBoost output must read 0 V. It turns on only when the
   firmware draws.
4. **Battery sense:** D3 should read half the battery voltage.

Then flash the firmware ([build guide](../docs/build-guide.md)).

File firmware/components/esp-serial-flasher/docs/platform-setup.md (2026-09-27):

# Platform Setup Guide

This document provides setup instructions for using ESP Serial Flasher on different host platforms to program and interact with ESP devices.

## General Prerequisites

Before setting up any platform, ensure you have the following:

- **[CMake](https://cmake.org/) 3.5 or later** - Build system generator
- **Platform-specific toolchain** - See individual platform sections below

## ESP-IDF Support

**Testing Status**: Regularly tested with all major and minor versions of ESP-IDF from v4.3 to v5.5

### Prerequisites

- **[ESP-IDF](https://docs.espressif.com/projects/esp-idf/) v4.3+** - ESP-IDF development framework

### Setup

ESP Serial Flasher is available as a managed component through the Espressif Component Registry. This is the recommended installation method for ESP-IDF projects.

**Installation:**

1. **Navigate to your ESP-IDF project directory**
2. **Add the component dependency**:
   ```bash
   idf.py add-dependency "espressif/esp-serial-flasher"
   ```
3. **Build your project**:
   ```bash
   idf.py build
   ```

The component will be automatically downloaded and integrated into your project's build system.

**Component Registry**: [espressif/esp-serial-flasher](https://components.espressif.com/components/espressif/esp-serial-flasher/)

### Example Code

See [examples/esp32_example](../examples/esp32_example) for a complete implementation with build instructions.

## STM32 Setup

**Testing Status**: Regularly tested with STM32CubeH7 v1.11.1 and arm-gnu-toolchain-13.2.

### Prerequisites

- **[Git](https://git-scm.com/)** - For cloning with submodules
- **[STM32 HAL libraries](https://www.st.com/en/embedded-software/stm32cube-mcu-mpu-packages.html)** - For your specific target chip family
- **[ARM GCC toolchain](https://developer.arm.com/Tools%20and%20Software/GNU%20Toolchain)** - Cross-compilation toolchain
- **[stm32-cmake](https://github.com/ObKo/stm32-cmake) support package** - Included as submodule

### Setup

1. **Clone the repository with submodules**:

   ```bash
   git clone --recursive https://github.com/espressif/esp-serial-flasher.git
   ```

2. **If already cloned without `--recursive`**, initialize the submodule:

   ```bash
   git submodule update --init --recursive
   ```

### Required CMake Variables

Define these variables when configuring the build:

- `STM32_TOOLCHAIN_PATH`: Path to ARM toolchain
- `STM32_CUBE_<CHIP_FAMILY>_PATH`: Path to STM32 Cube libraries
- `STM32_CHIP`: Target STM32 chip name
- `CORE_USED`: Core used on multicore devices (e.g., M7 or M4)
- `PORT`: Must be set to `STM32`

### Build Example

```bash
cmake \
  -DSTM32_TOOLCHAIN_PATH="/path/to/gcc-arm-none-eabi" \
  -DSTM32_CUBE_H7_PATH="/path/to/STM32Cube_FW_H7" \
  -DSTM32_CHIP="STM32H743VI" \
  -DCORE_USED="M7" \
  -DPORT="STM32" \
  .. && cmake --build .
```

### Alternative: CMake Variables File

Set variables in your top-level `CMakeLists.txt`:

```cmake
set(STM32_TOOLCHAIN_PATH /path/to/gcc-arm-none-eabi)
set(STM32_CUBE_H7_PATH /path/to/STM32Cube_FW_H7)
set(STM32_CHIP STM32H743VI)
set(CORE_USED M7)
set(PORT STM32)
```

### Example Code

See [examples/stm32_example](../examples/stm32_example) for a complete implementation with build instructions.

## Zephyr Setup

**Testing Status**: Regularly tested with Zephyr RTOS v4.0.0 and Zephyr SDK v0.17.0.

### Prerequisites

- **[Zephyr RTOS](https://zephyrproject.org/)** - Real-time operating system
- **[Zephyr SDK](https://github.com/zephyrproject-rtos/sdk-ng)** - Development toolkit
- **[West](https://docs.zephyrproject.org/latest/develop/west/index.html)** - Zephyr's meta-tool for managing repositories

### Setup

ESP Serial Flasher can be integrated as a Zephyr module. Add the following to your West manifest file (`west.yml`):

```yaml
manifest:
  projects:
    - name: esp-flasher
      url: https://github.com/espressif/esp-serial-flasher
      revision: master
      path: modules/lib/esp_flasher
```

After updating the manifest, fetch the module:

```bash
west update
```

### Project Configuration

Add these configuration options to your `prj.conf`:

```text
CONFIG_ESP_SERIAL_FLASHER=y
CONFIG_CONSOLE_GETCHAR=y
CONFIG_SERIAL_FLASHER_MD5_ENABLED=y
```

### Example Code

See [examples/zephyr_example](../examples/zephyr_example) for a complete implementation with build instructions.

## Raspberry Pi Pico Setup

**Testing Status**: Regularly tested with Raspberry Pi Pico SDK v1.5.1 and arm-gnu-toolchain-13.2.

### Prerequisites

- **[Git](https://git-scm.com/)** - For cloning repositories
- **[Raspberry Pi Pico SDK](https://github.com/raspberrypi/pico-sdk)** - Development framework
- **[ARM GCC toolchain](https://developer.arm.com/Tools%20and%20Software/GNU%20Toolchain)** - Cross-compilation toolchain

### Setup

1. **Clone the repository**:

   ```bash
   git clone https://github.com/espressif/esp-serial-flasher.git
   cd esp-serial-flasher
   ```

2. **Ensure Pico SDK is available**:

   - Either set `PICO_SDK_PATH` environment variable
   - Or place the Pico SDK in a standard location

### Example Code

See [examples/pi_pico_example](../examples/pi_pico_example) for a complete implementation with build instructions.

## Raspberry Pi Setup

**Testing Status**: Regularly tested with the latest Raspberry Pi OS.

### Prerequisites

- **[Git](https://git-scm.com/)** - For cloning repositories
- **[Raspberry Pi OS](https://www.raspberrypi.org/software/)** - Latest version recommended
- **[pigpio library](https://abyz.me.uk/rpi/pigpio/)** - For GPIO control and hardware interfacing

### Setup

1. **Clone the repository**:

   ```bash
   git clone https://github.com/espressif/esp-serial-flasher.git
   ```

2. **Install pigpio library** (if not already installed):

   ```bash
   sudo apt update
   sudo apt install pigpio
   ```

### Example Code

See [examples/raspberry_example](../examples/raspberry_example) for a complete implementation with build instructions.

## Next Steps

After successful platform setup:

1. **Review the [Configuration Guide](configuration.md)** for library configuration options
2. **Check platform-specific examples** in the `examples/` directory
3. **Read the [API documentation](../README.md)** for usage details

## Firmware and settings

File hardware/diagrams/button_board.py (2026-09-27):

"""The button strip: three 12 x 12 x 4.3 mm tactile switches (Omron B3F-4000) on an 84 x 20 mm
protoboard, behind the bezel's chin. Component side (as seen from the front
of the display) and solder side (as seen from the back, mirrored), a switch
pin detail and build notes."""

from __future__ import annotations

from svgkit import COL, Svg, circled

PITCH = 2.54
STRIP_W, STRIP_H = 84.0, 20.0           # mm
CX, CY = STRIP_W / 2, STRIP_H / 2       # middle switch centre = strip centre
SW_X = [-10 * PITCH, 0.0, 10 * PITCH]   # 25.4 mm apart, the same as the caps
SW_NAMES = ["BACK", "REFRESH", "NEXT"]  # left to right, seen from the front
SW_SYMBOL = ["◀", "●", "▶"]
LEG_DX, LEG_DY = 2.5 * PITCH, PITCH     # legs 5 holes (12.7 mm) x 2 holes (5.08 mm) apart
HOLE_X = 14.5 * PITCH                   # M2.5 mounting holes: the 15th hole either side of the centre
COLS = [CX + (k + 0.5) * PITCH for k in range(-16, 16)]   # half-pitch columns, so the legs land on holes
ROWS = [CY + j * PITCH for j in range(-3, 4)]             # ROWS[3] is the switches' centre line
BUS_Y = ROWS[6]                         # ground bus on the bottom row, clear of every leg
# Where the lead's wires are soldered (front-view mm): the signals on the top row above the BACK
# switch, ground at the end of the bus. Nothing passes the screw hole at the left end.
HOLE = {"BACK": (CX - 11.5 * PITCH, ROWS[0]), "REFRESH": (CX - 10.5 * PITCH, ROWS[0]),
        "NEXT": (CX - 9.5 * PITCH, ROWS[0]), "GND": (CX - 13.5 * PITCH, BUS_Y)}
LANE = {"BACK": ROWS[0], "REFRESH": ROWS[1], "NEXT": ROWS[0]}   # row each signal wire runs along

S = 8.0                                 # px per mm
BOARD_FILL, BOARD_LINE, PAD = "#f3e3c3", "#c9a96b", "#d8b46a"


def leg(i: int, sx: int, sy: int) -> tuple[float, float]:
    """Leg of switch i: sx, sy = -1/+1 for left/right and top/bottom, front-view mm."""
    return CX + SW_X[i] + sx * LEG_DX, CY + sy * LEG_DY


def signal_leg(i):   # top left
    return leg(i, -1, -1)


def ground_leg(i):   # bottom right: diagonally opposite, so always the other contact
    return leg(i, 1, 1)


class View:
    """Maps strip mm (front view, origin top-left) to canvas px; mirrored for the solder side."""

    def __init__(self, x0: float, y0: float, mirrored: bool):
        self.x0, self.y0, self.mirrored = x0, y0, mirrored

    def __call__(self, x: float, y: float) -> tuple[float, float]:
        if self.mirrored:
            x = STRIP_W - x
        return self.x0 + x * S, self.y0 + y * S

    @property
    def top(self) -> float:
        return self.y0

    @property
    def bottom(self) -> float:
        return self.y0 + STRIP_H * S


def board(s: Svg, v: View) -> None:
    s.rect(v.x0, v.y0, STRIP_W * S, STRIP_H * S, fill=BOARD_FILL, stroke=BOARD_LINE, width=1.5, rx=4)
    for cx in COLS:
        for cy in ROWS:
            px, py = v(cx, cy)
            s.circle(px, py, 4.2, fill=PAD, stroke="none", width=0)
            s.circle(px, py, 1.6, fill="#ffffff", stroke="none", width=0)
    for sx in (-1, 1):
        px, py = v(CX + sx * HOLE_X, CY)
        s.circle(px, py, 1.35 * S, fill="#ffffff", stroke="#8a7550", width=1.2)


def names_below(s: Svg, v: View, with_refs: bool) -> None:
    for i, name in enumerate(SW_NAMES):
        px, _ = v(CX + SW_X[i], CY)
        s.text(px, v.bottom + 22, name, size=13, anchor="middle", weight="bold")
        if with_refs:
            s.text(px, v.bottom + 38, f"SW{i + 1}", size=12, anchor="middle", fill=COL["text2"])


def switches_front(s: Svg, v: View) -> None:
    for i in range(3):
        px, py = v(CX + SW_X[i], CY)
        half = 6 * S
        s.rect(px - half, py - half, 2 * half, 2 * half, fill="#2b2e33", stroke="#15171a", width=1.2, rx=3)
        s.circle(px, py, 3.5 * S, fill="#5b6068", stroke="#9aa0a8", width=1.2)
        s.text(px, py + 7, SW_SYMBOL[i], size=20, anchor="middle", fill="#ffffff")
        for sx in (-1, 1):
            for sy in (-1, 1):
                lx, ly = v(*leg(i, sx, sy))
                s.circle(lx, ly, 3.2, fill="#c0c4c9", stroke="#6b7079", width=1)


def wire(s: Svg, v: View, pts, color, width=3.2) -> None:
    s.poly([v(*p) for p in pts], stroke=color, width=width)


def solder_side(s: Svg, v: View) -> None:
    # switch legs, with the bodies seen through the board
    for i in range(3):
        px, py = v(CX + SW_X[i], CY)
        s.rect(px - 6 * S, py - 6 * S, 12 * S, 12 * S, fill="none", stroke="#8a8f98", width=1,
               stroke_dasharray="4 4", rx=3)
        s.text(px, py + 4, f"SW{i + 1}", size=12, anchor="middle", fill=COL["text2"])
        for sx in (-1, 1):
            for sy in (-1, 1):
                lx, ly = v(*leg(i, sx, sy))
                s.circle(lx, ly, 4.6, fill="#b9bec5", stroke="#5f656e", width=1.2)
    # ground: a bare bus along the bottom row, a short link from each switch's ground leg
    far = max(ground_leg(i)[0] for i in range(3))
    wire(s, v, [HOLE["GND"], (far, BUS_Y)], COL["gnd"], width=3.6)
    for i in range(3):
        x, y = ground_leg(i)
        wire(s, v, [(x, y), (x, BUS_Y)], COL["gnd"], width=3.6)
        s.dot(*v(x, BUS_Y), COL["gnd"], r=4.5)
        s.dot(*v(x, y), COL["gnd"], r=4.2)
    # signals: insulated wire from each switch's top-left leg to its hole
    for i, name in enumerate(SW_NAMES):
        lx, ly = signal_leg(i)
        hx, hy = HOLE[name]
        wire(s, v, [(lx, ly), (lx, LANE[name]), (hx, LANE[name]), (hx, hy)], COL["btn"], width=3.2)
        s.dot(*v(lx, ly), COL["btn"], r=4.2)
    for name, (hx, hy) in HOLE.items():
        s.circle(*v(hx, hy), 5.4, fill="#ffffff", stroke=COL["gnd" if name == "GND" else "btn"], width=2.4)


def lead(s: Svg, v: View) -> float:
    """The lead: signal wires off the top edge, ground round the end of the strip.
    Returns the x of the ground wire."""
    top_y = v.top - 46
    for name in SW_NAMES:
        hx, hy = v(*HOLE[name])
        s.poly([(hx, hy), (hx, top_y)], stroke=COL["btn"], width=2.6)
        s.text(hx + 4, top_y - 4, name, size=12, anchor="start", weight="bold", rotate=-90)
    gx, gy = v(*HOLE["GND"])
    x_gnd = v.x0 + STRIP_W * S + 18
    s.poly([(gx, gy), (x_gnd, gy), (x_gnd, top_y)], stroke=COL["gnd"], width=2.6)
    s.text(x_gnd + 4, top_y - 4, "GND", size=12, anchor="start", weight="bold", rotate=-90)
    left = min(v(*HOLE[n])[0] for n in SW_NAMES)
    s.text(left - 16, v.top - 36, "4-wire lead, about 7 cm, to one half of a 4-pin JST-PH pair (J4):",
           size=12.5, anchor="end", fill=COL["text2"])
    s.text(left - 16, v.top - 18, "pin 1 BACK, then REFRESH, NEXT, GND. The other half goes on to J3.",
           size=12.5, anchor="end", fill=COL["text2"])
    return x_gnd


def switch_detail(s: Svg, x: float, y: float) -> None:
    """One 12 x 12 mm switch from its component side: legs and contacts."""
    k = 9.0   # px per mm
    s.text(x, y, "One switch (12 × 12 × 4.3 mm), component side", size=15, weight="bold")
    cx, cy = x + 190, y + 120
    half = 6 * k
    s.rect(cx - half, cy - half, 2 * half, 2 * half, fill="#2b2e33", stroke="#15171a", width=1.2, rx=4)
    s.circle(cx, cy, 3.5 * k, fill="#5b6068", stroke="#9aa0a8", width=1.2)
    dy = 2.5 * k
    reach = 6.25 * k
    for sx in (-1, 1):
        for sy in (-1, 1):
            lx, ly = cx + sx * reach, cy + sy * dy
            s.circle(lx, ly, 5, fill="#c0c4c9", stroke="#6b7079", width=1.2)
            s.text(lx + sx * 13, ly + 4.5, "A" if sy < 0 else "B", size=13, anchor="start" if sx > 0 else "end",
                   weight="bold")
    for sy in (-1, 1):   # the pairs joined inside the switch
        s.line(cx - reach + 6, cy + sy * dy, cx + reach - 6, cy + sy * dy, stroke="#e0b64a", width=1.8,
               stroke_dasharray="5 4")
    s.dimension(cx - reach, cy + half + 20, cx + reach, cy + half + 20, "12.5 mm (5 holes)", size=12)
    s.dimension(cx + reach + 40, cy - dy, cx + reach + 40, cy + dy, "5 mm (2 holes)", size=12)
    s.lines(x, cy + half + 62, [
        "A–A and B–B are joined inside the switch (dashed); pressing it",
        "joins A to B. Two diagonally opposite legs are always A and B,",
        "whichever way round the switch is fitted.",
    ], size=12.5, fill=COL["text2"])


def build() -> str:
    W, H = 1400, 880
    s = Svg(W, H, "brwr-trmnl v1 button board",
            "Three 12 by 12 millimetre tactile switches on an 84 by 20 millimetre protoboard strip: the component "
            "side seen from the front, and the solder side seen from the back with a ground bus and three signal "
            "wires to a four-wire lead.")
    s.text(40, 44, "brwr-trmnl v1 — button board", size=22, weight="bold")
    s.text(40, 70, "84 × 20 mm protoboard behind the bezel's chin. Three Omron B3F-4000 switches (12 × 12 × "
                   "4.3 mm, flat plunger), no resistors (the ESP32-S3's pull-ups). Both views at the same scale.",
           size=13.5,
           fill=COL["text2"])

    # --- component side ---------------------------------------------------
    front = View(60, 150, mirrored=False)
    s.text(60, 112, "Component side, as seen from the front of the display", size=15, weight="bold")
    board(s, front)
    switches_front(s, front)
    names_below(s, front, with_refs=True)
    s.dimension(front.x0, front.top - 14, front.x0 + STRIP_W * S, front.top - 14, "84 mm", size=12)
    s.dimension(front.x0 + STRIP_W * S + 16, front.top, front.x0 + STRIP_W * S + 16, front.bottom, "20 mm",
                size=12)
    y_sw = front.bottom + 62
    s.dimension(front(CX + SW_X[0], 0)[0], y_sw, front(CX, 0)[0], y_sw, "25.4 mm", size=12)
    s.dimension(front(CX, 0)[0], y_sw, front(CX + SW_X[2], 0)[0], y_sw, "25.4 mm", size=12)
    y_holes = front.bottom + 96
    s.dimension(front(CX - HOLE_X, 0)[0], y_holes, front(CX + HOLE_X, 0)[0], y_holes,
                f"{2 * HOLE_X:.1f} mm (29 pitches) between the Ø2.7 mm holes", size=12)
    px_mid, _ = front(CX, CY)
    circled(s, px_mid + 52, front.bottom + 30, 1)
    rx_, ry_ = front(*leg(2, 1, 1))
    circled(s, rx_ + 22, ry_ + 30, 2)
    hx, hy = front(CX - HOLE_X, CY)
    circled(s, hx, hy - 26, 3)

    # --- solder side --------------------------------------------------------
    back = View(60, 560, mirrored=True)
    s.text(60, 452, "Solder side, as seen from the back (left and right swapped)", size=15, weight="bold")
    board(s, back)
    solder_side(s, back)
    x_lead = lead(s, back)
    names_below(s, back, with_refs=False)
    lx_, ly_ = back(*signal_leg(1))
    circled(s, lx_ - 20, ly_ - 18, 4)
    circled(s, x_lead + 24, back.top - 30, 5)
    bus_end = back(max(ground_leg(i)[0] for i in range(3)), BUS_Y)   # far end of the bus
    s.line(bus_end[0], bus_end[1], bus_end[0], back.bottom + 44, stroke=COL["gnd"], width=1, stroke_dasharray="3 3")
    s.text(bus_end[0] - 4, back.bottom + 60, "GND bus: bare wire along the bottom row", size=12.5, weight="bold",
           fill=COL["gnd"])

    # --- right column: detail, notes, legend ------------------------------------
    switch_detail(s, 860, 112)
    notes = [
        "① The middle switch sits at the strip's centre, the others 10 holes",
        "    (25.4 mm) either side, the same spacing as the caps.",
        "② Push each switch flat onto the board; spread the legs slightly to",
        "    fit the grid. Trim the legs to 2 mm under the board after soldering.",
        "③ Drill out the 15th hole either side of the centre, on the middle",
        "    row (the second hole in from each end), to 2.7 mm for the M2.5",
        "    screws into the bezel's inserts.",
        "④ Signal: each switch's top-left leg (front view), insulated wire to",
        "    its hole above BACK. Ground: the diagonally opposite leg, to the bus.",
        "⑤ The lead leaves at the left end (front view), to its inline plug",
        "    beside the adapter board. Keep the wires clear of the screw holes.",
        "The buttons pull D0, D1 and D2 (GPIO1–3) to ground. These are RTC",
        "pins, so any press wakes the display from deep sleep.",
    ]
    s.note_box(860, 400, 500, "Notes", notes, size=12.5, lh=19)
    s.legend(860, 700, keys=["gnd", "btn"], title="Colour code", col_w=300)
    s.text(W - 40, H - 18, "Regenerate: python3 hardware/diagrams/make_diagrams.py button-board", size=12,
           anchor="end", fill=COL["text2"])
    return s.render()


if __name__ == "__main__":
    print(build())

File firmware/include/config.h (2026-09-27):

#ifndef CONFIG_H
#define CONFIG_H
#include <stdint.h>

#define FW_MAJOR_VERSION 1
#define FW_MINOR_VERSION 8
#define FW_PATCH_VERSION 16

// Helper macros for stringification
#define STRINGIFY(x)     #x
#define TOSTRING(x)      STRINGIFY(x)

#ifndef FW_COMMIT
#define FW_COMMIT ""
#endif

// Compile-time firmware version string
#define FW_VERSION_STRING    TOSTRING(FW_MAJOR_VERSION) "." TOSTRING(FW_MINOR_VERSION) "." TOSTRING(FW_PATCH_VERSION)

#define LOG_MAX_NOTES_NUMBER 10

#define PREFERENCES_API_KEY  "api_key"
#define PREFERENCES_API_KEY_DEFAULT          ""
#define PREFERENCES_API_URL                  "api_url"
#define PREFERENCES_FRIENDLY_ID              "friendly_id"
#define PREFERENCES_FRIENDLY_ID_DEFAULT      ""
#define PREFERENCES_HOSTNAME                 "hostname"
#define PREFERENCES_TEMP_PROFILE             "temp_profile"
#define PREFERENCES_LOG_KEY                  "log_"
#define PREFERENCES_LOG_BUFFER_HEAD_KEY      "log_head"
#define PREFERENCES_LOG_ID_KEY               "log_id"
#define PREFERENCES_DEVICE_REGISTERED_KEY    "plugin"
#define PREFERENCES_SF_KEY                   "sf"
#define PREFERENCES_FILENAME_KEY             "filename"
#define PREFERENCES_CURRENT_PATH_KEY         "curr_path"
#define PREFERENCES_LAST_PATH_KEY            "last_path"
#define PREFERENCES_PLAYLIST_ORDER_KEY       "playlist_order"
#define PREFERENCES_BROWSE_PATH_KEY          "browse_path"
#define MAX_CACHED_IMAGES                    30
#define PREFERENCES_LAST_SLEEP_TIME          "last_sleep"
#define PREFERENCES_CONNECT_API_RETRY_COUNT  "retry_count"
#define PREFERENCES_CONNECT_WIFI_RETRY_COUNT "wifi_retry"
#define PREFERENCES_TOUCHBAR_MODE_KEY        "touchbar_mode"
#define PREFERENCES_LAST_OTA                 "last_ota"

#define WIFI_CONNECTION_RSSI                 (-100)

#define DISPLAY_BMP_IMAGE_SIZE 48062 // in bytes - 62 bytes - header; 48000 bytes - bitmap (480*800 1bpp) / 8
#define DEFAULT_IMAGE_SIZE     48000
#if defined(BOARD_HAS_PSRAM)
#define MAX_IMAGE_SIZE 750000 // Use PSRAM on the ESP32-S3/C5 (all X-class boards have PSRAM)
#else
#define MAX_IMAGE_SIZE 90000 // largest compressed image we can receive in static RAM
#endif
#define SLEEP_uS_TO_S_FACTOR 1000000           /* Conversion factor for micro seconds to seconds */

// Different display profiles
#define TEMP_PROFILE_DEFAULT 0
#define TEMP_PROFILE_A       1
#define TEMP_PROFILE_B       2
#define TEMP_PROFILE_C       3

#define MS_TO_S_FACTOR       1000 /* Conversion factor for milliseconds to seconds */

#if defined(BOARD_TRMNL_X)
#define PIN_INTERRUPT      3
#define PIN_INTERNAL_SDA   39
#define PIN_INTERNAL_SCL   40
#define PIN_INTERNAL_READY GPIO_NUM_3
// TCA9535 expander pins for the BQ25616 charger (open-drain, LOW = active)
#define TCA9535_PG_PIN     0 // P0_0 — LOW = VBUS OK
#define TCA9535_STAT_PIN   2 // P0_2 — LOW = charging in progress
#elif defined(BOARD_TRMNL_X_EPDIY)
#define PIN_INTERRUPT 0
#define DEVICE_MODEL  "x"
#elif defined(BOARD_TRMNL_X_SENSORIAS3)
#define PIN_INTERRUPT 0
#define DEVICE_MODEL  "sensoria_s3"
#define SENSOR_SDA    39
#define SENSOR_SCL    40
#elif defined(BOARD_ESP32_C5_DEVKITC_1)
#define PIN_INTERRUPT 28
#define DEVICE_MODEL  "gen-2"
#elif defined(BOARD_WAVESHARE_ESP32_DRIVER)
#define PIN_INTERRUPT 33
#define DEVICE_MODEL  "waveshare"
#define FAKE_BATTERY_VOLTAGE
#elif defined(BOARD_SEEED_XIAO_ESP32C3)
#define DEVICE_MODEL "seeed_esp32c3"
#define PIN_INTERRUPT                                                                                                  \
  9 // the boot button on the XIAO ESP32-C3, this button can't be used as wakeup  source though
                        // because it's not in the RTC GPIO group. Instead, you can always use the reset button to
// wake up the device. Resetting WiFi configuration needs special routine - press reset button
// then press the boot button in less than 2 seconds, and hold it for 5 seconds.
#define FAKE_BATTERY_VOLTAGE
#elif defined(BOARD_SEEED_XIAO_ESP32S3)
#define DEVICE_MODEL  "seeed_esp32s3"
#define PIN_INTERRUPT 0 // the boot button on the XIAO ESP32-S3, this button works as regular wakeup button
#define FAKE_BATTERY_VOLTAGE
#elif defined(BOARD_BRWR_TRMNL)
#define PIN_INTERRUPT 2 // centre (refresh) button; the other two are in brwr/board.h
#endif

// DHCP hostname prefix (hyphens instead of spaces).
#if defined(BOARD_BRWR_TRMNL)
#define WIFI_CLIENT_HOSTNAME_PREFIX "brwr-trmnl"
#elif defined(PARALLEL_EPD)
#define WIFI_CLIENT_HOSTNAME_PREFIX "TRMNL-X"
#elif defined(BOARD_TRMNL) || defined(BOARD_TRMNL_GEN2)
#define WIFI_CLIENT_HOSTNAME_PREFIX "TRMNL-OG"
#elif defined(BOARD_TRMNL_4CLR)
#define WIFI_CLIENT_HOSTNAME_PREFIX "TRMNL-BWRY"
#else
#define WIFI_CLIENT_HOSTNAME_PREFIX "TRMNL"
#endif
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

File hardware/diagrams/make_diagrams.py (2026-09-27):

#!/usr/bin/env python3
"""Regenerate the brwr-trmnl hardware diagrams in docs/images/.

    python3 hardware/diagrams/make_diagrams.py            # all diagrams
    python3 hardware/diagrams/make_diagrams.py wiring     # just one

Standard library only. The drawings are plain SVG with a white background, so
they read the same in GitHub's light and dark themes.
"""

from __future__ import annotations

import importlib
import sys
from pathlib import Path

HERE = Path(__file__).resolve().parent
OUT = HERE.parent.parent / "docs" / "images"

# output name -> generator module (each has build() -> str)
DIAGRAMS = {
    "schematic": "schematic",
    "wiring": "wiring",
    "carrier-layout": "carrier",
    "button-board": "button_board",
}


def main(argv: list[str]) -> int:
    sys.path.insert(0, str(HERE))
    wanted = argv or list(DIAGRAMS)
    OUT.mkdir(parents=True, exist_ok=True)
    for name in wanted:
        if name not in DIAGRAMS:
            print(f"unknown diagram {name!r}; choose from {', '.join(DIAGRAMS)}", file=sys.stderr)
            return 2
        svg = importlib.import_module(DIAGRAMS[name]).build()
        path = OUT / f"{name}.svg"
        path.write_text(svg, encoding="utf-8")
        print(f"wrote {path.relative_to(HERE.parent.parent)} ({len(svg) // 1024} KiB)")
    return 0


if __name__ == "__main__":
    sys.exit(main(sys.argv[1:]))

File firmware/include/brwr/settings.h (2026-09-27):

#pragma once
//
// Settings for the Home Assistant side of brwr-trmnl, kept in their own NVS
// namespace ("brwr") so they survive upstream changes to the "data" namespace.
// The setup page writes the connection details; Home Assistant changes the
// rest over MQTT (retained messages, applied at the next wake).
//
#ifdef BOARD_BRWR_TRMNL

#include <Arduino.h>
#include <ArduinoJson.h>

namespace brwr {

  // Where scheduled screens come from.
  enum class Source : uint8_t {
    Trmnl = 0,         // TRMNL server: Terminus add-on, TRMNL cloud or any BYOS server
    HomeAssistant = 1, // Home Assistant dashboards rendered by the TRMNL HA add-on
  };

  enum class PowerMode : uint8_t {
    AlwaysReady = 0, // Wi-Fi stays associated in light sleep; commands land in seconds
    DeepSleep = 1,   // longest battery life; commands wait for the next wake
  };

  enum class ButtonMode : uint8_t {
    Local = 0,             // buttons change screens and also fire Home Assistant triggers
    HomeAssistantOnly = 1, // buttons only fire Home Assistant triggers
  };

  constexpr uint8_t kMaxScreens = 12;
  constexpr uint16_t kDefaultAddonPort = 10000; // TRMNL HA add-on (dashboard screenshots)
  constexpr uint16_t kDefaultTerminusPort = 2300;
  constexpr uint16_t kDefaultMqttPort = 1883;
  constexpr uint16_t kDefaultHaRefreshMinutes = 30; // Home Assistant screens, when not set

  struct Screen {
    String name; // shown in Home Assistant and matched by voice commands
    String path; // dashboard path for the TRMNL HA add-on, or a full http(s) image URL
  };

  struct Settings {
    // Connection (setup page)
    String haHost;    // Home Assistant address, e.g. 192.168.1.20
    String mqttHost;  // empty = haHost
    uint16_t mqttPort = kDefaultMqttPort;
    String mqttUser;
    String mqttPass;
    uint16_t addonPort = kDefaultAddonPort;

    // Behaviour (Home Assistant)
    Source source = Source::Trmnl;
    PowerMode power = PowerMode::AlwaysReady;
    ButtonMode buttons = ButtonMode::Local;
    uint16_t refreshMinutes = 0; // 0 = automatic (server's rate, or 30 min for HA screens)
    uint16_t holdMinutes = 60;   // how long a screen shown on command stays up
    uint16_t vcomMv = 0;         // panel VCOM in mV without the minus sign; 0 = driver default (1500)

  // Home Assistant screens
    Screen screens[kMaxScreens];
    uint8_t screenCount = 0;
    uint8_t currentScreen = 0;
  };

  Settings &settings();
  void settings_load();

  // Persist individual groups after a change.
  void settings_save_connection();
  void settings_save_behaviour();
  void settings_save_screens(const String &json);
  void settings_save_current_screen();
  void settings_clear(); // the 15-second reset: back to defaults

  // Parses the JSON list Home Assistant publishes:
  // [{"name":"Calendar","path":"fridge-dashboard/calendar"}, ...]
  bool settings_parse_screens(const String &json);
  String settings_screens_json(); // last accepted list, as stored

  bool mqtt_configured();
  String mqtt_host();

  // Image URL for a screen: full URLs pass through; dashboard paths become a
  // TRMNL HA add-on URL rendering 1872x1404 at 16 grays.
  String screen_url(const Screen &screen);
  String dashboard_url(const String &path);
  int find_screen(const String &name); // case-insensitive, -1 if not found

// Setup page (lib/wificaptive): current values as JSON, and saving the form.
  String portal_settings_json();
  void portal_save(JsonObject ha);

  const char *source_name(Source source);
  const char *power_name(PowerMode power);
  const char *button_mode_name(ButtonMode mode);

} // namespace brwr

#endif // BOARD_BRWR_TRMNL

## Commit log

2026-09-26 Add README for a 10.3" TRMNL-compatible Home Assistant display
    Specification for a large-format e-paper dashboard built from
    off-the-shelf parts (Waveshare 10.3" IT8951 HAT, XIAO ESP32S3), running
    a fork of the TRMNL firmware with Home Assistant set up in the firmware:
    Terminus or HA-dashboard image sources and an MQTT discovery device.
2026-09-26 Squashed 'firmware/' content from commit f5f87b7
    git-subtree-dir: firmware
    git-subtree-split: f5f87b7bed5ced8a2768988fd25be1028c58334a
    [min_spiffs.csv, trmnl_gen2_partitions.csv, trmnl_x_partitions.csv]
2026-09-26 firmware: add the brwr_trmnl board with buttons and Home Assistant
    New board for a Seeed XIAO ESP32-S3 driving the Waveshare 10.3" e-Paper
    HAT (IT8951 over SPI, 1872x1404, 16 grays). It reuses upstream's FastEPD
    IT8951 path from the reTerminal E1003 and adds:
    - pins, an 8 MB partition table, and an sdkconfig with power management
    so the device can light-sleep with Wi-Fi associated
    - per-panel VCOM and a 12 MHz SPI clock for hand-wired jumpers
    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
    [brwr_trmnl_8MB.csv]
2026-09-26 firmware: Home Assistant fields on the setup page
    The setup page asks for the Home Assistant address, where screens come
    from (Terminus or Home Assistant dashboards), MQTT login and the panel
    VCOM, and fills in the Terminus server address (port 2300) itself. The
    section only appears when /device-settings reports it, so other boards
    see the upstream page unchanged. The hotspot is named brwr-trmnl-XXXXXX.
    Claude-Session: https://claude.ai/code/session_01MKGFRfWxqGDrBjvDr5DxNv
2026-09-26 ci: build the brwr_trmnl firmware
    Builds brwr_trmnl (Arduino on ESP-IDF, with light sleep) and
    brwr_trmnl_arduino on every change under firmware/, and uploads the
    merged image for flashing at 0x0.
    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
2026-09-26 firmware: take screens, show and cmd from brwr-trmnl/all
    The Home Assistant package publishes to brwr-trmnl/all/..., which every
    display listens to, so it needs no device id. show and cmd carry a
    timestamp: each display acts on a timestamp once and skips stale ones,
    and a held screen ends at timestamp + hold, however late it was seen.
    Per-device topics still win and are still deleted once handled.
    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
2026-09-26 firmware: list the embedded certificates for the ESP-IDF build
    PlatformIO needs the certificate files that the Arduino component's
    managed components embed, as upstream's ESP-IDF environments list them;
    without them the brwr_trmnl build stops at https_server.crt.S. Also move
    CI to the action versions upstream uses.
    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
2026-09-26 firmware: clear the Home Assistant settings on the 15-second reset
    Upstream's reset forgets Wi-Fi and the TRMNL server but not the brwr
    namespace, so a reset display kept its Home Assistant address, MQTT login
    and VCOM. Clear it too.
    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
    [settings.h]
2026-09-26 docs: build guide, BOM, wiring, power, magnets, voice and Home Assistant
    - README: rewritten for the fridge build: three buttons, magnets, voice,
    the MiniBoost and charger module, the current pin map and layout.
    - docs/build-guide.md: printing, carrier and button boards, battery
    polarity, flashing, bench test, assembly, hanging, troubleshooting.
    - docs/bom.md and hardware/bom.csv: $234.24, with suppliers and which
    prices were checked.
    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
    [bom.csv]
2026-09-26 docs: printed standoffs, countersunk M3 screws, current esptool syntax
    The back cover prints the driver HAT's standoffs with inserts, so the
    brass standoffs go ($233.24 now). The back-cover screws must be
    countersunk: a raised head would hold the magnets off the door.
    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
    [bom.csv]
2026-09-26 firmware: ignore a button that's stuck down
    A button still held after 30 s is now "stuck", not a reset: it does
    nothing, is left out of the deep-sleep and light-sleep wake-ups (its low
    level would wake the device again at once), and is reported as the last
    error until a wake finds it released. Before, a cap pressing its switch
    would have reset the display and kept waking it. A deliberate reset is
    now a hold of 15 to 30 s.
    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
    [board.cpp, sleep.cpp]
2026-09-26 hardware: parametric OpenSCAD enclosure for the fridge
    brwr-trmnl.scad, 229 x 204 x 25 mm, two printed parts plus button caps
    and an optional desk stand, all printable without supports on a
    250 x 210 mm bed:
    - bezel: front face, chamfered window, panel pocket with flex relief,
    walls, M3 insert bosses, button caps with anti-rotation keys, USB-C
    slots and an antenna recess in the top wall
    - back cover: panel-support ribs, printed driver-HAT standoffs, carrier
    tray, battery cradle, wire tie blocks, keyholes, and four pockets for
    22 mm rubber-coated pot magnets at (+-90, +-65), screwed from inside
    assert() design rules check every clearance: magnets at least 36 mm
    (centre) from the dri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
    [back.stl, bezel.stl, brwr-trmnl.scad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]
2026-09-26 docs: match the finished enclosure
    PETG from the enclosure's volumes (350 g), zip ties for the button wires,
    the magnets' parameter is now mag_pos, the caps' keys go to the bottom,
    and the device weighs about 0.55 kg, so the magnets hold with ~4.5x
    margin against sliding. $235.44 in all.
    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
    [bom.csv]
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2026-09-26 hardware: carrier board layout and wiring overview
    - carrier-layout.svg: the 70 x 35 mm protoboard from the component side,
    with the same left and right as the front, as it sits in the back
    cover. MiniBoost at the left, the XIAO's and the charger's USB-C at
    the slots' X (-8, +22), J2 for the HAT beside the XIAO's SPI pins and
    J3 for the buttons beside D0-D2, the mounting holes where the
    enclosure puts them, a pin table for J1-J3 and the parts' heights.
    - wiring.svg: everything in place, seen from the back with the cover
    off: battery, HAT, carrier, antenna and coax, flex zone, button
    board, the magnets' 36 mm keep-out circles and the five cables.
    - schematic.svg: closes a gap in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
    [carrier.py, schematic.py, wiring.py]
2026-09-26 docs: solder the XIAO flat, right-angle headers, 20 cm button lead
    From the carrier layout: the XIAO and the charger must sit flat for
    their USB-C to meet the slots, plugs on straight pins would stand
    ~15 mm where the case leaves 9 mm, C3 lies flat or is low-profile, the
    XIAO's BAT- pad is already GND, and the button lead needs ~20 cm.
    The wiring notes also say how the firmware keeps the unpowered HAT
    from being fed through its inputs.
    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
    [bom.csv]
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2026-09-26 hardware: 13 mm enclosure in parts that fit a 220 x 220 bed
    The case was 25 mm deep and 229 mm wide, too thick next to the TRMNL X
    (12 mm) and too big for a 220 x 220 bed. Now 229 x 204 x 13 mm:
    - Frame in four rails: the top rail and the chin run the full width with
    both corners, the side rails fit between them, joined level with the
    window's top and bottom edges (scarf and half-lap, V-grooved on the
    front). The long rails print at 45 degrees.
    - Back cover in two halves, split at X = -39 with a scarf and three tabs.
    - Low parts: the HAT's Pi header cut off and the HAT on 1.5 mm
    standoffs, the carrier and the battery in recesses, B3F-4000 flat
    switches, a 45 x 7 mm FXP831 antenna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
    [back.stl, back_left.stl, back_right.stl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]
2026-09-26 docs: build the thin enclosure
    - BOM ($239.98): FXP831 antenna, B3F-4000 switches, 20 x 3 mm N52
    discs with steel backing and rubber pads, 3 mm steel rod and epoxy,
    ceramic C2/C3, a JST-PH pigtail, nine M3 screws, less PETG.
    - Build guide: four print jobs on 220 x 220, preparing the HAT (cut the
    Pi header, take off the 8-pin socket, solder the wires), keeping the
    carrier low, bending and epoxying the rods, setting the magnets, and
    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
    [bom.csv]
2026-09-26 hardware: vertex-exact enclosure meshes, checked on export
    Four STLs had vertices one float32 step apart (bezel_bottom, back_right
    and both one-piece parts), which a slicer merges into bad edges and
    zero-area triangles:
    - the button sleeves were a 3D union of a cylinder and the keyway
    block; they are now one extruded 2D outline
    - the carrier tray rim was a 2D outline, which OpenSCAD snaps to a
    1/65536 mm grid, so it missed the 3D recess by a few microns; it is
    now built from 3D boxes, and box() puts its corners exactly on lo/hi
    export.sh now merges each STL's vertices within 1e-4 mm and fails on
    any edge not shared by exactly two faces, a repeated directed edge, or
    a degenerate trian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
    [back.stl, back_left.stl, back_right.stl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]
2026-09-27 hardware: screws and buttons on the protoboard grid, ledge notch, button plug
    - Carrier screws move to the middle of its corner squares of four holes
    (X +-31.75; 4.15 and 32.09 mm below its top edge), where a 2.7 mm drill
    centres itself; bosses 6.0 mm so they clear the joints one hole out.
    - The strip's screws are its own holes at +-36.83 (was +-38, between
    holes), and the buttons are 25.4 mm (10 holes) apart (was 26).
    - A notch in the carrier's left ledge clears the MiniBoost's VIN joint,
    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
    [back.stl, back_right.stl, bezel.stl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]
2026-09-27 docs: solder J2/J3, inline JST-PH plug on the button lead, 9 x 15 cm board
    - J2 and J3 have no room for connectors on the carrier: their wires solder
    straight in. The button lead gets a 4-pin JST-PH pair (J4) instead, so
    the frame and the back cover come apart. Drawings, BOM, build guide and
    wiring notes now all say the same.
    - A 5 x 7 cm protoboard is too short for the carrier (27 holes) or the
    84 mm strip: the BOM now lists one 9 x 15 cm board for both.
    - The build guide cuts the boards by hole count, drills the mounting holes
    on the grid, and lists the 2.7 mm drill in the tools.
    - Carrier, wiring, button board and schematic drawings regenerated.
    - BOM total $240.88.
    Co-Authored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
    [bom.csv]
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2026-09-27 firmware: make buttons, settings and Wi-Fi loss behave as documented
    Found while checking the docs against the code:
    - In "Home Assistant only" button mode, a short or double REFRESH press in
    Always ready still restarted the display into a refresh. Now only the
    setup and reset holds act; the rest are just Home Assistant triggers.
    A double press only restarts for TRMNL's special function, which needs
    the TRMNL server.
    - A button stuck down kept its light-sleep wake-up armed, so it kept
    waking the chip until the next refresh. Its wake-up is now disabled too.
    - Buttons and Hold changes from Home Assistant weren't reported back while
    idling, so Home Assistant's controls snapped back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
    [sleep.cpp]
2026-09-27 docs: correct the README, power, Home Assistant and voice guides
    Checked claim by claim against the firmware, the package and the add-ons'
    own documentation:
    - power.md: the HAT is powered for the whole wake, not just the draw; the
    per-refresh rows add up to 0.26-0.46 mAh, and the 0.5-0.9 mAh budget is
    now explained; 15-minute deep sleep lasts 7-12 weeks, not 2-3 months;
    button and command latencies; deep sleep drops stale voice commands;
    the Arduino build idles at ~25 mA.
    - README and BRWR.md: the merged image is for a first flash (it clears
    NVS), updates go through PlatformIO or firmware.bin at 0x10000; REFRESH
    hold 5 s forgets the Wi-Fi; buttons in deep sleep; CI runs on firmw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
2026-09-27 hardware: antenna on the back cover, room for the MiniBoost, battery-lead gap
    From checking the build guide against the model:
    - The antenna was stuck to the frame's top wall, but its 100 mm coax plugs
    into the XIAO on the back cover: with the case open they are about
    275 mm apart. It now sticks to a fin on the back cover, just inside the
    top wall (2.4 mm in, 1.4 mm further back, still on edge away from the
    door), so it and the XIAO are on the same part. The wall's recess and
    the rim cut-out are gone. The magnet-to-antenna rule is 30 mm (was 35);
    metal is still kept 10 mm away. The coax notch in the top rib is 4 mm.
    - The MiniBoost is 5.6 mm tall (Adafruit's figure), not 5 mm: th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
    [back.stl, back_right.stl, bezel.stl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]
2026-09-27 docs: assembly order, cable routes and parts from the hardware audit
    - Build guide: the antenna goes on the back cover's fin; the flat cable and
    J4 are connected with the cover propped open at about 45 degrees (the
    flat cable needs about 10 cm); the strip's J4 lead is 7 cm; the carrier's
    top edge is cut along a row of holes (a wire runs in that margin); the
    charger module sits level with the XIAO and is glued down; SW4 is a
    wire link and is required; the MiniBoost (5.6 mm) is the tallest part;
    the panel stays boxed until step 8 and its flex is folded, not creased;
    what to unplug before assembly; how to update firmware without losing
    settings; tools for the screws and nuts.
    -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
    [bom.csv]
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
